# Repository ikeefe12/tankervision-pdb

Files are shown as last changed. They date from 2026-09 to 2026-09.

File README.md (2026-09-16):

# TankerVision Power Distribution Board

A four-layer KiCad power distribution board (PDB) for the TankerVision robot. It
accepts USB-C PD or an 18.5–20 V DC barrel-jack input, maintains a
supercapacitor-backed rail so an onboard NVIDIA Jetson can shut down cleanly after
input loss, and exposes four independently protected, firmware-controlled output
ports.

Designed in KiCad 9.0.7. Revision 1.0 was fabricated and assembled by JLCPCB in
August 2026.

| | |
|---|---|
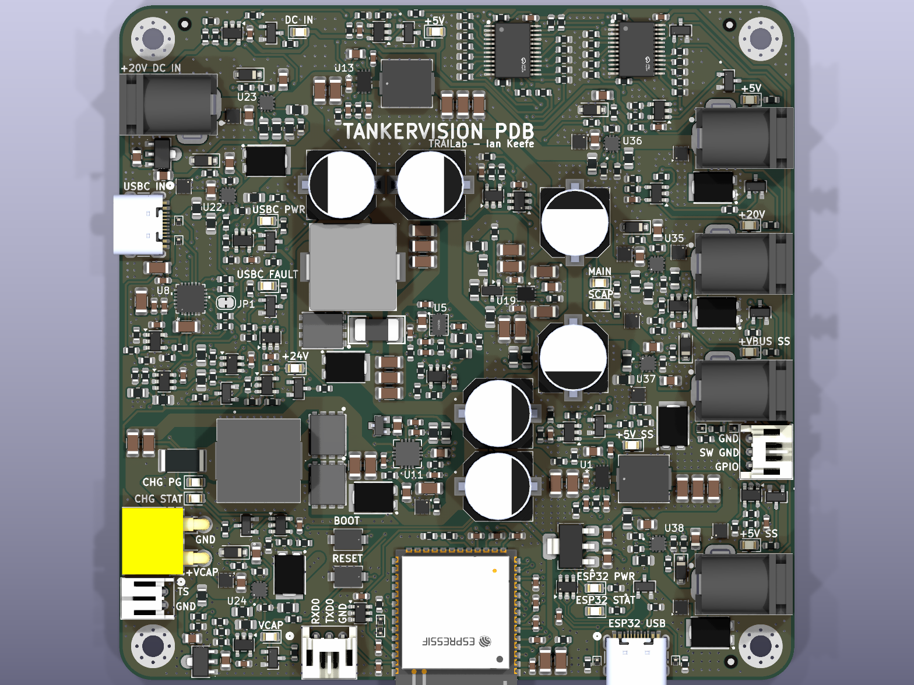
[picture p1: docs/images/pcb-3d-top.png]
PCB top
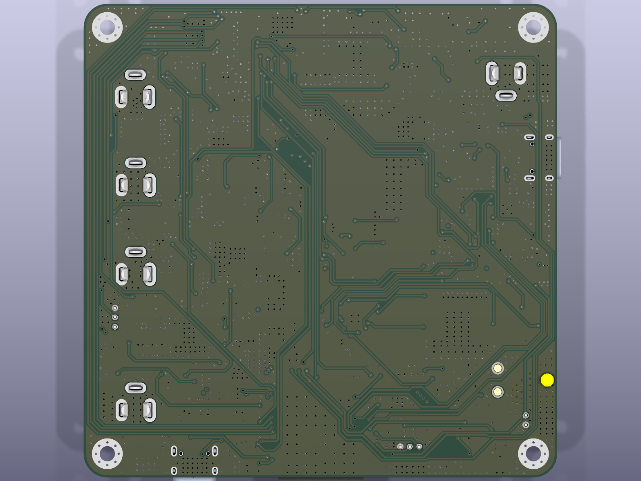
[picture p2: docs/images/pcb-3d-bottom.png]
PCB bottom
|  |  |

## Highlights

- **Dual redundant input** — USB-C PD (CYPD3177 requesting 20 V) and a DC barrel
  jack are ORed through two reverse-blocking LM73100 ideal-diode switches.
- **Supercapacitor backup** — a BQ24640 charges an external bank through a 24.5 V
  LM5155 boost; a TPS2121 priority mux transfers the backed `+VBUS_SS` domain to the
  bank in roughly 5 µs when the input rail collapses.
- **Orderly shutdown** — the backed rails feed the ESP32-S3, which sheds loads,
  pulses the Jetson power button, and watches stored energy on the supercap ADC
  divider to decide when to commit to shutdown.
- **Firmware-independent boot** — input switch → mux IN1 → `+VBUS_SS` → 5 V buck →
  3.3 V LDO brings up the ESP32-S3 with no firmware involvement; every other load
  rail is deliberately under software control.
- **Protected outputs** — four LM73100 output switches provide inrush control,
  reverse blocking, power-good, and current monitoring per port.
- **Full supervision** — fourteen TLV7031 comparators condition status signals and
  two TCA9535 I²C expanders carry enables and status back to the ESP32-S3.

## Board summary

| Item | Value |
|---|---|
| Outline | 100 mm × 100 mm |
| Stackup | 4-layer, 1.6 mm FR-4, 35 µm (1 oz) copper on all layers |
| Planes | In1.Cu solid GND; In2.Cu predominantly GND with selected routing |
| References | 452 in schematic and PCB, matched one-to-one |
| Production BOM | 444 fitted references in 84 orderable groups |
| Input | USB-C PD, or 18.5–20 V DC barrel jack |
| Outputs | 4 protected ports (`+VBUS`, `+5V_VBUS`, `+VBUS_SS`, `+5V_SS`) |
| Controller | ESP32-S3-WROOM-1-N8R8 |

## Documentation

The design is documented per functional block, with schematic labels rather than
drawing coordinates used as the stable way to locate each circuit.

- **[docs/README.md](docs/README.md)** — start here: block index and power-rail table
- **[docs/system-architecture.md](docs/system-architecture.md)** — power flow, control
  and status map, ESP32 pin map, sequencing
- **[docs/pcb-layout.md](docs/pcb-layout.md)** — layout review, stackup, routing,
  fabrication decisions, revision-1.0 order record
- **[docs/issues.md](docs/issues.md)** — open design concerns and pre-deployment
  bench checks
- **[docs/blocks/](docs/blocks/)** — sixteen per-block documents covering USB-PD,
  inrush control, the power mux, the supercap charger and switch, the boost and
  bucks, LDOs, output switches, the ESP32, I/O expanders, comparators, analog
  switches, the Jetson power button, and ADC monitoring

Firmware and board verification:

- **[firmware/deployment/README.md](firmware/deployment/README.md)** — automatic
  startup, supercap maintenance charging, 1 Hz USB telemetry and fixed 60-second
  Jetson shutdown/reboot sequence
- **[firmware/deployment/API.md](firmware/deployment/API.md)** — Jetson USB API,
  with a [Python reference client](firmware/deployment/jetson/README.md)
- **[firmware/deployment/results/upload-2026-09-16/README.md](firmware/deployment/results/upload-2026-09-16/README.md)**
  — verified deployment upload, charging/PG observations and serial reopen results
- **[firmware/board_control_test/README.md](firmware/board_control_test/README.md)**
  — reusable board drivers, bench procedures and historical test results

Generated exports for quick reading without KiCad:

- [docs/exports/tankervision-pdb-schematic.pdf](docs/exports/tankervision-pdb-schematic.pdf)
- [docs/exports/tankervision-pdb-bom.csv](docs/exports/tankervision-pdb-bom.csv)

## Repository layout

```text
hardware/tankervision-pdb/   KiCad project (schematic, PCB, project library tables)
libraries/symbols/           custom symbol libraries (.kicad_sym)
libraries/footprints/        custom footprint libraries (.pretty)
libraries/3dmodels/          custom 3D models referenced by those footprints
docs/                        design documentation, generated exports and renders
firmware/deployment/         ESP32 deployment firmware, Jetson API/client and tests
firmware/board_control_test/  hardware bench firmware, procedures and captured results
manufacturing/rev-1_0/       as-ordered JLCPCB fabrication and assembly package
```

## Opening the project

Requires **KiCad 9.0** or newer.

```sh
git clone https://github.com/ikeefe12/tankervision-pdb.git
cd tankervision-pdb
kicad hardware/tankervision-pdb/tankervision-pdb.kicad_pro
```

The project's `sym-lib-table` and `fp-lib-table` resolve every custom library
through `${KIPRJMOD}/../../libraries/...`, so the libraries load from this
repository with no global KiCad configuration. Standard symbols, footprints, and 3D
models come from the stock KiCad libraries installed with KiCad.

## Design state

Revision 1.0 was ordered from JLCPCB on 2026-08-24. The CAD review finds no
remaining electrical schematic blocker. The firmware records now include successful
converter/port control checks, real-bank charging and backup intervals, and the
first deployment upload with 1 Hz telemetry and same-boot serial reopen on the Mac.
The remaining integration checks in [docs/issues.md](docs/issues.md) include loaded
Jetson shutdown and backup endurance, source hot-plug, thermal validation of the
3.3 V LDO, and output-switch overload cases. The recorded unloaded and MCU-only
checks do not establish those loaded behaviors.

Verification on the current sources with KiCad 9.0.7:

- PCB DRC with schematic parity: 0 violations, 0 unconnected pads, 0 footprint
  errors, 0 parity issues.
- ERC is clean in the KiCad GUI with the project's review exclusions applied.
  Command-line ERC does not apply those exclusions and reports six
  `power_pin_not_driven` items, all of which are the reviewed and accepted cases
  described in the block documentation.

## Credit

Designed by Ian Keefe at TRAILab, University of Toronto Institute for Aerospace
Studies.

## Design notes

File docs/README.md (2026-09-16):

# TankerVision Power Distribution Board (PDB) — Design Documentation

Verified 2026-08-24 against `tankervision-pdb.kicad_sch` and the completed
`tankervision-pdb.kicad_pcb` using KiCad 9.0.7 and fresh ERC and parity-aware PCB
DRC. Calculations also use the active devices' manufacturers' datasheets.

> The 452-reference schematic and 452-footprint PCB match one-to-one, including
> UUIDs, values, footprint assignments, manufacturing fields, and pad nets. ERC
> and PCB DRC are clean with zero unconnected items; the enabled solder-mask bridge
> rule also passes. The revision-1.0 JLCPCB order uses epoxy-filled-and-capped vias,
> and its BOM, placement file, and rendered component orientations pass the final
> manufacturing-package audit. The exact order parameters and the two accepted
> graphics-only connector-footprint exclusions are documented in
> [pcb-layout.md](pcb-layout.md). Complete the bench checks in
> [issues.md](issues.md) before deployment.

## What this board does

The PDB accepts power from USB-C PD or an **18.5–20 V** DC barrel-jack supply.
Two reverse-blocking input switches feed `+VBUS`. A TPS2121
then selects `+VBUS` or an armed supercapacitor bank to supply the backed `+VBUS_SS`
domain. An always-on 5 V buck and 3.3 V LDO boot the ESP32-S3, which controls the
charger, backup switch, auxiliary buck, and four protected output ports through two
TCA9535 expanders.

The intended loss-of-input behavior is a short TPS2121 switchover to the supercap,
followed by firmware-controlled load shedding and an orderly Jetson shutdown.

## Firmware

The [deployment firmware](../firmware/deployment/README.md) implements automatic
charging and maintenance, complete 1 Hz USB telemetry, and Jetson startup and
shutdown coordination. See the [USB API](../firmware/deployment/API.md),
[Jetson reference client](../firmware/deployment/jetson/README.md), and
[deployment upload results](../firmware/deployment/results/upload-2026-09-16/README.md).
The separate [board-control bench firmware](../firmware/board_control_test/README.md)
contains the earlier hardware test procedures and evidence. KiCad sources are in
`hardware/tankervision-pdb/` in this standalone repository.

## Block index

Schematic labels, rather than drawing coordinates, are the stable way to find each
circuit.

| Document | Schematic label(s) | Key parts |
|---|---|---|
| [blocks/usbc-pd.md](blocks/usbc-pd.md) | `USBC PD` | J1, U8 CYPD3177, U2, U3/U4 |
| [blocks/input-inrush.md](blocks/input-inrush.md) | `USBC INRUSH CTRL`, `DC INRUSH CTRL` | U22/U23 LM73100 |
| [blocks/common-lm73100-power-switch.md](blocks/common-lm73100-power-switch.md) | repeated topology | U22–U24, U35–U38 |
| [blocks/power-mux.md](blocks/power-mux.md) | `POWER MUX`, `2V5 VCAP VREF` | U19 TPS2121, U51 LM4040 |
| [blocks/supercap-switch.md](blocks/supercap-switch.md) | `SUPER CAP SWITCH` | U24 LM73100, CN1 |
| [blocks/supercap-charger.md](blocks/supercap-charger.md) | `SUPERCAP CHARGER` | U11 BQ24640, U12/U14 TS5A3159 |
| [blocks/boost-24v.md](blocks/boost-24v.md) | `24.5V BOOST` | U5 LM5155 |
| [blocks/buck-5v.md](blocks/buck-5v.md) | `20V->5V SS BUCK`, `20V->5V BUCK` | U1/U13 TPS51385 |
| [blocks/ldos.md](blocks/ldos.md) | `3V3 VBUS LDO`, `3V3 VCAP LDO`, `3V3 SS LDO` | U48–U50 |
| [blocks/output-switches.md](blocks/output-switches.md) | four output-switch labels | U35–U38 LM73100 |
| [blocks/esp32.md](blocks/esp32.md) | ESP32/support labels | IC1, U17 |
| [blocks/io-expanders.md](blocks/io-expanders.md) | internal/external I²C GPIO | U26/U43 TCA9535 |
| [blocks/comparators.md](blocks/comparators.md) | distributed status conditioning | U4/U6/U7/U15/U16/U18/U27–U30/U44–U47 |
| [blocks/analog-switches.md](blocks/analog-switches.md) | PD-bus gating, ADC isolation, charger selection, mux indication | U3/U9/U12/U14/U25 TS5A3159 |
| [blocks/jetson-power-btn.md](blocks/jetson-power-btn.md) | `JETSON POWER BTN` | J5, Q11 |
| [blocks/adc-monitoring.md](blocks/adc-monitoring.md) | `VCAP ADC DIV` plus IMON networks | R195/R196/R198, U9, D26–D28/D38–D41 |
| [system-architecture.md](system-architecture.md) | — | power flow, control map, pin map, sequencing |
| [pcb-layout.md](pcb-layout.md) | — | final PCB parity, stackup, routing, fabrication decisions |
| [issues.md](issues.md) | — | open design concerns and release checks |

## Power rails

| Net | Source | Nominal | Supercap-backed? | Purpose |
|---|---|---:|:---:|---|
| `+VBUS_USB` | J1 / USB-PD VBUS | 5 V before contract; 20 V requested | — | raw USB input |
| `+VBUS_DC` | J6 | 18.5–20 V required | — | raw DC input |
| `+VBUS` | U22/U23 ideal-diode OR | 18.5–20 V during valid operation | no | main input rail |
| `+24V` | U5 boost | 24.5 V | no | charger input |
| `+VCAP` | U11 / external bank at CN1 | 0–20.63 V target | is backup | raw supercap rail |
| `+VCAP_VALID` | U24 | equals VCAP | — | armed mux IN2 |
| `+VBUS_SS` | U19 mux | VBUS or VCAP | yes | backed root rail |
| `+5V_VBUS` | U13 buck | 5.1 V | no | unbacked 5 V |
| `+5V_SS` | U1 buck | 5.1 V | yes | backed 5 V |
| `+3V3_VBUS` | U49 LDO | 3.3 V | no | VBUS-domain supervision/switch supply |
| `+3V3_VCAP` | U50 LDO | 3.3 V | self | VCAP-domain supervision |
| `+3V3_SS` | U48 LDO | 3.3 V | yes | ESP32, expanders, backed logic |
| `+3V3_PDC` | U8 internal regulator | 3.3 V | no | USB-PD controller domain |
| `+3V3_SCC` | U11 VREF | 3.3 V reference | no | charger ISET/TS networks only |
| `+2V5_VCAP_VREF` | U51 shunt reference | 2.5 V | from VCAP_VALID | mux crossover reference |

`_SS` means downstream of the power mux and therefore available during the intended
safe-shutdown interval. The 3.3 V rails are deliberately separate domains and must
not be treated as interchangeable.

## Repeated circuit patterns

- Seven LM73100 protected switches provide inrush control, reverse blocking, power
  good, and current monitoring. See
  [common-lm73100-power-switch.md](blocks/common-lm73100-power-switch.md).
- Fourteen TLV7031 comparators condition open-drain status signals; U4 converts the
  CYPD3177 active-low PFET gate signal into `VBUS_USB_EN`. See
  [comparators.md](blocks/comparators.md).
- Five TS5A3159 SPDT switches gate the PD-bus pull-ups, isolate `VCAP_ADC`, select
  charger current, select the real/fixed TS network, and steer mux-source LEDs. The
  charge-voltage divider is fixed and has no analog switch. See
  [analog-switches.md](blocks/analog-switches.md).
- Each expander-driven enable has a 49.9 kΩ pulldown. `VCAP_EN` is driven directly
  by ESP32 IO42 and has its own 49.9 kΩ default-low resistor.

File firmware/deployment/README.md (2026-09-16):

# TankerVision PDB deployment firmware

Standalone Arduino ESP32-S3 firmware for `ESP32-S3-WROOM-1-N8R8`, with a USB
protocol for the Jetson. This folder is independent of the historical
`board_control_test` sketch. See [API.md](API.md) for the complete wire protocol,
[jetson/README.md](jetson/README.md) for the reference client and shutdown hook,
and [USB-TRANSPORT.md](jetson/USB-TRANSPORT.md) for USB configuration and upload recovery.

## Operating sequence

1. **Settle for 10 seconds from application uptime zero.** D7 is solid green.
   Initialize the ESP32's monitoring interfaces and USB, hold direct backup GPIO42
   at its default low level, and read the board. Send telemetry every second.
   Leave both expanders' registers untouched until settling finishes. Reads send
   I2C register pointers but do not program their configuration or output data.
2. **Prepare charging.** Read and reconcile retained expander outputs, lowering
   CE before boost and other enables. Select real temperature sensing and the low
   nominal **1.03 A** charge profile. Validate a **20 V / 3 A** USB-PD request,
   then enable boost, wait for PG and qualify the real sensor before enabling CE.
   This preparation also runs with an already charged bank.
3. **Qualify the bank.** Proceed when VCAP is strictly **greater than 20 V**, or
   report a charge issue and proceed after **10 seconds without a meaningful
   rise**. A meaningful rise is at least **0.10 V above the last progress mark**;
   small ADC noise cannot continually restart the timer. A healthy >20 V result
   leaves boost and charger enabled to maintain the bank while the Jetson runs.
   A no-rise result, invalid sensing, temperature/PG/control fault, 21 V ADC trip,
   or two-hour initial-charge limit requests charging shutdown and continues
   startup with the issue retained in telemetry. There is no automatic retry of
   a failed charger in that boot. Maintenance has no charge-progress/time limit;
   temperature, supply, control readback and voltage protection remain active.
4. **Arm backup and start the Jetson.** When valid VCAP is at least 10 V, enable
   GPIO42 and require backup PG. A charging or backup-arm failure does not skip
   the Jetson startup attempt. Enable **J9 / V_BUS_SS / `vbus_ss`**, then ping
   the Jetson every two seconds. A matching reply confirms communication;
   `JET_ON_FB` is recorded independently. Power monitoring does not wait for the
   operating system or USB service to finish booting.
5. **Run.** D7 is a 1 Hz heartbeat (500 ms on/off) after settling. Continue 1 Hz
   telemetry, charger maintenance/health monitoring, pings, and API service.
   Charger faults in this state disable charging and retain Jetson/backup power.
6. **Latch shutdown on main loss or an API reboot request.** Immediately notify
   the Jetson, disable charger CE, then boost after its decay interval. Keep
   backed ports and GPIO42 available during the shutdown allowance. Record the
   Jetson's acknowledgment and final ready message. Neither message changes the
   deadline: it is **60 seconds from the ESP32's original shutdown request**.
   Actual main loss also latches the unbacked J7/J8 outputs off after charger
   cleanup, including J8's converter, so they stay off if main returns. An API
   reboot with uninterrupted main leaves those outputs on until final cutoff.
   Main-power return is reported but ignored for this policy. No API command can
   cancel shutdown or extend the timer, and port changes are rejected during it.
7. **Cut power and restart if still powered.** At the deadline, begin restoring
   both expanders to their power-on defaults, then deassert GPIO42. This final
   cleanup has a 750 ms allowance; an I2C fault cannot hold backup indefinitely.
   If main remains absent, the board loses its supply. If it remains alive for
   250 ms after GPIO42 release, call `esp_restart()` and repeat the 10-second
   startup sequence. This also implements a requested full-system reboot.

The main-loss detector also operates after settling during charger/Jetson startup.
A low `PMUX_ST` directly identifies backup selection; high requires input PG to
establish main power because the mux can also report high with its output Hi-Z.
Invalid expander data is reported instead of being silently treated as fresh.

The heartbeat follows application-loop execution; it is not autonomous PWM that
could keep blinking while the power manager is stuck. USB availability is never
required for startup or timeout processing. USB messages are generated every
second throughout settling, charging, operation and the shutdown allowance;
physical delivery requires a connected host that reads them. No firmware can
deliver USB telemetry while its host is unpowered or its port is closed.

## Board and power assumptions

The schematic/PCB hashes still match the earlier audited version. A fresh KiCad
netlist on **2026-09-16** rechecked all 23 expander connections, all nine ADC
signals, the 82 kΩ/10 kΩ VCAP divider, and seven 820 Ω IMON resistors. J9 is the
backed VBUS Jetson port. J8 is the unbacked 5 V port and its API operation enables
the upstream converter before the port, then disables the port before that buck.

Use the intended **21.6 V rated bank** and real temperature resistor. The charger
hardware target remains approximately **20.629 V**. The requested >20 V / progress
rule is startup qualification; it does not establish full stored capacity. VCAP
is the ADC millivolts scaled by **9.2**, without applying a single-point meter
correction. All seven current channels are now sampled for the requested complete
telemetry; their nominal estimates use **148.42 mV/A**, and remain uncalibrated.

USB input J1 requires a source advertising at least **20 V / 3 A**. Preparation
requests and verifies that allowance; the source advertisement alone is not
accepted. The previous bench procedure used 2 A with unloaded outputs; this build
requests 3 A because maintenance charging and the Jetson can operate together.
The charger can consume roughly 23 W including losses at its low profile. Size
the Jetson power mode and all external loads within the remaining source and
board limits. Firmware does not claim calibrated current-based load protection.

For DC-only input, JP1 must be open and USB-PD power absent, as required by the
board design. The configured DC budget is **3 A** at the permitted 18.5–20 V input;
this is an installation assumption because a DC adapter cannot negotiate or
report its rating. Change that constant to match the actual supply.

Charger failures continue to the J9 startup attempt, but a failed input-budget
verification or failed hardware reconciliation cannot authorize an unchecked
large load: J9 remains off and reports `JETSON_INPUT_BUDGET_UNVERIFIED` or the
hardware error. A degraded bank can also leave insufficient energy for the full
60 seconds under real Jetson load. The deadline is fixed; this version reports
low bank voltage but does not replace the user's deadline with an earlier 7 V
cutoff. Loaded endurance and rail droop require bench measurements.

TCA9535 power-on defaults are input directions `FFFF`, output latches `FFFF`, and
polarity `0000`. The external pulldowns keep controlled enables low when their
pins become inputs. `startRestorePor()` first lowers and verifies driven enables,
then verifies input directions before writing the high output-latch defaults.
GPIO42 is released last. There are no further GPIO/ADC/I2C/PD operations after
release; only bounded USB draining and the possible software restart remain.

An unexpected ESP32-only reset releases GPIO42 but does not reset the expanders.
The requested 10-second settling period leaves any retained expander outputs
untouched until reconciliation. Intended full-system reboot explicitly defaults
the expanders before restarting the ESP32; it is the supported controlled path.

## Build and upload

Validated toolchain: Arduino CLI 0.35.3 with Arduino ESP32 core **3.3.3**. No
third-party Arduino libraries are required.

```sh
sh firmware/deployment/build.sh
```

The build selects USB-OTG/TinyUSB and disables CDC-on-boot. The application creates
its own CDC instance and calls `enableReboot(false)` **before USB starts**. This
disables the Arduino DTR/RTS and 1200-baud reboot hooks that are inappropriate for
the power manager. It avoids the hardware Serial/JTAG mode used by the bench
firmware, where a host reopen was observed to reset the MCU. It does not modify
eFuses. Ordinary CDC open/close and reset behavior must still be confirmed on the
actual Jetson during integration.

Upload with main power present. To enter the ROM downloader from deployment
firmware, hold SW1/BOOT, press and release SW2/RESET, then release BOOT. Find the
ROM serial port and write the generated images, for example:

```sh
python /path/to/esptool.py --chip esp32s3 --port /dev/cu.usbmodem2101 \
  --before no_reset --baud 460800 write_flash --flash_size 8MB \
  0x0000 firmware/deployment/build/deployment.ino.bootloader.bin \
  0x8000 firmware/deployment/build/deployment.ino.partitions.bin \
  0xe000 /path/to/esp32/core/tools/partitions/boot_app0.bin \
  0x10000 firmware/deployment/build/deployment.ino.bin
```

When replacing the older hardware-CDC bench firmware, its existing `--before
usb_reset` upload path is also available. After deployment starts, use the manual
ROM sequence above for subsequent flashing. The USB port identity/path can change
between ROM and application modes. Never initiate flashing/reset while the board
is relying on backup power.

This firmware **starts charging and enables J9 automatically after settling**.
It does not wait for a USB command. The reference Jetson client expects one owner
of J2; its cleanup and OS power-off commands are explicit opt-ins.

## Code organization

| File | Responsibility |
|---|---|
| `PowerManager.h/.cpp` | Pure, allocation-free policy and hardcoded timing/voltage constants; no hardware waits. |
| `BoardHardware.h/.cpp` | Reusable asynchronous converter, charger, backup, port and expander-default operations; ADC/GPIO/register snapshots. |
| `PowerDelivery.h/.cpp` | Read-only CYPD3177 monitoring and staged, verified volatile 20 V/3 A sink request. |
| `Application.cpp` | Integrates policy, hardware operations, LED, complete telemetry, Jetson handshake and final reset. |
| `Protocol.h/.cpp` | Bounded request framing, strict JSON request schema and recent mutation replay cache. |
| `JsonOutput.h` | Bounded JSON construction and USB queue with partial-write continuation and reply capacity. |
| `jetson/pdb_client.py` | Reusable host API, monitor/control CLI, ping replies, acknowledgment and optional cleanup/shutdown workflow. |

All I2C and policy operations run from the main loop. GPIO interrupt handlers only
count edges. I2C transactions have 25 ms timeouts; hardware ramp/settling and PD
stability waits are state transitions rather than `delay()` loops. USB writes
use a bounded 2 ms timeout and continue partial frames without interleaving.
There is no indefinite USB wait, blocking command read, or shutdown-ACK wait.
Per-message sequence, boot ID, uptime, sample age, validity and queue/drop metrics
make gaps and restarts visible. Internal hardware operations and polling can add
bounded scheduling jitter; this is not a hard real-time 1000.000 ms wire clock.

## Validation

Run the host suites without accessing the board:

```sh
sh firmware/deployment/tests/run-power-manager.sh
sh firmware/deployment/tests/run-hardware.sh
sh firmware/deployment/tests/run-protocol.sh
sh firmware/deployment/tests/run-pd.sh
sh firmware/deployment/tests/run-application.sh
python3 -m unittest discover -s firmware/deployment/jetson -p 'test_*.py' -v
```

These cover policy timing and rollover, charger maintenance/failure, real hardware
driver sequencing against register models, strict framing/parser behavior,
negotiated-budget checks, application integration, and the Jetson client. Build
logs and the [final test summary](results/README.md) are under `results/`. These are development
verification results; they do not substitute for a loaded Jetson power test.

For hardware acceptance, first verify 1 Hz telemetry and solid-then-blinking D7,
temperature qualification, charger maintenance, all PG/enables and a matching
Jetson pong. Open/close the application serial port and require the **same boot ID
with increasing uptime**. Then exercise the three user-controlled ports, including
J8 converter sequencing. With adequate charged-bank energy, test main loss and
both Jetson acknowledgment messages, including main return during the grace
period: the shutdown must still complete. Finally issue `reboot` with main present
and verify all ports are off, both expanders reach defaults, the ESP32 gets a new
boot ID, and startup repeats after settling. Record any missing ACK, lost data,
unexpected reset, rail droop or inadequate backup duration as a test failure or
limitation rather than inferring success from D7 alone.

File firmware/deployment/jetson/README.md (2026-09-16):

# Jetson integration example

[`pdb_client.py`](pdb_client.py) implements the [deployment USB protocol](../API.md). It can be imported into the Jetson application or run as a single-owner serial client. Its default action is to print telemetry and answer pings. It never executes host poweroff unless all explicit shutdown options are supplied.

The ESP32 keeps a healthy charger enabled after reaching the initial charge target, maintaining the supercap while main power is present. Charger faults and the fixed shutdown sequence stop charging. The default USB input budget is 20 V/3 A; the installed Jetson, charging demand, optional outputs, and losses must fit the combined budget. The client does not override temperature protection or change charger settings.

Use deployment firmware with TinyUSB CDC reboot hooks disabled before USB startup. The client asserts stable DTR and RTS for that transport; read [USB-TRANSPORT.md](USB-TRANSPORT.md) before using it with the board. Older HWCDC board-test firmware has different reset behavior.

## Install and monitor

Install pyserial in the Python environment that will run the Jetson application:

```sh
python3 -m pip install -r firmware/deployment/jetson/requirements.txt
python3 firmware/deployment/jetson/pdb_client.py \
  --device /dev/serial/by-id/REPLACE_WITH_PDB_DEVICE \
  --log pdb-telemetry.jsonl monitor
```

Use the actual persistent device path from the Jetson. Linux opens are exclusive; stop another serial terminal before starting the client. Stdout and `--log` contain received JSON, while client diagnostics and configured child-command output go to stderr. No module import or test opens a serial device.

Read a snapshot or control an optional output with a standalone client:

```sh
python3 firmware/deployment/jetson/pdb_client.py --device /dev/serial/by-id/REPLACE_WITH_PDB_DEVICE status
python3 firmware/deployment/jetson/pdb_client.py --device /dev/serial/by-id/REPLACE_WITH_PDB_DEVICE port 5v_vbus on
python3 firmware/deployment/jetson/pdb_client.py --device /dev/serial/by-id/REPLACE_WITH_PDB_DEVICE port 5v_vbus off
```

The `port` command waits for the response and asynchronous `port_result`. It exits nonzero on rejection, failed hardware action, or a ten-second result timeout. It does not retry a mutation. `vbus_ss` is the reserved Jetson supply and is deliberately absent from the optional-port commands.

The `reboot` command requests the ESP32's complete fixed 60-second shutdown/restart sequence. It exits after acceptance; it does not claim the Jetson has shut down. A persistent application should issue controls through its existing `PdbClient` instance so it can keep receiving shutdown requests instead of opening a second serial owner.

## Enable a real Jetson shutdown handler

Only run the following configuration on the Jetson that should shut down with this PDB. Provide a cleanup program that stops the application's work, flushes its data, and exits zero on success. It must not itself power off the host; that happens after final readiness is sent.

```sh
python3 firmware/deployment/jetson/pdb_client.py \
  --device /dev/serial/by-id/REPLACE_WITH_PDB_DEVICE \
  --cleanup-command '/usr/local/sbin/tankervision-prepare-shutdown' \
  --cleanup-timeout 45 \
  --poweroff-command '/usr/bin/systemctl poweroff' \
  --allow-host-poweroff monitor
```

The commands are parsed into argument lists and executed without a shell, implicit `sudo`, or privilege escalation. Configure their required permissions on the Jetson. The host cleanup budget is at most 45 seconds and is shortened when reconnecting late in the board's fixed 60-second window.

If the application is already managed by systemd, [`prepare_shutdown.py`](prepare_shutdown.py) is an optional reference cleanup hook. Supply every application service explicitly, for example:

```text
--cleanup-command 'python3 /opt/tankervision/pdb/prepare_shutdown.py --service tankervision.service'
```

The reference hook waits for the named service stop to finish, then runs `sync`, within one 40-second default budget. It does not power off. Missing service arguments, command errors, or a timeout fail cleanup. Adapt the hook if the application needs additional coordination, and keep the USB client in a separate service so stopping the application does not stop its shutdown handshake.

The client immediately ACKs a newly observed shutdown, runs cleanup in a worker so USB reception and pongs continue, then sends final-ready on success. It waits at most one second for the ready response before starting the explicitly configured poweroff command. Cleanup failure, timeout, rejection, a changed boot ID, or a missing ready response prevents this example from starting its poweroff action. The board's cutoff still occurs on schedule.

For protocol testing without shutting down the host, use `--ack-shutdown monitor`. That mode sends ACK once per shutdown but never final-ready or an operating-system poweroff command. Do not treat this mode as a working production shutdown handler.

The example ends on a transport error or device disappearance and does not automatically reopen or reset the ESP32. A service may restart it against the same persistent device identity. Each new client obtains the current boot ID and checks telemetry for a shutdown that began before connection. A retained shutdown is deduplicated within one client process; make the cleanup program idempotent across process restarts.

## Import into an application

The reusable pieces have no implicit serial or operating-system actions:

- `JsonLines.feed(bytes)` provides bounded parsing and recovery after oversized or malformed input.
- `PdbClient(send_bytes, ...)` handles protocol objects and uses a caller-supplied function that writes all bytes or raises.
- `client.receive(message)` processes a complete JSON object, automatically answers pings, and delivers it to `on_message`.
- `client.poll()` handles asynchronous cleanup results and deadlines; call it regularly from the same thread as `receive()` and `request()`.
- `client.request("port_set", port="5v_vbus", enabled=True)` and `client.request("reboot")` return IDs for observing responses. Read at least one valid device message before a mutation so the current boot ID is known.
- `ShutdownHooks(prepare, poweroff, timeout=45)` supplies explicit application callbacks. `prepare(request, timeout)` runs in a daemon worker and returns exactly `True` on success; it must honor its timeout and arrange cancellation of its own subordinate work. `poweroff()` runs only after the matching final-ready response.

The bundled CLI uses `subprocess.run(..., timeout=...)` for cleanup. A timed-out process is killed and waited for by Python; a cleanup script is responsible for any separately detached subprocesses it starts. No client can turn a failed or timed-out cleanup into extra time from the power supervisor.

## Host tests

```sh
python3 -m unittest discover -s firmware/deployment/jetson -p 'test_*.py' -v
```

Tests use in-memory messages, a fake clock, and mocked serial construction. They do not open USB, invoke shutdown commands, or require pyserial. They cover framing recovery, mutation guards, asynchronous port results, continued ping service during cleanup, duplicate shutdown observations, timeout/failure behavior, boot changes, and poweroff opt-in. Hardware transport and loaded Jetson shutdown still require the acceptance checks in [USB-TRANSPORT.md](USB-TRANSPORT.md).

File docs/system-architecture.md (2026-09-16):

# System Architecture

## Power flow

```mermaid
flowchart LR
    USB["J1 USB-C PD"] --> VUSB["+VBUS_USB"] --> U22["U22 USB LM73100"]
    DC["J6 DC input"] --> VDC["+VBUS_DC"] --> U23["U23 DC LM73100"]
    U22 --> VBUS["+VBUS"]
    U23 --> VBUS

    VBUS --> U19["U19 TPS2121 IN1"]
    VBUS --> U13["U13 5 V buck"] --> V5V["+5V_VBUS"] --> U36["U36 output switch"] --> J8
    VBUS --> U35["U35 output switch"] --> J7
    VBUS --> U49["U49 LDO"] --> V3VB["+3V3_VBUS"]
    VBUS --> U5["U5 24.5 V boost"] --> U11["U11 supercap charger"] --> VCAP["+VCAP / CN1"]

    VCAP --> U24["U24 backup arm switch"] --> VVALID["+VCAP_VALID"] -->|IN2| U19
    VCAP --> U50["U50 LDO"] --> V3VC["+3V3_VCAP"]

    U19 --> VSS["+VBUS_SS"]
    VSS --> U37["U37 output switch"] --> J9
    VSS --> U1["U1 5 V buck"] --> V5SS["+5V_SS"]
    V5SS --> U38["U38 output switch"] --> J10
    V5SS --> U48["U48 LDO"] --> V3SS["+3V3_SS / ESP32 / U26 / U43"]
```

The firmware-independent boot path is input switch → U19 IN1 → `+VBUS_SS` → U1 →
`+5V_SS` → U48 → `+3V3_SS`. U1 self-enables when its input is high enough. All
other load rails are intentionally under firmware control.

The completed four-layer implementation, routing/plane review, manufacturing
exports, and accepted fabrication decisions are documented in
[pcb-layout.md](pcb-layout.md).

## Input ORing and USB-PD handoff

U22 and U23 are reverse-blocking LM73100 switches whose outputs share `+VBUS`, so
USB and DC form an ideal-diode OR. The permitted DC adapter range is **18.5–20 V**;
the DC path has nominal 17.50 V rising / 15.90 V falling UVLO guard thresholds.
The USB path is enabled by `VBUS_USB_EN`,
which U4 derives from the U8 CYPD3177 `VBUS_FET_EN` gate signal.

JP1 is a default-closed configuration jumper between U8 `VDC_OUT` and shared
`+VBUS`. Leave it closed for USB-C operation and open it before using the DC input.
USB-C and DC are specified as mutually exclusive sources; JP1 is the required
configuration control that prevents DC from driving an unpowered U8.

## Backup and failover

1. Firmware selects the 1.03 A or 1.94 A charge-current network through U12, leaves
   the real thermistor selected through U14 unless a deliberate service/test override
   is needed, enables U5, and then asserts `SCC_EN` through U26.P11. The U11 VFB divider is fixed at 300 kΩ
   over 34 kΩ for a nominal 20.63 V target.
2. Once `VCAP_ADC` shows adequate stored energy, ESP32 IO42 asserts `VCAP_EN`; U24
   connects the bank to `+VCAP_VALID`, U19 IN2.
3. U19 operates in XREF mode. PR1 is VBUS × 5.62/(34+5.62), compared with the
   2.5 V U51 reference. IN1 is preferred above **17.625 V nominal**; below it the
   mux selects IN2. The source-selection interval is about 5 µs typical, while a
   lower-to-higher-voltage transfer can remain in active current limiting for longer.
4. U30 conditions U19 ST into `PMUX_ST`: high means IN1 or output Hi-Z; low means
   IN2. It reaches ESP32 IO11 through R44 and selects source LEDs through U25.
5. The [deployment firmware](../firmware/deployment/README.md) requests graceful
   Jetson shutdown over USB and grants a fixed 60 seconds before defaulting the
   expanders and releasing backup. Main return cannot cancel this sequence.
   Unbacked outputs are latched off on main loss; backed outputs stay available
   through the allowance. `JET_ON_FB` and `VCAP_ADC` remain telemetry inputs.
   U43.P14 provides a hardware button actuator, but this firmware uses the
   [USB API](../firmware/deployment/API.md) for shutdown coordination.

Only `_SS` rails survive input loss. The charger, boost, `+5V_VBUS`, and
`+3V3_VBUS` correctly disappear with `+VBUS`.

## Control and status map

| Signal | Connection | Function |
|---|---|---|
| `24V_VBUS_EN` | U26.P10 → U5 UVLO/SYNC | boost enable |
| `SCC_EN` | U26.P11 → U11 CE | charger enable |
| `SCC_ISET_SW` | U26.P12 → U12 IN | low = 1.03 A; high = 1.94 A |
| `SCC_TS_SW` | U26.P13 → U14 IN | low = real thermistor; high = fixed override |
| `5V_VBUS_EN` | U26.P14 → U13 EN | unbacked 5 V enable |
| `VCAP_EN` | ESP32 IO42 → U24 EN | direct backup-path arm; R38 default-low |
| internal status ×8 | comparators → U26.P00–P07 | USB/DC/VCAP/charger/boost/buck status |
| external enables ×4 | U43.P10/P11/P12/P13 → U36/U35/U37/U38 | output-port enables |
| external status ×4 | U45/U44/U46/U47 → U43.P03/P04/P02/P01 | output-port power good |
| `JET_PWR_BTN_CTRL` | U43.P14 → Q11 | Jetson button actuator |
| `JET_ON_FB` | J5 → U43.P00 | Jetson state input |
| `PMUX_ST` | U30 → R44 → IO11 | mux source status |
| `PD_INT` | U8 → IO39 | PD-controller interrupt |
| `CTRL_IN_INT_N`, `CTRL_EXT_INT_N` | U26/U43 → IO15/IO16 | expander interrupts |

TCA9535 ports power up as inputs, and the external pulldowns make enables low after
a full board power cycle. Neither expander has a reset pin, so an ESP32-only reset
does not necessarily return existing outputs to safe defaults.

The schematic-verified U26 Port 0 order, P00 through P07, is `PG_DC`,
`5V_VBUS_PG`, `PG_USB`, `SCC_PG`, `SCC_STAT`, `VCAP_PG`, `24V_VBUS_PG`,
`5V_SS_PG`. U43 P00 through P04 are `JET_ON_FB`, `EXT_5V_SS_PG`, `EXT_SS_PG`,
`EXT_VBUS_PG`, `EXT_5V_VBUS_PG`. These correct the earlier documentation; see
[io-expanders.md](blocks/io-expanders.md) for the complete pin tables.

## I²C buses

| Bus | ESP32 | Pull-ups | Devices |
|---|---|---|---|
| `PD_SDA`/`PD_SCL` | IO40/IO41 | R27/R28 2.2 kΩ to U3-gated `+3V3_SS` | U8 CYPD3177 HPI at 0x08 |
| `CTRL_SDA`/`CTRL_SCL` | IO17/IO18 | R35/R36 2.2 kΩ to `+3V3_SS` | U26 internal TCA9535 at 0x20; U43 external TCA9535 at 0x21 |

GPIO35–GPIO37 are no-connect, as required for the fitted N8R8 module's octal PSRAM.
GPIO39–GPIO42 are optional pad-JTAG pins, but the board assigns them to PD HPI and
backup-control functions and retains the default USB Serial/JTAG interface.

## ESP32-S3 pin map

| GPIO | Net / role |
|---|---|
| IO0 | boot strap / SW1 |
| IO1 | `SCC_TS_ADC` |
| IO2 | `VCAP_ADC` through U9 isolation switch |
| IO3 | `VIMON_DC` |
| IO4 | `STAT_LED` |
| IO5 | `VIMON_EXT_5V_VBUS` |
| IO6 | `VIMON_EXT_VBUS` |
| IO7 | `VIMON_EXT_SS` |
| IO8 | `VIMON_5V_SS` |
| IO9 | `VIMON_USB` |
| IO10 | `VIMON_SC` |
| IO11 | `PMUX_ST` through R44 |
| IO12 | unused |
| IO15 | `CTRL_IN_INT_N` |
| IO16 | `CTRL_EXT_INT_N` |
| IO17/IO18 | control I²C SDA/SCL |
| IO19/IO20 | native USB D−/D+ through U17 |
| IO21 | unused / no-connect |
| IO35–IO37 | reserved by octal PSRAM; no-connect |
| IO38 | unused / no-connect |
| IO39 | `PD_INT` |
| IO40/IO41 | PD I²C SDA/SCL |
| IO42 | `VCAP_EN` |
| IO47/IO48 | unused / no-connect |
| RXD0/TXD0 | J3 UART |
| EN | R48 pull-up, C60/SW2 to GND |

IO13, IO14, IO21, IO38, IO45–IO48 are unused. The final pinout avoids all
octal-PSRAM pins. IO3 `VIMON_DC` is also the JTAG-source strap, but the default
eFuse configuration ignores it; firmware must not enable strap-selected pad JTAG.

## Monitoring constants

| Measurement | Nominal transfer |
|---|---|
| `VCAP_ADC` | input × 10/(82+10) = input ÷ 9.2 |
| all `VIMON_*` | current × 181 µA/A × 820 Ω = 0.148 V/A typical |
| `SCC_TS_ADC` | 3.3 V × (NTC ∥ 47 kΩ)/(6.2 kΩ + NTC ∥ 47 kΩ) |

## Intended firmware sequence

1. On boot, read both expanders before writing them; immediately force charger,
   boost, backup, and output enables low unless continuity across reset is intentional.
2. Validate the USB-PD contract and available current before enabling large loads.
3. With `SCC_EN` low, select current and thermistor state. Use the real thermistor
   by default. Enable U5, wait for `24V_VBUS_PG`, then enable U11.
4. Monitor `SCC_PG`, `SCC_STAT`, `VCAP_ADC`, and `SCC_TS_ADC`. Arm U24 only after the
   bank has enough energy by asserting direct `VCAP_EN`; then verify `VCAP_PG` and
   mux behavior.
5. Enable required output rails and monitor their PG and IMON signals.
6. On `PMUX_ST` low, shed loads and begin safe shutdown. Keep `VCAP_EN` asserted
   until the deliberate final power-down point; clearing it while IN2 is active
   immediately removes the board's source.

The lack of an expander-reset connection means U26/U43 outputs can persist across an
ESP32-only reset while `+3V3_SS` remains valid. This retained-state behavior is an
accepted architecture choice; firmware must read and reconcile it. If the ESP32
browns out during backup, direct IO42 `VCAP_EN` releases U24 and returns the board to
its default-off state.

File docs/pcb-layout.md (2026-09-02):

# PCB layout and fabrication review

Verified 2026-08-24 against `tankervision-pdb.kicad_pcb`, the matching schematic,
fresh ERC and parity-aware DRC reports, the revision-1.0 manufacturing archive, the
JLCPCB parts-placement rendering, and a targeted audit of the normally ignored
silkscreen checks using KiCad 9.0.7.

## Final CAD status

- Schematic and PCB each contain 452 unique references. Values, footprints,
  manufacturing fields, primary UUIDs, and normalized pad nets match exactly.
- The production BOM contains 444 fitted references in 84 orderable groups. FID1–
  FID3, JP1, and MH1–MH4 are intentionally excluded from the BOM.
- DRC reports 0 violations, 0 unconnected items, 0 footprint errors, and 0
  schematic-parity issues. ERC reports 0 errors and 0 warnings. In particular,
  `solder_mask_bridge` is enabled at warning severity and reports no violations.
- Gerbers, plated/non-plated drill files, drill maps, the top-side position file,
  and a STEP model export all generate without missing-model or plot errors.
- The ordered revision-1.0 BOM contains the same 444 fitted references and the
  ordered position file contains those references plus FID1–FID3. Every position,
  rotation, and side agrees with the saved PCB after applying the export origin;
  no JLCPCB rotation correction is required.
- The board outline is 100 mm × 100 mm. All fitted parts are on the front side;
  the position export contains the 444 fitted BOM references plus three fiducials.

“Clean DRC” above means the rules currently enabled by the project. The two
intentional footprint-library exclusions, ordered filled-and-capped-via process, and
optional ignored silkscreen checks are documented below.

## Stackup and routing

The saved board is four-layer, 1.6 mm FR-4 with 35 µm (1 oz) copper on all four
layers:

```text
F.Cu / 0.10 mm prepreg / In1.Cu / 1.24 mm core / In2.Cu / 0.10 mm prepreg / B.Cu
```

In1.Cu is an uninterrupted GND plane. In2.Cu is predominantly GND with selected
power/signal routing. The board uses extensive ground stitching and filled ground
zones on both outer layers. Main power paths use 2–3 mm traces and copper zones;
narrow 0.2–0.5 mm branches on those nets are sense or local component connections,
not the intended full-current trunks.

The project minimums are 0.152 mm copper clearance and track width, 0.5 mm
copper-to-edge clearance, 0.6/0.3 mm minimum via diameter/drill, and 0.15 mm minimum
via annular width. The placed routing normally uses 0.3 mm signal traces and
0.7/0.3 mm through vias. The resulting 0.20 mm via annular ring meets the selected
fabricator's published recommended value for a 1 oz multilayer board.

## Critical placement review

- U19 and its input/output capacitors are compact, and the `+VBUS`,
  `+VCAP_VALID`, and `+VBUS_SS` paths use wide copper. The final nominal output
  capacitance remains approximately 241.1 µF.
- U1 and U13 have their high-frequency input capacitors, inductors, output
  capacitors, bootstrap parts, and feedback components grouped tightly around the
  converters. Feedback routing is kept away from the principal switch copper.
- U11, Q4/Q6, L3, R40, and their ceramics form a coherent top-layer power stage.
  SRP and SRN leave the shunt as a paired Kelvin route on B.Cu rather than sharing
  the high-current path. Switching-node copper is localized. Final switching,
  thermal, and EMI validation is still a bench requirement.
- U5, Q1, D1, R9, and L1 have dedicated power copper and nearby ceramics. The
  gate/current-sense and boost switching loop is longer than the smallest possible
  evaluation-module-style placement, so ringing, loss, and EMI must be checked at
  maximum charger power.
- IC1 is at the board edge with its PCB antenna extending beyond the board. The
  short native-USB pair is routed over the In1 ground reference; its approximately
  1 mm length skew is immaterial at ESP32-S3 full-speed USB rates.
- The four grounded M3 mounting holes deliberately connect the mechanical hardware
  to board GND. Integration must treat that as an intentional chassis/enclosure
  bonding choice.

These checks agree with the manufacturers' layout priorities for
[LM5155](https://www.ti.com/lit/ds/symlink/lm5155.pdf),
[BQ24640](https://www.ti.com/lit/ds/symlink/bq24640.pdf), and
[TPS51385](https://www.ti.com/lit/ds/symlink/tps51385.pdf). The antenna placement
also follows Espressif's
[ESP32-S3 PCB-layout guidance](https://docs.espressif.com/projects/esp-hardware-design-guidelines/en/latest/esp32s3/pcb-layout-design.html).

## Fabrication decisions

### 1. Solder-mask bridging is resolved

The board now uses 0.05 mm global solder-mask expansion and a 0.10 mm minimum mask
bridge. Opening merges are explicitly allowed between pads within the same
footprint, which accommodates fine-pitch and custom footprints without globally
suppressing the bridge check. `solder_mask_bridge` is enabled at warning severity;
the current board reports zero bridge violations.

For a 1 oz multilayer board, JLCPCB currently publishes 1:1 pad/opening capability,
a 0.10 mm minimum mask bridge, and at least 0.09 mm between an opening and a
neighboring trace. The final Gerber should still be inspected through the
fabricator's production-file confirmation, as for any dense mask design.

Reference: [JLCPCB PCB capabilities](https://jlcpcb.com/capabilities/Capabilities).

### 2. Epoxy-filled and capped vias were ordered

Via-in-pad use has been reduced. A geometric audit of the current PCB finds 23
0.7/0.3 mm via centers within solderable pad outlines: three in U5's exposed pad,
five in U8's exposed pad, four in U11's exposed pad, and eleven distributed among
smaller pads. The revision-1.0 production order specifies **Epoxy Filled & Capped**
via covering for the board's 1,859 through vias.

JLCPCB describes this process as non-conductive epoxy fill followed by copper
capping. It is the appropriate ordered treatment for the remaining via-in-pad
locations and removes the earlier reliance on ordinary via plugging. Production-
file confirmation remains enabled so any process reinterpretation can be caught
before fabrication.

Reference: [JLCPCB via-covering guidance](https://jlcpcb.com/help/article/pcb-via-covering).

### 3. Two graphical library mismatches are intentionally excluded

DRC contains explicit `lib_footprint_mismatch` exclusions for J1
`CONN12_C-31-M-12_HRO` and J4 `CONN_S2B-PH-K-S_JST`. Their local footprint copies
deliberately adjust the pin-1 indicator. Pad numbers, copper geometry, drills, and
connectivity are unaffected. The two exclusions are intentional for this release
and are not schematic-to-PCB parity errors.

### 4. Silkscreen and test access

The board's functional labels have been updated. J6 is now marked `+20V DC IN`;
the accepted electrical range remains **18.5–20 V**. Enabled `silk_overlap` DRC is
clean.

There are no dedicated `TP*` footprints. The prototype can be probed at connector,
component, or via copper, but the extensive transient-validation plan is easier and
safer with accessible GND plus `+VBUS`, `+VCAP_VALID`, `+VBUS_SS`, `+5V_SS`,
`+3V3_SS`, `PMUX_ST`, and key enable test points. Treat their omission as an
accepted prototype/testability decision if no space remains.

`silk_over_copper` and `silk_edge_clearance` remain ignored. A temporary audit finds
20 mask-clipping and three edge-clipping warnings, mainly footprint outlines and
pin-1 circles. They may be trimmed in the fabricated legend but do not alter copper,
mask openings, assembly placement, or connectivity.

## Revision 1.0 JLCPCB order record

Order placed 2026-08-24 using
`manufacturing/rev-1_0/tankervision-pdb-mfr-rev-1_0.zip`. This records the
order-screen values so the
manufactured configuration can be reproduced. The JLCPCB product-detail screen
reports 110 mm × 100 mm, while the KiCad source outline remains 100 mm × 100 mm;
the order also specifies that JLCPCB adds assembly rails/fiducials, which accounts
for the production-format dimension without changing the source-board outline.

### PCB fabrication

| Parameter | Ordered value |
|---|---|
| Gerber file | `tankervision-pdb-rev-1_0_Y16` |
| Base material / material type | FR-4 / FR4 TG135 |
| Layers / thickness | 4 / 1.6 mm |
| Product-screen dimension | 110 mm × 100 mm |
| PCB quantity / different designs | 5 / 1 |
| Product type | Industrial/Consumer electronics |
| Delivery format | Single PCB |
| Stackup | No requirement; no layer sequence specified |
| Solder mask / silkscreen | Green / white |
| Silkscreen technology | Ink-jet printing |
| Via covering | **Epoxy Filled & Capped** |
| Minimum via hole / diameter | `0.3 mm / (0.4/0.45 mm)` as reported by JLCPCB |
| Via plating method | Horizontal Electroless Copper Plating |
| Surface finish | Lead-free HASL |
| Outer / inner copper | 1 oz / 1 oz |
| Electrical test | Flying Probe Fully Test |
| Appearance quality | IPC Class 2 Standard |
| Production-file confirmation | Yes |
| Mark on PCB | Remove Mark |
| Board-outline tolerance | ±0.2 mm (Regular) |
| Gold fingers / castellations / edge plating | No / No / No |
| Press-fit / blind slot / countersink / backdrill | No / No / No / No |
| Deburring or edge rounding | No |
| 4-wire Kelvin / impedance report / inspection report | No / No / No |
| UL marking | No |
| Paper between PCBs | No |
| Package box | With JLCPCB logo |
| Shortage preference | Require Full Quantity |
| PCB-screen build time / weight | 3 days (PCBA Only) / 0.59 kg |

### PCBA

| Parameter | Ordered value |
|---|---|
| PCBA type / assembly side | Standard / top side |
| PCBA quantity | 5 |
| Panel format | 1 × 1 |
| Edge rails / fiducials | Added by JLCPCB |
| Confirm parts placement | Yes |
| File handling | Complete file; proceed with supplied files |
| Solder paste | High temperature |
| Packaging | Antistatic bubble film |
| Depanel boards and edge rail before delivery | No |
| Bake components / photo confirmation | No / No |
| Board cleaning / conformal coating | No / No |
| Special stencil / stencil storage / fixture storage | No / No / No |
| PCBA flying-probe / function test | No / No |
| Nitrogen reflow | No |
| Assembly remark | No |
| Product description | Research/Education/DIY/Entertainment/DIY; HS code 902300 |
| PCBA-screen build time / weight | 5–6 days / 1.46 kg |

The bare PCB order includes JLCPCB's full flying-probe electrical test. The PCBA
screen separately records no assembly-level flying-probe or functional test; the
assembled boards therefore still require the bring-up procedure in
[issues.md](issues.md).

### JLCPCB placement-rendering audit

The uploaded position file has 447 unique top-side rows: all 444 fitted BOM
references plus FID1–FID3. Its coordinates and rotations match the PCB exactly.
The JLCPCB rendering was then checked against PCB pad numbers, polarity marks, and
connector keying for all 130 orientation-sensitive fitted references:

- IC1 and U1–U51 have their pin-1 marks on the intended PCB pad-1 corners. This
  includes U8 CYPD3177, U11 BQ24640, U19 TPS2121, U22–U24/U35–U38 LM73100, and
  U26/U43 TCA9535.
- Q1–Q18 and D1–D41 agree with their pad-1, cathode, or package-dot markers. The
  green indicators D7 and D25 (`C965815`, XL-2012UGC) have JLCPCB's `+` marker on
  pin 2/anode; the PESD3V3S1UL parts D11 and D17–D19 retain pin 1/cathode on the
  protected signal and pin 2/anode on GND.
- Polarized capacitors C8–C11 and C78/C79 have the rendered `+` on PCB pad 1.
- CN1 has `+VCAP` on pin 1 and GND on pin 2. J1/J6 open toward the left board edge,
  J2 opens toward the bottom edge, J7–J10 open toward the right edge, and the J3–J5
  keying agrees with the footprints and accessible board edges.
- SW1/SW2 and all remaining package dots, cathode bars, LED polarity marks, and
  connector outlines agree with the PCB. Rotated red reference text in JLCPCB's
  viewer is only an overlay and is not a component-orientation indicator.

No reversed, mirrored, or incorrectly rotated fitted component was found in the
provided JLCPCB rendering. The submitted placement may proceed without an
orientation correction.

## Release interpretation

Static connectivity, placement, routing, plane continuity, copper-rule, and
model/export checks pass. The previous solder-mask and functional-silkscreen items
are resolved. The two graphical library exclusions are explicitly accepted, and
the order records epoxy-filled-and-capped vias plus production-file and placement
confirmation. Converter stability, ringing, EMI, thermal rise, hot plug, power-mux
transfer, overload behavior, and firmware sequencing still require the bench tests
listed in [issues.md](issues.md).

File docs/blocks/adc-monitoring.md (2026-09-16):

# VCAP divider and current monitoring

**Schematic label:** `VCAP ADC DIV`; IMON networks are distributed through the
seven LM73100 blocks.

## Supercap-voltage ADC

The former `VBUS_ADC` channel has been removed and ESP32 IO4 is now `STAT_LED`.
`VCAP_ADC` uses:

```text
+VCAP ─ R195 82 kΩ ─┬─ R196 2.2 kΩ ─ U9 NO
                    └─ R198 10 kΩ ─ GND
U9 COM ─┬─ ESP32 IO2
        └─ C50 100 nF ─ GND
U9 IN and V+ ─ +3V3_SS; U9 NC ─ GND
```

The divider scale is `10/(82+10)`, or input ÷9.2. It gives approximately 2.24 V
at the 20.63 V nominal charge target and 3.01 V at the TVS2200 27.7 V maximum
clamp. With 1% divider corners the latter is approximately 3.07 V, below the
ESP32's 3.6 V absolute maximum.

U9 TS5A3159 is powered by `+3V3_SS` and its IN pin is tied high. While powered it
connects the divider to IO2; while unpowered its powered-off protection makes the
signal path high impedance, preventing a charged bank from back-powering the
ESP32. R196 limits residual transient/clamp current.

During the 2026-09-14 unloaded charger hold, the user measured **20.67 V** with a
multimeter while the nominally scaled ESP32 estimate was approximately **20.23 V**.
The measurement path reads about **0.44 V / 2.1% low** at this operating point.
ADC/divider calibration remains outstanding; no correction was applied from this
single comparison. See the [meter hold report](../../firmware/board_control_test/results/hold-2026-09-14/README.md).

## LM73100 IMON channels

All seven channels use an 820 Ω IMON load, a DDZ9678 1.8 V clamp, 2.2 kΩ series
resistor, and 100 nF at the ESP32. Nominal transfer is:

`V_IMON = I × 181 µA/A × 820 Ω = 0.148 V/A`.

| Signal | Source | Load / clamp / series / filter | ESP32 |
|---|---|---|---|
| `VIMON_USB` | U22 | R122 / D26 / R106 / C58 | IO9 |
| `VIMON_DC` | U23 | R124 / D27 / R108 / C53 | IO3 |
| `VIMON_SC` | U24 | R127 / D28 / R110 / C61 | IO10 |
| `VIMON_EXT_VBUS` | U35/J7 | R180 / D39 / R160 / C44 | IO6 |
| `VIMON_EXT_5V_VBUS` | U36/J8 | R177 / D38 / R161 / C39 | IO5 |
| `VIMON_EXT_SS` | U37/J9 | R187 / D41 / R166 / C46 | IO7 |
| `VIMON_5V_SS` | U38/J10 | R181 / D40 / R168 / C49 | IO8 |

LM73100 IMON accuracy is ±15% at or above 1 A, ±20% from 0.5–1 A, and
unspecified below 0.5 A. Calibrate voltage measurements against a DMM, treat small
IMON readings as qualitative, and use filtered/averaged thresholds in firmware.

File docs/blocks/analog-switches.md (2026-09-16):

# TS5A3159 analog switches — final schematic audit

**Key parts:** U3, U9, U12, U14, U25 — TS5A3159ADBVR

All five symbols use the TI DBV pinout and KiCad SOT-23-6 footprint: pin 1 NO,
pin 2 GND, pin 3 NC, pin 4 COM, pin 5 V+, and pin 6 IN. `IN = 0` connects COM to
NC; `IN = 1` connects COM to NO.

Each switch has a local 100 nF V+-to-GND bypass capacitor: U3/C4, U9/C54,
U12/C70, U14/C71, and U25/C89.

The TS5A3159A's powered-off protection keeps its signal-path pins high impedance
with V+ = 0 V. Its control input is also allowed up to 5.5 V independently of V+.
Those properties are required where backed control/analog nodes can outlive the
switch supply.

| Ref | V+ / IN | COM function | IN low → NC | IN high → NO |
|---|---|---|---|---|
| U3 | `+3V3_SS` / divided `+3V3_PDC` | HPI pull-up supply | GND | `+3V3_SS` |
| U9 | `+3V3_SS` / `+3V3_SS` | ESP32 IO2 | GND | `VCAP_ADC` |
| U12 | `+3V3_VBUS` / `SCC_ISET_SW` | U11 ISET | 1.03 A network | 1.94 A network |
| U14 | `+3V3_VBUS` / `SCC_TS_SW` | U11 TS | real J4 thermistor | fixed TS override |
| U25 | `+3V3_SS` / `PMUX_ST` | source-LED supply | D29 red: supercap/IN2 | D25 green: VBUS/IN1 or Hi-Z |

The part's −40 to +85 °C operating range must cover the product ambient range.
If operation above +85 °C is required, choose a wider-temperature part with the
same pinout, powered-off behavior, and analog/control limits.

Primary reference: [TS5A3159A datasheet](https://www.ti.com/lit/ds/symlink/ts5a3159a.pdf).

## U3 — CYPD3177 HPI pull-up gating

R11 10 kΩ from `+3V3_PDC` and R16 100 kΩ to GND drive U3 IN. COM supplies the
top of R26 10 kΩ (`PD_INT`) and R27/R28 2.2 kΩ (`PD_SDA`/`PD_SCL`).

- With `+3V3_PDC` and `+3V3_SS` present, U3 selects NO and the HPI signals pull up
  to `+3V3_SS`.
- With only `+3V3_SS` present, U3 selects grounded NC, holding the unpowered-device
  bus inactive through the pull-up resistors.
- With `+3V3_SS` absent, U3 is unpowered and isolates COM from both throws, so
  `+3V3_PDC` cannot back-power the ESP32 domain through the HPI signals.

This removes the need for firmware to sequence a separate PD-bus enable.

## U9 — `VCAP_ADC` isolation

U9 IN is tied to its `+3V3_SS` supply. When that rail is valid, COM connects ESP32
IO2 to NO and the R195/R198 divider. When the rail is absent, powered-off protection
isolates the charged-bank divider. NC is grounded but is not selected during normal
powered operation.

## U12 — charge-current selection

U12 COM drives `/SS_ISET`. Both selectable dividers use U11's `+3V3_SCC` reference.
With R40 = 10 mΩ and `I_CHG = V_ISET/(20 × R40)`:

| `SCC_ISET_SW` | Divider | ISET | Nominal charge current |
|---:|---|---:|---:|
| 0 | R41 150 kΩ / R45 10 kΩ | 0.206 V | 1.03 A |
| 1 | R42 150 kΩ / R46 20 kΩ | 0.388 V | 1.94 A |

R116 holds IN low while U26.P12 is high impedance, so the hardware default is the
lower current. Switch resistance is negligible relative to the divider resistors;
include leakage and resistor/reference tolerance in final current limits.

## U14 — thermistor/override selection

U14 COM reaches U11 TS through R47 100 Ω; C56 100 nF filters the charger pin.

- IN low/NC selects `SCC_TS_ADC`, the actual J4 sensor network: R62 6.2 kΩ to
  `+3V3_SCC`, R69 47 kΩ to GND, and the external NTC to GND.
- IN high/NO selects R56/R59 = 100 kΩ/100 kΩ, approximately half of
  `+3V3_SCC`, deliberately overriding U11 temperature faults.

R117 holds IN low while U26.P13 is high impedance. The real sensor is therefore the
safe startup/default path. Treat the high state as a controlled diagnostic mode;
the ESP32 ADC is not an independent hardware temperature cutoff.

## U25 — mux-source LEDs

U25 is entirely within the backed `+3V3_SS` domain. U30 drives `PMUX_ST`:

- low selects NC and D29 red, indicating U19 IN2/supercap;
- high selects NO and D25 green, indicating U19 IN1/VBUS or output Hi-Z.

U19 ST does not distinguish IN1 from output Hi-Z, so firmware must combine
`PMUX_ST` with input/status measurements before concluding that VBUS exists.

## Fixed VFB path

U11 VFB is a direct trace to fixed R43/R50 = 300 kΩ/34 kΩ. No analog switch is
present in the feedback loop. This preserves the charger's validated topology and
removes switch leakage, capacitance, resistance variation, and power sequencing
from the regulation node. Both resistors use hand-solderable 0805 footprints so a
future build can fit another fixed target.

## Acceptance checks

- Keep both charger profile selects low before asserting `SCC_EN`.
- Change ISET or TS only with U11 disabled unless the transient is characterized.
- Bench-test loss of `+3V3_VBUS` while the bank remains charged and confirm no
  back-power through U12/U14.
- Verify U3 bus recovery across USB attach/detach and U9 isolation across backed
  rail power-up/down.
- Verify the required ambient range against the +85 °C limit.

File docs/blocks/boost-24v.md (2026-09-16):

# 24.5V BOOST — LM5155 charger supply

**Schematic label:** `24.5V BOOST`

**Key parts:** U5 LM5155, Q1 IPC50N04, L1 6.8 µH, D1 PMEG060V100,
R9 12 mΩ, U6 TLV7031

U5 boosts `+VBUS` to 24.5 V for the supercap charger. The circuit follows TI's
24 V/2 A-class application values but uses a 12 mΩ current-sense resistor; validate
the limit, ripple, magnetics, and thermals over the specified 18.5–20 V source range
and deliberate brownout/invalid-source tests.

| Item | Schematic value / result |
|---|---|
| output | R10/R20 = 47 kΩ/2 kΩ; 1.00 V × (1 + 47/2) = 24.5 V |
| switching frequency | approximately 434 kHz from R17 = 49.9 kΩ |
| nominal peak-current threshold | 100 mV / 12 mΩ = 8.3 A |
| soft start | C30 = 220 nF; 220 nF × 1 V / 10 µA = approximately 22 ms |

Q1 is the low-side switch; R9 is its source shunt; R4/C27 filter CS. D1 rectifies
into the 24 V output. R15/C31/C32 form compensation. The completed PCB gives
Q1/D1/R9/L1 dedicated wide copper, ground stitching, and nearby ceramics. The
gate/current-sense and boost switching loop is still longer than the smallest
possible evaluation-module-style placement, so scope SW/GATE/CS and verify loss,
ringing, EMI, and temperature at maximum charger power.

`24V_VBUS_EN` comes from U26.P10 with R114 49.9 kΩ default-low. U5 PGOOD is pulled
up and conditioned by U6, then drives `24V_VBUS_PG` to U26.P06 and Q2/D2.

Disabling U5 stops switching but does not isolate its output: `+VBUS` still has a
forward path through L1 and D1 to `+24V`, then through D8 to the charger input.
Consequently, charger `SCC_PG` can remain asserted while boost enable and boost PG
are low. Use `24V_VBUS_PG` to check boost regulation, and keep `SCC_EN` low before
disabling the boost.

The charger is the only intended load. At 1.94 A into a nearly full 20.63 V bank,
the stage must supply roughly 40 W plus loss. At the minimum valid 18.5 V input,
that is at least 2.2 A before loss and about 2.4 A at 90% efficiency. Coordinate
this with the negotiated USB contract or DC-source rating.

Primary reference: [LM5155 datasheet](https://www.ti.com/lit/ds/symlink/lm5155.pdf).

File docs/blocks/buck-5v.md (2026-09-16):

# 20V→5V BUCKS — TPS51385 ×2

**Schematic labels:** `20V->5V SS BUCK`, `20V->5V BUCK`

**Key parts:** U1/U13 TPS51385; U7/U18 TLV7031

Both converters produce 5.1 V with a 150 kΩ/20 kΩ feedback divider. The power
stages use 1.5 µH inductors, 3×22 µF output capacitance, 2×10 µF input capacitance,
100 nF soft start, and out-of-audio mode.

| | Backed SS buck | Unbacked VBUS buck |
|---|---|---|
| converter | U1 | U13 |
| input/output | `+VBUS_SS` → `+5V_SS` | `+VBUS` → `+5V_VBUS` |
| enable | R1/R6 30 kΩ/10 kΩ self-enable; approximately 5.2 V on | U26.P14 `5V_VBUS_EN`, R79 default-low |
| PG | U7 → `5V_SS_PG` → U26.P07, Q3/D3 | U18 → `5V_VBUS_PG` → U26.P01, Q10/D16 |

Validated nominal values:

- VOUT = 0.6 V × (1 + 150/20) = 5.1 V.
- Soft start = 100 nF × 0.6 × 1.4 / 5 µA = approximately 16.8 ms
  (C25 for U1, C74 for U13).
- Charging a 2000 µF load to 5.1 V in 16.8 ms is approximately 0.61 A.
- 5 A is the design budget; it is not implied merely by the device's 7 A headline rating.

U1 is on the critical boot path and continues from the supercap after failover until
its input is too low to regulate. `VCAP_PG` remains high below that point, so it is
not a valid low-energy cutoff.

Primary reference: [TPS51385 datasheet](https://www.ti.com/lit/ds/symlink/tps51385.pdf).

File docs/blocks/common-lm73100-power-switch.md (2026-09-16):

# Common circuit: LM73100 protected power switch (7 instances)

The LM73100 is a 2.7–23 V, 5.5 A protected ideal-diode switch with 28 mΩ typical
back-to-back FETs, reverse-current/reverse-polarity protection, adjustable
OVLO/UVLO/PGTH, controlled dV/dt, IMON, and a fixed fast trip.

```mermaid
flowchart LR
    IN["input"] --> TVS["input TVS"] --> SW["LM73100"] --> OUT["output"]
    EN["enable / UVLO"] --> SW
    OUT --> PGTH["PGTH divider"] --> SW
    SW -->|PG| CMP["TLV7031"] --> STATUS["LED + TCA9535"]
    SW -->|IMON| R["820 Ω"] --> ADC["2.2 kΩ + 100 nF · ESP32"]
    R --> Z["1.8 V DDZ9678 clamp"]
```

Reference constants used here are 1.20 V rising and 1.09 V falling for adjustable
thresholds, 2.34 µA typical dV/dt current, and 181 µA/A typical IMON gain.

## Variants

| Variant | OVLO rising/falling | PG rising/falling | dV/dt | Approximate ramp |
|---|---:|---:|---:|---:|
| USB input | 22.84/20.75 V | 17.07/15.51 V | 4.7 nF | controlled slew |
| DC input | 22.14/20.11 V | 17.07/15.51 V | 4.7 nF | controlled slew |
| supercap | 22.84/20.75 V | 4.48/4.07 V | 4.7 nF | ≈47 ms at 20 V |
| VBUS output | 22.84/20.75 V | 17.07/15.51 V | 4.7 nF | ≈47 ms at 20 V |
| backed VBUS output | 22.84/20.75 V | 9.91/9.00 V | 4.7 nF | ≈47 ms at 20 V |
| 5 V output | 7.04/6.40 V | 4.48/4.07 V | 33 nF + 100 Ω | ≈84 ms at 5.1 V |

U23's 464 kΩ/7.15 kΩ/27 kΩ input ladder additionally gives 17.50 V rising /
15.90 V falling UVLO. This provides startup margin for the specified 18.5–20 V DC
adapter range rather than attempting an exact 18.5 V cutoff.

Every instance uses an 820 Ω IMON load:
`V_IMON = I × 181 µA/A × 820 Ω = 0.148 V/A` typical. Accuracy is ±15% at or above
1 A, ±20% from 0.5–1 A, and unspecified below 0.5 A. The 1.8 V clamp protects the
IMON/ADC node; do not infer precise low-current measurements.

## Instance map

| Ref | Label | Input → output | Enable | IMON / ESP32 | PG destination |
|---|---|---|---|---|---|
| U22 | `USBC INRUSH CTRL` | `+VBUS_USB` → `+VBUS` | U4 `VBUS_USB_EN` | R122 / IO9 | U27 → U26.P02 |
| U23 | `DC INRUSH CTRL` | `+VBUS_DC` → `+VBUS` | resistor UVLO | R124 / IO3 | U28 → U26.P00 |
| U24 | `SUPER CAP SWITCH` | `+VCAP` → `+VCAP_VALID` | ESP32 IO42 | R127 / IO10 | U29 → U26.P05 |
| U35 | `VBUS POWER SWITCH` | `+VBUS` → J7 | U43.P11 | R180 / IO6 | U45 → U43.P03 |
| U36 | `5V VBUS POWER SWITCH` | `+5V_VBUS` → J8 | U43.P10 | R177 / IO5 | U44 → U43.P04 |
| U37 | `SS POWER SWITCH` | `+VBUS_SS` → J9 | U43.P12 | R187 / IO7 | U46 → U43.P02 |
| U38 | `5V SS POWER SWITCH` | `+5V_SS` → J10 | U43.P13 | R181 / IO8 | U47 → U43.P01 |

Input/output TVS parts protect all four external ports. Reverse blocking is what
makes U22/U23 ORing and output-port backfeed protection work. The 100 kΩ PG
pull-ups and 1.5 V U27/U28 thresholds also produce a valid low indication when an
individual input-side switch is unpowered; see
[comparators.md](comparators.md#input-pg-unpowered-state).

The 5.5 A continuous rating is not a programmable 5.5 A current limiter. The fixed
fast trip is approximately 21.9 A and latches the channel off. This behavior is an
accepted design constraint: size/fuse connectors and harnesses for their real load,
and bound any firmware retry of a latched output.

Primary reference: [LM7310/LM73100 datasheet](https://www.ti.com/lit/ds/symlink/lm7310.pdf).

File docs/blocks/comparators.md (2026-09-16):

# TLV7031 comparators — logic and reliability audit

**Key parts:** U4/U6/U7/U15/U16/U18/U27–U30/U44–U47 — TLV7031DBVR

## Result

All fourteen instances use the correct DBV pinout: pin 1 OUT, 2 GND, 3 IN+,
4 IN−, and 5 V+. Their normal-state logic is valid. TLV7031 is a good fit for
slow status conditioning: 1.6–6.5 V supply, rail-to-rail/fault-tolerant inputs,
push-pull output, internal hysteresis, and power-on reset that holds OUT low until
the supply is valid.

Every instance has a dedicated 100 nF V+-to-GND bypass capacitor using the common
0603 BOM part (LCSC `C14663`): U4/C19, U6/C28, U7/C29, U15/C72, U16/C73,
U18/C76, U27/C94, U28/C96, U29/C97, U30/C100, U44/C117, U45/C116, U46/C118,
and U47/C119.

U4's `VBUS_USB_EN` polarity and static margins are valid, and R8 gives the signal a
board-level 49.9 kΩ default-low state. The design accepts that this single enable
path is not single-fault tolerant.

Primary references: [TLV7031 datasheet](https://www.ti.com/lit/ds/symlink/tlv7031.pdf)
and [TLV7031-Q1 product](https://www.ti.com/product/TLV7031-Q1).

## Part suitability

| Characteristic | Limit | Board use | Result |
|---|---:|---:|---|
| Supply | 1.6–6.5 V | 3.3 V domains | pass |
| Recommended common mode | GND to V+ + 0.1 V | rail-like status; U4 below 2.3 V | pass |
| Inputs with V+ = 0 | fault tolerant to 7 V | divider/status nodes can outlive supply | pass |
| Offset | ±8 mV max, −40 to 125 °C | U4 static margin ≥ about 188 mV | pass |
| Hysteresis | 2/7/17 mV min/typ/max at 25 °C | ample for status levels | pass |
| Delay | 3 µs typical at 100 mV overdrive; no max | status/control indication | characterize transients |
| Power-up | OUT held low until supply valid; about 200 µs startup | default-low control/status | favorable |
| Temperature | −40 to 125 °C | system ambient TBD | pass if within range |

The catalog DBVR part is not redundant or functionally safe merely because it is
electrically suitable. TLV7031-Q1 improves qualification, not architecture-level
fault tolerance.

## Shared status topology

```mermaid
flowchart LR
    RAW["open-drain PG / STAT / ST"] --> CMP["TLV7031"]
    V33["local 3.3 V"] -->|"100 kΩ pull-up"| RAW
    V33 -->|"120 kΩ / 100 kΩ"| REF["about 1.50 V"] --> CMP
    CMP --> LED["2N7002 + LED"]
    CMP -->|"5.1 kΩ"| GPIO["TCA9535 input"]
    GPIO -->|"49.9 kΩ"| GND
```

The 120 kΩ/100 kΩ reference is 1.50 V nominal. A high comparator output reaches
the expander through 5.1 kΩ against 49.9 kΩ, about 0.907 × VOH, with comfortable
logic margin.

## Instance map and polarity

| Ref | Raw input | Output / destination | Meaning when high |
|---|---|---|---|
| U4 | `+VBUS_USB/21` on +; `VBUS_FET_EN/11` on − | `VBUS_USB_EN` → U22 EN | U8 gate signal active/low |
| U6 | U5 PGOOD on + | `24V_VBUS_PG` → U26.P06 | boost good |
| U7 | U1 PG on + | `5V_SS_PG` → U26.P07 | backed buck good |
| U15 | 1.5 V on +; U11 active-low PG on − | `SCC_PG` → U26.P03 | charger input good |
| U16 | 1.5 V on +; U11 active-low STAT on − | `SCC_STAT` → U26.P04 | STAT sinking; blink polarity inverted |
| U18 | U13 PG on + | `5V_VBUS_PG` → U26.P01 | unbacked buck good |
| U27 | U22 PG on + | `PG_USB` → U26.P02 | USB switch good while powered |
| U28 | U23 PG on + | `PG_DC` → U26.P00 | DC switch good while powered |
| U29 | U24 PG on + | `VCAP_PG` → U26.P05 | backup switch output above PGTH |
| U30 | U19 ST on + | `PMUX_ST` → IO11/U25 | IN1 selected or mux output Hi-Z |
| U44 | U36 PG on + | `EXT_5V_VBUS_PG` → U43.P04 | 5 V VBUS port good |
| U45 | U35 PG on + | `EXT_VBUS_PG` → U43.P03 | VBUS port good |
| U46 | U37 PG on + | `EXT_SS_PG` → U43.P02 | SS port good |
| U47 | U38 PG on + | `EXT_5V_SS_PG` → U43.P01 | 5 V SS port good |

`PMUX_ST` high is not uniquely "VBUS present": U19 also reports high when its
output is Hi-Z. Firmware must combine it with input and PG information.

## U4 and `VBUS_USB_EN`

```mermaid
flowchart LR
    VBUS["+VBUS_USB"] --> R2["R2 200 kΩ"] --> VP["U4 IN+ · VBUS/21"]
    VP --> R7["R7 10 kΩ"] --> GND
    GATE["U8 VBUS_FET_EN"] --> R21["R21 100 kΩ"] --> VM["U4 IN− · gate/11"]
    VM --> R14["R14 10 kΩ"] --> GND
    VP --> U4["U4"]
    VM --> U4
    U4 --> EN["VBUS_USB_EN"] --> U22["U22 EN"]
    EN --> R8["R8 49.9 kΩ"] --> GND
```

| State | IN+ | IN− | U4 OUT / U22 |
|---|---:|---:|---|
| no valid contract, gate near VBUS | VBUS/21 | VBUS/11 | low / off |
| valid contract, gate near 0 V | VBUS/21 | approximately 0 V | high / enabled |
| U4 supply below POR threshold | — | — | low / off |

At 5 V the nominal no-contract margin is about 216 mV and valid-contract margin is
about 238 mV. Including 1% divider extremes and gate-driver resistance, the smaller
margin remains about 188 mV, well above offset and hysteresis. The highest expected
comparator input remains within its 3.3 V common-mode range.

### Accepted failure behavior

| Fault | Likely outcome |
|---|---|
| U4 unpowered/missing or output open | R8 holds U22 off |
| U4 stuck low; R2 open; R7 short | USB unavailable, fail-off |
| U4 stuck high; R21 open; R14 short | U22 can enable before a valid contract |
| divider short exposing raw VBUS | U4 input overstress risk |

This low-probability single-fault limit is accepted. The board does not claim a
second independent contract/minimum-voltage interlock.

## Input-PG unpowered state

U27/U28 and the R112/R118 PG pull-ups are powered by shared `+3V3_VBUS`, while
U22/U23 operate from the individual USB/DC input domains. The LM73100 specifies a
maximum 0.9 V deasserted PG voltage at 26 µA when its input is below UVP and EN is
in shutdown. At 0.9 V, each 100 kΩ pull-up supplies only
`(3.3 V - 0.9 V) / 100 kΩ = 24 µA`. This is within the specified condition and
remains comfortably below the approximately 1.5 V U27/U28 reference.

An absent input therefore produces low `PG_USB` or `PG_DC` even while the other
source keeps `+3V3_VBUS` alive. A high signal means the corresponding LM73100 has
released PG after its power path is fully on and its PGTH condition is satisfied.
U8 contract state is still the authority for negotiated USB-PD details, but no
additional detector is required to prevent an unpowered-PG false high.

## Bench acceptance tests

- Exercise valid 20 V contracts, incompatible sources, hard/soft reset, detach,
  cable reversal, and brownout. Confirm `VBUS_USB_EN` never glitches high early.
- Verify USB-only with JP1 closed and DC-only with JP1 open; the inputs are not
  intended to be powered simultaneously.
- Verify every conditioned status at the raw pin, comparator output, LED, and
  expander, including U11 STAT blinking and U19 IN1/IN2/Hi-Z states.

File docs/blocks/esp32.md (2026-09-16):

# ESP32-S3 and support circuits

**Schematic labels:** `ESP32-S3`, `ESP32 LEDs`, `BOOT + RESET`,
`USB-C->ESP32 (NO PWR)`, `ESP32 UART0`

**Key parts:** IC1 ESP32-S3-WROOM-1-N8R8, U17 USBLC6-2SC6, J2/J3, SW1/SW2

IC1 runs from backed `+3V3_SS`. Local 100 nF/10 µF decoupling is present. EN uses
R48 5.1 kΩ to `+3V3_SS`; C60 10 µF and SW2 pull it low. SW1 pulls IO0 low for boot
mode. The N8R8 module reserves IO35–IO37 for octal PSRAM; all three are no-connect
in the final schematic.

## Interfaces

- J2 is USB data only. R57/R58 provide 5.1 kΩ Rd on CC; D14/D15 protect CC; U17
  protects D+/D− before IO19/IO20. J2 VBUS biases the ESD device but does not power
  the board.
- J3 exposes RXD0, TXD0, and GND. D17/D18 are PESD3V3 clamps.
- D9 is the red `+3V3_SS` power LED. IO4 `STAT_LED` drives Q5/D7 green with R37
  holding the gate low by default.

Nine analog signals use ADC1-capable IO1–IO3 and IO5–IO10; IO2 receives isolated
`VCAP_ADC`, while IO4 is the digital `STAT_LED`. IO11 is `PMUX_ST` through R44/R49,
IO42 directly drives `VCAP_EN`, and IO12 is unused. Control I²C is on IO17/18, PD
HPI I²C is on IO40/41, expander interrupts are on IO15/16, and `PD_INT` is on IO39.
See [system-architecture.md](../system-architecture.md) for the complete pin map.

**Pinout result:** GPIO35–GPIO37 remain no-connect, `CTRL_SDA`/`CTRL_SCL` are on
GPIO17/GPIO18, the control-bus interrupts are on GPIO15/GPIO16, and the PD HPI bus
and interrupt are on GPIO40/GPIO41 and GPIO39. All assignments are valid for N8R8,
and all nine analog inputs remain on ADC1 GPIO1–GPIO10.

GPIO39–GPIO42 double as optional pad-JTAG signals. They are committed here to
`PD_INT`, PD I²C, and `VCAP_EN`, so do not select pad JTAG in firmware/eFuses. IO3
`VIMON_DC` is also the JTAG-source strapping input, but the
default eFuse configuration ignores that strap. Do not program the JTAG-selection
eFuses in a way that makes its analog level control the debug path. The default USB
Serial/JTAG path remains available through J2.

On the completed PCB the module antenna extends beyond the board edge, with no board
copper beneath the radiating end. The short IO19/IO20 native-USB route is referenced
to the solid In1 GND plane. Preserve antenna clearance in the enclosure and verify
RF performance in the assembled product.

The fitted N8R8 module is specified for −40 to +65 °C ambient by default. Espressif
permits operation to +85 °C when PSRAM ECC is enabled, at the cost of 1/16 of usable
PSRAM. Treat +65 °C as the board limit unless that firmware/configuration choice is
made and validated.

Because U26/U43 remain powered from the same backed rail, resetting IC1 does not
reset their outputs. Charger and port enables therefore need deliberate retained-
state handling; see [issues.md](../issues.md).

Primary reference: [ESP32-S3-WROOM-1/1U datasheet](https://documentation.espressif.com/esp32-s3-wroom-1_wroom-1u_datasheet_en.pdf).

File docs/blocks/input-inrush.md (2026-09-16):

# USBC INRUSH CTRL and DC INRUSH CTRL

**Key parts:** U22/U23 LM73100, U2/U20 TVS2200, J1/J6

The two [LM73100 switches](common-lm73100-power-switch.md) join at `+VBUS`. Their
back-to-back FETs block reverse current, forming an ideal-diode OR without feeding
one connector from the other.

## USB path — U22

- `+VBUS_USB` → U22 → `+VBUS`.
- `VBUS_USB_EN` from U4 controls EN; R8 holds it low if U4 is open/unpowered.
- R86/R102 set 22.84/20.75 V OVLO; R82/R91 set 17.07/15.51 V PGTH.
- C95 4.7 nF controls output slew.
- IMON uses R122 and reaches IO9 as `VIMON_USB`; U27 produces `PG_USB` for U26.P02
  and Q12/D22.

The separate USB-PD document covers the CYPD3177 gate logic and JP1 configuration.

## DC path — U23

- The permitted J6 adapter range is **18.5–20 V**. `+VBUS_DC` has C83 1 µF and
  U20 TVS2200.
- R83/R92/R103 form the shared UVLO/OVLO ladder: 17.50/15.90 V UVLO and
  22.14/20.11 V OVLO. These thresholds provide guard bands around the adapter
  requirement; they are not exact 18.5 V and 20 V cutoffs.
- R84/R93 set 17.07/15.51 V PGTH; C98 4.7 nF controls output slew.
- IMON uses R124 and reaches IO3 as `VIMON_DC`; U28 produces `PG_DC` for U26.P00
  and Q13/D23.

The LM73100 handles reverse-polarity input without a series diode. Hot-plug overshoot
still depends on the supply/cable inductance and capacitor ESR and must be tested at
J6/U20/U23.

The conditioned PG inputs indicate that the corresponding input switch is on and
its PG threshold is met. The 100 kΩ pull-ups and comparator thresholds are sized
to read low for an absent input; see
[comparators.md](comparators.md#input-pg-unpowered-state).

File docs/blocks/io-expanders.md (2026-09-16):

# I²C → GPIO EXPANDERS — internal and external control

**Schematic labels:** `I2C -> GPIO INTERNAL CONTROL`, `I2C -> GPIO EXTERNAL CONTROL`

**Key parts:** U26/U43 TCA9535, powered by `+3V3_SS`

The pin tables below were corrected on 2026-09-14 using a fresh KiCad schematic
netlist and the saved PCB pad nets. Earlier documentation had several Port 0
inputs in the wrong order. The input signals pass through 5.1 kΩ series resistors;
trace across those resistors when checking their unnamed expander-side nets.

Both devices share `CTRL_SDA`/`CTRL_SCL` with R35/R36 2.2 kΩ pull-ups. The final
schematic connects them to ESP32 IO17/IO18. GPIO35–GPIO37 remain no-connect for the
N8R8 module's octal PSRAM.

U26 has A0–A2 low and uses address 0x20. U43 has A0 high and A1/A2 low and uses
0x21. TCA9535 has no internal pull-ups and no reset input. External 49.9 kΩ
pulldowns define safe enable states after a full expander power cycle.

## U26 — internal, 0x20

INT is `CTRL_IN_INT_N` → IO15, pulled up by R77 10 kΩ.

| Pin | Signal | Direction / meaning |
|---|---|---|
| P00 | `PG_DC` | input, DC switch PG |
| P01 | `5V_VBUS_PG` | input, unbacked buck PG |
| P02 | `PG_USB` | input, USB switch PG |
| P03 | `SCC_PG` | input, charger PG |
| P04 | `SCC_STAT` | input, charger status |
| P05 | `VCAP_PG` | input, backup switch PG |
| P06 | `24V_VBUS_PG` | input, boost PG |
| P07 | `5V_SS_PG` | input, backed buck PG |
| P10 | `24V_VBUS_EN` | output, U5 enable |
| P11 | `SCC_EN` | output, U11 CE |
| P12 | `SCC_ISET_SW` | output; low 1.03 A, high 1.94 A |
| P13 | `SCC_TS_SW` | output; low real NTC, high fixed override |
| P14 | `5V_VBUS_EN` | output, U13 enable |
| P15–P17 | unused | — |

`VCAP_EN` is no longer an expander output; ESP32 IO42 drives U24 directly.

## U43 — external, 0x21

INT is `CTRL_EXT_INT_N` → IO16, pulled up by R137 10 kΩ.

| Pin | Signal | Direction / meaning |
|---|---|---|
| P00 | `JET_ON_FB` | Jetson-state input |
| P01 | `EXT_5V_SS_PG` | U38 backed 5 V output status input |
| P02 | `EXT_SS_PG` | U37 backed VBUS output status input |
| P03 | `EXT_VBUS_PG` | U35 VBUS output status input |
| P04 | `EXT_5V_VBUS_PG` | U36 5 V VBUS output status input |
| P10 | `EXT_5V_VBUS_EN` | U36 5 V VBUS output enable |
| P11 | `EXT_VBUS_EN` | U35 VBUS output enable |
| P12 | `EXT_SS_EN` | U37 backed VBUS output enable |
| P13 | `EXT_5V_SS_EN` | U38 backed 5 V output enable |
| P14 | `JET_PWR_BTN_CTRL` | Jetson-button output |
| P05–P07/P15–P17 | unused | — |

## Reset behavior

Ports power up as inputs. An ESP32-only reset does not reset either expander because
`+3V3_SS` remains powered and there is no reset pin. Existing outputs—including
`SCC_EN`, the TS override, and external-port enables—can persist. This behavior is
accepted; firmware must read and deliberately reconcile both devices after reset.
A full rail power cycle returns ports to inputs, where the external pulldowns
establish default-low enables. See [issues.md](../issues.md).

Primary reference: [TCA9535 datasheet](https://www.ti.com/lit/ds/symlink/tca9535.pdf).

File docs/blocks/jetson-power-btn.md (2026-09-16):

# JETSON POWER BTN — remote button and state sense

**Schematic label:** `JETSON POWER BTN`

**Key parts:** J5, Q11, D11/D19, R153/R146/R173

J5 lets firmware request an orderly Jetson shutdown and observe a 3.3 V-compatible
power-state signal.

```text
J5.1 JET_ON_FB ── D11 ESD ── GND
                 └ R146 5.1 kΩ ─┬─ U43.P00
                                  └─ R173 49.9 kΩ ── GND

J5.2 PWR_BTN* ─── Q11 drain; Q11 source ── GND
                 └ D19 ESD ── GND
Q11 gate ── JET_PWR_BTN_CTRL from U43.P14; R153 49.9 kΩ to GND
J5.3 GND
```

R146/R173 scale `JET_ON_FB` by 49.9/(5.1+49.9), approximately 0.907, and R173
defines the expander input low when the external signal is absent.

Q11 is an open-drain button press, so the PDB does not drive a voltage into an
unpowered Jetson. A high U43.P14 state presses the active-low button. Firmware should
use a characterized momentary pulse for shutdown, reserve a long press for fault
recovery, and verify state using `JET_ON_FB`.

Verify J5 pinout and acceptable sense voltage against the exact Jetson carrier and
harness. This block is control only; Jetson power comes through one of the protected
output ports.

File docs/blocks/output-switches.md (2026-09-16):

# OUTPUT POWER SWITCHES — four switched jacks

**Schematic labels:** `VBUS POWER SWITCH`, `5V VBUS POWER SWITCH`, `SS POWER SWITCH`,
`5V SS POWER SWITCH`

**Key parts:** U35–U38 LM73100; J7–J10; U31–U34 input TVS; U39–U42 output TVS

All four are instances of the
[common LM73100 circuit](common-lm73100-power-switch.md). U43 controls them and
49.9 kΩ pulldowns hold every enable low while its expander pin is high impedance.

| Port | Switch | Rail → connector | Backed? | EN / PG / IMON |
|---|---|---|:---:|---|
| VBUS | U35 | `+VBUS` → J7 `VBUS_OUT` | no | U43.P11 / U43.P03 via U45 / IO6 |
| 5 V VBUS | U36 | `+5V_VBUS` → J8 `+5V_VBUS_OUT` | no | U43.P10 / U43.P04 via U44 / IO5 |
| SS | U37 | `+VBUS_SS` → J9 `+VBUS_SS_OUT` | yes | U43.P12 / U43.P02 via U46 / IO7 |
| 5 V SS | U38 | `+5V_SS` → J10 `+5V_SS_OUT` | yes | U43.P13 / U43.P01 via U47 / IO8 |

The 20 V ports use TVS2200; the 5 V ports use TVS0500. D30–D33 clamp negative
output excursions. LEDs D35/D34/D36/D37 show VBUS/5 V VBUS/SS/5 V SS power-good.

J8 requires U13 to be enabled first through U26.P14 `5V_VBUS_EN`. Wait for
U26.P01 `5V_VBUS_PG` before enabling U36, then verify U43.P04
`EXT_5V_VBUS_PG`. Disable U36 before stopping its upstream buck.

Both 20 V ports use 22.84/20.75 V OVLO and an approximately 47 ms ramp. U35 uses
17.07/15.51 V PGTH on the unbacked VBUS port; U37 uses 9.91/9.00 V PGTH so the
backed VBUS port remains indicated across more of the supercap discharge range.
U36 and U38 both use 7.04/6.40 V OVLO, 4.48/4.07 V PGTH, and an approximately
84 ms ramp.

Design notes:

- 5.5 A is a device ceiling, not a guaranteed connector/system rating. Include
  switch dissipation, copper, connector, source, and mux/buck limits.
- `VBUS_OUT` can be anywhere in the accepted input range; its load must tolerate it.
- J6 and J7–J10 use the same PJ-202AH connector. A supply inserted into a 5 V output
  can overstress the TVS0500 even though U36/U38 block reverse current into the board.
- LM73100's 5.5 A continuous rating is not a precise output current limit. Its
  approximately 21.9 A fixed fast trip/latch-off behavior is accepted; rate/fuse
  external loads and bound firmware retries accordingly.

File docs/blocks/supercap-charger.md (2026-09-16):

# SUPERCAP CHARGER — BQ24640 fixed-voltage charger

**Schematic label:** `SUPERCAP CHARGER`

**Key parts:** U11 BQ24640, Q4/Q6, L3, R40, U12/U14 TS5A3159,
U10 TVS2700, J4 thermistor connector

## Function

U11 converts boosted `+24V` into a synchronous CC/CV charge for the external bank
at CN1. The fixed target is 20.63 V. Firmware selects 1.03 A or 1.94 A charge
current and normally uses the real thermistor; a fixed TS override is retained for
controlled diagnostics.

The previous programmable VFB switch/digipot is absent. VFB is a direct trace to the
fixed divider, matching the charger configuration validated by the designer.

## Power stage

- `+24V` passes through D8 to `/VBUS_SCC`; Q4/Q6 and L3 10 µH form the synchronous
  buck stage. R40 = 10 mΩ is the SRP/SRN current shunt.
- D8 prevents the charged bank from feeding the boost output when U5 is off.
- U10 TVS2700 protects `+24V`. R33 10 Ω/C42 1 µF filter U11 VCC; REGN and
  bootstrap components follow the BQ24640 application topology.
- The completed PCB keeps Q4, Q6, C48, L3, R40, and the input/output ceramics in a
  coherent top-layer power stage with localized switch-node copper. SRP/SRN leave
  R40 as a paired Kelvin route on B.Cu rather than sharing the high-current path.
  Scope PH, gate drive, charge current, and VFB and validate EMI/temperature under
  maximum-power charging.

## Fixed charge voltage

R43 = 300 kΩ from `+VCAP` to `/SCC_VFB`; R50 = 34 kΩ from `/SCC_VFB` to GND.
Both are ±0.1%, ±25 ppm/°C precision 0805 parts:

`V_TARGET = 2.1 V × (1 + 300/34) = 20.629 V`.

There is no feed-forward capacitor across R43. The final route keeps VFB away from
the principal switch-node copper; validate loop stability and transient response
with the real bank cable and bank ESR.

Including the BQ24640 ±0.7% full-temperature feedback specification, initial
resistor tolerance, VFB leakage, and conservative independent temperature drift
gives an estimated **20.36–20.94 V** charge range.

The charger OVP decision shares VFB. The accepted system architecture adds
independent ESP32 monitoring through the isolated `VCAP_ADC` path; the external bank
provides cell balancing and temperature protection, and its wiring includes a fuse
close to the stored-energy source.

## Charge-current selection

U12 defaults low through R116:

| `SCC_ISET_SW` | Divider from `+3V3_SCC` | Nominal current |
|---:|---|---:|
| 0 | R41 150 kΩ / R45 10 kΩ | 1.03 A |
| 1 | R42 150 kΩ / R46 20 kΩ | 1.94 A |

These use `I_CHG = V_ISET/(20 × R40)`. The higher setting is approximately 40 W
into a full bank before losses and must remain within the boost, switch, source,
thermal, inductor, connector, and negotiated USB-contract budgets.

The two settings create about 10.3 mV and 19.4 mV across R40. TI specifies current
accuracy at discrete 5/20/40 mV conditions, so characterize actual low-range current
rather than assigning both settings the headline 40 mV accuracy.

## Temperature selection

U14 defaults to the real thermistor path through R117:

- low: J4 NTC network (`SCC_TS_ADC`) through R47/C56 to U11 TS;
- high: fixed R56/R59 = 100 kΩ/100 kΩ midpoint, overriding charger TS faults.

R62 6.2 kΩ pulls the sensor node to `+3V3_SCC`; R69 47 kΩ provides open-sensor
bias and ESP32 IO1 reads the node. An open sensor rises to approximately 2.91 V and
a short falls near 0 V, so both wiring failures suspend charging while the real path
is selected. The fixed midpoint is a service mode, not an unattended default.

The BQ24640 temperature-out-of-range qualification delay is 400 ms typical;
temperature returning to the valid range has a 20 ms typical delay. Keep CE low
while changing U14, and allow the selected network and fault detector to settle
before re-enabling it. The tested `setThermistorOverride()` API waits 100 ms after
selecting the fixed divider and 500 ms after restoring the real sensor, in
addition to the CE-low decay interval before switching. A 100 ms real-sensor wait
allowed an approximately 300 ms charging pulse during the no-bank bench test;
the 500 ms wait removed that pulse on the tested board.

ESP32 IO1 remains connected to the real sensor branch when the override is active.
It does not measure the selected voltage at U11 TS. See the
[charger characterization](../../firmware/board_control_test/results/charger-2026-09-14/README.md)
for unloaded voltage, status, timing, and measurement limits.

## Enable and status

- `SCC_EN`: U26.P11 → U11 CE, with R115 49.9 kΩ default-low.
- `SCC_PG_N`: U11 PG → U15 → `SCC_PG`, Q8/D12, U26.P03.
- `SCC_STAT_N`: U11 STAT → U16 → `SCC_STAT`, Q9/D13, U26.P04.

Both conditioned signals are active high. `SCC_PG` indicates a valid charger
input, not that CE is asserted or charging is occurring. It can remain high with
the boost disabled because L1/D1/D8 pass the input supply through to U11. Evaluate
`SCC_STAT` over time and alongside CE, thermistor voltage, and bank voltage; a
blinking D13 is status activity, not proof of successful charging.

With a charged bank and boost off, the passive charger-input voltage can be lower
than the bank. BQ24640 then sleeps and deasserts PG even when main power has
returned. The real-bank transfer test observed charger PG low and TS ADC near
zero during this condition, followed by recovery as bank voltage fell. Use the
input-switch PG and mux status to assess main return; qualify the thermistor
after enabling boost and allowing the charger reference to recover.

U26 has no reset pin. An ESP32-only reset can leave CE and profile selection in
their previous states while `+3V3_SS` remains powered. This retained behavior is an
accepted architecture choice; firmware must read and reconcile U26 before writing.

## Release checks

- Confirm external bank series count, voltage rating, balancing, temperature
  protection, and external fuse.
- Validate both charge currents across source voltage, USB contract, boost ripple,
  supercap ESR, and thermal limits.
- Keep `SCC_EN` low while changing U12/U14 and while starting or stopping U5.
- Scope VFB, PH, charge current, and bank voltage during startup, current selection,
  TS faults, input loss, and input return.

Primary reference: [BQ24640 datasheet](https://www.ti.com/lit/ds/symlink/bq24640.pdf).

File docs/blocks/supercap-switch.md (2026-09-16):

# SUPER CAP SWITCH — backup-path arming

**Schematic label:** `SUPER CAP SWITCH`

**Key parts:** U24 LM73100, CN1 XT30, U21 TVS2200, U29 TLV7031

U24 connects raw bank rail `+VCAP` to U19 IN2, `+VCAP_VALID`, only while ESP32 IO42
asserts `VCAP_EN`. R38 49.9 kΩ holds the path off during reset or brownout.

- Raw `+VCAP` has U21 TVS2200 and approximately 16.8 µF of local ceramic
  capacitance rather than the former 100 µF bulk. CN1 connects the external bank.
- R85/R96 = 487 kΩ/27 kΩ set 22.84/20.75 V OVLO.
- R87/R94 = 82 kΩ/30 kΩ set 4.48/4.07 V PGTH. U29, powered by
  `+3V3_VCAP`, produces `VCAP_PG` for U26.P05 and Q14/D24.
- C99 4.7 nF provides the controlled output ramp, annotated at approximately 47 ms
  for the stated load-capacitance condition.
- R127 is the IMON load; D28/R110/C61 feed `VIMON_SC` to ESP32 IO10.
- U24 reverse blocking prevents charging through the mux path. U11 is the intended
  charger.

`VCAP_PG` only means the U24 output exceeded its low PG threshold; it does not prove
that enough energy remains to regulate `+5V_SS`. Firmware must use `VCAP_ADC` and a
load-aware shutdown threshold.

Once armed, U19 performs source selection without firmware intervention. Direct
IO42 control intentionally releases U24 if the ESP32 browns out during backup,
returning the board to its default-off state. Validate failover at maximum load
before the backed logic rail can reach its brownout threshold.

U24 OVLO protects the mux path, not the direct U11-to-bank charging connection. The
accepted protection allocation uses precise VFB regulation, isolated ESP32 bank
monitoring, external cell balancing/temperature protection, and an external fuse
near the bank.

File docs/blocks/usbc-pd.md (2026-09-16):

# USBC PD — USB-C Power Delivery sink front end

**Schematic label:** `USBC PD`

**Key parts:** J1, U8 CYPD3177-24LQXQT, U2 TVS2200, U3 TS5A3159,
U4 TLV7031, JP1

## Function and configuration

U8 is Infineon's CYPD3177 BCR sink controller. `VBUS_MIN` and `VBUS_MAX` are tied
to `+3V3_PDC`, so the autonomous configuration requests a specific 20 V PDO rather
than the former 12–20 V window. Before negotiation, raw `+VBUS_USB` can be the USB
default 5 V; U22 remains off until U4 validates U8's gate state.

- J1 VBUS is `+VBUS_USB`, protected by U2 TVS2200 and local C2/C3/C82.
- D4/D5 protect CC1/CC2; U8 supplies the sink terminations.
- U8's internal 3.3 V output is `+3V3_PDC`, present only with USB VBUS.
- `ISNK_COARSE` and `ISNK_FINE` are grounded. U8 accepts any advertised source
  current as meeting its zero-current selection threshold, and requests **0 A
  operating current**. This does not automatically request the source PDO's full
  current. Firmware must read the PDO/RDO, establish the intended current request,
  and enforce the board power budget.
- HPI address is 0x08 on `PD_SDA`/`PD_SCL`; `PD_INT` reaches ESP32 IO39.
- FAULT drives Q7/D6. D+/D−, GPIO1, and SAFE_PWR_EN are unused.

The controller negotiates voltage autonomously but does not limit total downstream
load current. A 20 V contract can still provide less power than the high-current
charger plus enabled outputs require; 5 A operation also requires the appropriate
e-marked cable.

The 2026-09-14 HPI bench read found source PDO `0x000641D6` (**20 V / 4.7 A**)
and RDO `0x4080000A` (**0 A operating, 0.1 A maximum**, object 4). Communication
and repeated data were stable. The zero operating field agrees with the grounded
pins; the origin of the 0.1 A maximum field remains unverified. Do not treat the
source's advertised 94 W ceiling as a validated board power budget. The unloaded
control test made no PD configuration changes. Infineon's
[CY4533 guide, section 2.4](https://www.infineon.com/assets/row/public/documents/24/44/infineon-cy4533-ez-pd-barrel-connector-replacement-evk-guide-usermanual-en.pdf)
specifies that the RDO operating current follows ISNK_COARSE + ISNK_FINE.

The later real-bank charging test successfully programmed a volatile sink profile
through HPI and verified **20 V / 2 A operating and maximum current**, RDO
`0x408320C8`, stable for 503 ms before enabling the charger. The source PDO stayed
`0x000641D6`; HPI response was `0x02` (success). This establishes a 40 W requested
allowance for the low-current charger and unloaded board, not a measured current
or blanket approval for external loads. The profile must be revalidated after
PD-controller power loss. See the
[transfer procedure](../../firmware/board_control_test/TRANSFER-TEST.md) and
[command references](../../firmware/board_control_test/PD-REFERENCES.md).

## Contract-gate conversion

U8 `VBUS_FET_EN` is a PFET gate driver: near VBUS while off and near GND after an
acceptable contract. U4 converts that polarity:

- IN+ = `+VBUS_USB` × 10/(200+10) via R2/R7 = VBUS/21;
- IN− = `VBUS_FET_EN` × 10/(100+10) via R21/R14 = gate/11;
- no contract: IN− > IN+, U4/R8 hold U22 off;
- valid contract: IN− ≈ 0, U4 asserts `VBUS_USB_EN` and U22 ramps `+VBUS`.

R8 49.9 kΩ is the independent output pulldown. Divider logic, common-mode range,
and failure behavior are detailed in [comparators.md](comparators.md).

The architecture accepts that this path is not single-fault tolerant: a stuck-high
U4, open R21, or shorted R14 could enable U22 early. Bench-test attach, detach,
reset, cable reversal, and incompatible sources.

## HPI power-domain isolation

U3 gates the top of R26 10 kΩ (`PD_INT`) and R27/R28 2.2 kΩ
(`PD_SDA`/`PD_SCL`). R11 10 kΩ from `+3V3_PDC` and R16 100 kΩ to GND select:

- `+3V3_SS` pull-ups while both domains are powered;
- grounded pulls while only the backed rail is present;
- powered-off high impedance while `+3V3_SS` is absent.

This prevents either power domain from back-powering the other through the HPI
signals and requires no firmware-controlled bus enable.

## `VDC_OUT` configuration jumper

JP1 is a default-closed solder jumper between U8 `VDC_OUT` and shared `+VBUS`.

- **USB-C operation:** leave JP1 closed so `VDC_OUT` monitors the system side of
  U22 as intended.
- **DC operation:** open JP1 before applying J6 power so DC cannot energize
  `VDC_OUT` while U8 is unpowered.

USB-C and DC power must not be connected simultaneously. JP1 is a deliberate user
configuration control, not automatic source protection.

Primary reference: [CYPD3177 datasheet](https://www.infineon.com/assets/row/public/documents/24/49/infineon-cypd3177-24lqxq-datasheet-en.pdf).

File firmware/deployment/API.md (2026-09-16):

# Tankervision deployment USB API v1

The ESP32 owns charging, backup power, the Jetson supply, and the shutdown deadline. The Jetson reads board telemetry, acknowledges pings and shutdown requests, and controls the three optional external outputs. USB disconnects do not suspend the ESP32 power supervisor.

After the initial ten-second settling interval, firmware verifies its input budget and prepares charging through the real temperature-sense path. A healthy charger remains enabled after VCAP passes 20 V so it can maintain the bank while the Jetson runs. A charger fault or shutdown stops charging; fault reporting remains visible in telemetry. Maintenance charging does not change the fixed shutdown deadline.

The USB-PD request is fixed 20 V at **3 A** (60 W at the input), with a 5 V/900 mA fallback PDO. Firmware requires the verified 20 V contract before authorizing its loads. Budget the Jetson, approximately 23 W during supercap replenishment, optional external outputs, and conversion losses together within the input allowance. This setting is not a claim that every Jetson model or operating mode fits that budget. DC input uses a configured installation allowance rather than negotiation.

## Transport and framing

Use J2's deployment TinyUSB CDC endpoint at 115200 baud. Assert DTR and RTS and leave them stable. Deployment firmware disables CDC reboot hooks **before** starting USB; see [the exact Arduino 3.3.3 transport configuration](jetson/USB-TRANSPORT.md). This API is not supported by the earlier board-control test sketch.

Each message is one UTF-8 JSON object followed by LF. Host requests are limited to 512 bytes excluding LF. Device messages are limited to 8192 bytes. An oversized or invalid line is discarded through LF; a subsequent valid line starts a new frame. Do not send shell commands, human-readable serial commands, or binary framing.

Requests use a strict flat schema: unescaped ASCII field names and string values, unsigned decimal integer IDs, and JSON booleans. Duplicate or unknown fields, nested values, floating-point IDs, negative IDs, leading-zero numbers, and trailing data are rejected. Field order and ordinary JSON whitespace are insignificant. The supplied client emits the accepted subset directly.

Every device message has these fields:

| Field | Type | Meaning |
| --- | --- | --- |
| `v` | integer | Protocol version, `1`. |
| `type` | string | `telemetry`, `event`, or `response`. |
| `boot_id` | string | Eight uppercase hexadecimal digits identifying this firmware boot. |
| `seq` | uint32 | Message sequence within this boot; may wrap. Dropped telemetry can create gaps. |
| `uptime_ms` | uint32 | ESP32 milliseconds since boot; wraps after about 49.7 days. |

Treat a changed `boot_id` as a new board session. Discard pending operations and shutdown work tied to the previous boot. Use `remaining_ms` to schedule host work; `deadline_ms` is in the ESP32 uptime domain and is not a host wall-clock timestamp.

## Telemetry and status

The ESP32 emits telemetry approximately once per second when USB can accept it. A `status` request also requests an immediate snapshot. Telemetry includes `state`, `readings`, `ports`, and `shutdown`, together with the common envelope.

`state` is one of `SETTLING`, `CHARGE_PREPARE`, `CHARGING`, `JETSON_STARTING`, `RUNNING`, `SHUTDOWN_WAIT`, or `POWER_OFF`. These report the power-management phase, not a guarantee that every requested hardware operation succeeded. Inspect telemetry validity, issues, controls, and power-good readings as well.

`readings` contains board measurements and digital status. Raw ADC counts and millivolts are observations; nominal current conversions are uncalibrated. Voltage and PG checks govern this firmware's power policy. Current estimates do not establish load-test validation.

| Telemetry field | Meaning |
| --- | --- |
| `reset_reason` | Numeric ESP-IDF reset reason for this boot. |
| `settling_remaining_ms` | Remaining initial 10-second settling interval. |
| `action` | Pending power-policy action name, or `NONE`. |
| `hardware_operation` | Board adapter operation enum: 0 none, 1 reconcile, 2 prepare charge, 3 enable charge, 4 disable charging, 5 port change, 6 restore POR. |
| `issue_bits`, `issues` | Latched policy issue bitmask and corresponding string names. |
| `last_error` | Most recently recorded adapter error, or an empty string. |
| `backup_armed` | Policy's successful backup-arm result; inspect `signals.VCAP_EN` and `signals.VCAP_PG` for physical evidence. |
| `backup_low_voltage` | VCAP is below the 10 V arming threshold. |
| `source_budget_valid`, `source_budget_ma` | Accepted input budget and its current allowance. A DC budget is an installation configuration, not a negotiated or measured current. |
| `charger.enabled_expected`, `charger.maintenance` | Policy expects charging to remain enabled; maintenance becomes true after successful initial qualification and ends on a charger fault or shutdown. |
| `jetson.port_enabled` | Sensed J9 enable-pin level; inspect J9 power-good separately. |
| `jetson.responsive`, `jetson.pong_seen`, `jetson.last_pong_age_ms` | Current pong freshness, whether any pong has been seen, and age or `null`. |
| `jetson.ping_id`, `jetson.on_feedback` | Current ping identifier and physical Jetson-on feedback. |
| `telemetry.generated`, `telemetry.late_periods` | Generated snapshots and missed nominal one-second periods. |
| `telemetry.usb_connected`, `telemetry.queued` | CDC connection state and queued frames. |
| `telemetry.dropped_messages`, `telemetry.dropped_telemetry`, `telemetry.max_loop_gap_ms` | Transmission/backpressure counters and largest observed main-loop gap. |

The `readings` object has these children:

| Field | Meaning |
| --- | --- |
| `valid`, `age_ms` | Both expander reads succeeded, and snapshot age. Check individual expander validity too; analog/GPIO samples are still collected on an I2C failure. |
| `vcap_v`, `ts_mv` | Divider-derived raw VCAP rail voltage and charger-temperature ADC voltage. VCAP currently uses `analog.VCAP.mv * 0.0092`; no meter correction is applied. |
| `analog` | `TS`, `VCAP`, `IMON_DC`, `IMON_J8`, `IMON_J7`, `IMON_J9`, `IMON_J10`, `IMON_USB`, and `IMON_BACKUP`. Each has `gpio`, averaged 12-bit `raw`, averaged `mv`, and nominal `estimated_a`; current is `null` for TS and VCAP. |
| `signals` | Named physical digital levels listed below. `true` means electrically high; active-low interrupt names must be interpreted accordingly. |
| `expanders.internal`, `expanders.external` | `valid`, `age_ms`, two-byte arrays `input`, `output`, `polarity`, `config`, and the uint16 `physical_inputs` value. Physical inputs undo the polarity register inversion. |
| `edges` | Counts `internal_fall`, `internal_rise`, `external_fall`, `external_rise`, `mux_fall`, `mux_rise`, `pd_fall`, and `pd_rise`. These count interrupt/GPIO transitions, not individual expander pin events. |
| `pd` | CYPD3177 status with `valid`, `age_ms`, `device_mode`, `silicon_id`, `status`, `type_c_status`, `pdo`, `rdo`, `response`, `interrupt_status`, `attached`, `millivolts`, `source_ma`, `operating_ma`, `maximum_ma`, and raw 16-byte `versions`. A stale or invalid PD snapshot must not be treated as a new active contract. |

`signals` keys are:

```text
PG_USB PG_DC VCAP_PG SCC_PG SCC_STAT 24V_VBUS_PG 5V_VBUS_PG 5V_SS_PG
EXT_VBUS_PG EXT_5V_VBUS_PG EXT_SS_PG EXT_5V_SS_PG JET_ON_FB PMUX_ST
VCAP_EN STAT_LED CTRL_IN_INT_N CTRL_EXT_INT_N PD_INT
24V_VBUS_EN SCC_EN SCC_ISET_SW SCC_TS_SW 5V_VBUS_EN
EXT_VBUS_EN EXT_5V_VBUS_EN EXT_SS_EN EXT_5V_SS_EN JET_PWR_BTN_CTRL
BOOT_N
```
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

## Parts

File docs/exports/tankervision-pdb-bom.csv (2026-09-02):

Refs | Value | Footprint | Qty | DNP
C1 | 100n | Capacitor_SMD:C_0603_1608Metric | 1
C2 | 4u7 | Capacitor_SMD:C_1206_3216Metric | 1
C3 | 100n | Capacitor_SMD:C_0603_1608Metric | 1
C4 | 100n | Capacitor_SMD:C_0603_1608Metric | 1
C5 | 10u | Capacitor_SMD:C_1206_3216Metric | 1
C6 | 10u | Capacitor_SMD:C_1206_3216Metric | 1
C7 | 100n | Capacitor_SMD:C_0603_1608Metric | 1
C8 | 100u | 100u_elec_cap:CAP_EEHZA1H101V | 1
C9 | 100u | 100u_elec_cap:CAP_EEHZA1H101V | 1
C10 | 100u | 100u_elec_cap:CAP_EEHZA1H101V | 1
C11 | 100u | 100u_elec_cap:CAP_EEHZA1H101V | 1
C12 | 10u | Capacitor_SMD:C_1206_3216Metric | 1
C13 | 10u | Capacitor_SMD:C_1206_3216Metric | 1
C14 | 10u | Capacitor_SMD:C_1206_3216Metric | 1
C15 | 1u | Capacitor_SMD:C_0805_2012Metric | 1
C16 | 4u7 | Capacitor_SMD:C_1206_3216Metric | 1
C17 | 4u7 | Capacitor_SMD:C_1206_3216Metric | 1
C18 | 4u7 | Capacitor_SMD:C_1206_3216Metric | 1
C19 | 100n | Capacitor_SMD:C_0603_1608Metric | 1
C20 | 22u | Capacitor_SMD:C_1206_3216Metric | 1
C21 | 22u | Capacitor_SMD:C_1206_3216Metric | 1
C22 | 22u | Capacitor_SMD:C_1206_3216Metric | 1
C23 | 10n | Capacitor_SMD:C_0603_1608Metric | 1
C24 | 22p | Capacitor_SMD:C_0603_1608Metric | 1
C25 | 100n | Capacitor_SMD:C_0603_1608Metric | 1
C26 | 1u | Capacitor_SMD:C_0805_2012Metric | 1
C27 | 100p | Capacitor_SMD:C_0603_1608Metric | 1
C28 | 100n | Capacitor_SMD:C_0603_1608Metric | 1
C29 | 100n | Capacitor_SMD:C_0603_1608Metric | 1
C30 | 220n | Capacitor_SMD:C_0603_1608Metric | 1
C31 | 220p | Capacitor_SMD:C_0603_1608Metric | 1
C32 | 22n | Capacitor_SMD:C_0603_1608Metric | 1
C33 | 4u7 | Capacitor_SMD:C_1206_3216Metric | 1
C34 | 4u7 | Capacitor_SMD:C_1206_3216Metric | 1
C35 | 100n | Capacitor_SMD:C_0603_1608Metric | 1
C36 | 100n | Capacitor_SMD:C_0603_1608Metric | 1
C37 | 22u | Capacitor_SMD:C_1206_3216Metric | 1
C38 | 100n | Capacitor_SMD:C_0603_1608Metric | 1
C39 | 100n | Capacitor_SMD:C_0603_1608Metric | 1
C40 | 10u | Capacitor_SMD:C_1206_3216Metric | 1
C41 | 10u | Capacitor_SMD:C_1206_3216Metric | 1
C42 | 1u | Capacitor_SMD:C_0805_2012Metric | 1
C43 | 2.2u | Capacitor_SMD:C_1206_3216Metric | 1
C44 | 100n | Capacitor_SMD:C_0603_1608Metric | 1
C45 | 1u | Capacitor_SMD:C_0805_2012Metric | 1
C46 | 100n | Capacitor_SMD:C_0603_1608Metric | 1
C47 | 1u | Capacitor_SMD:C_0805_2012Metric | 1
C48 | 100n | Capacitor_SMD:C_0603_1608Metric | 1
C49 | 100n | Capacitor_SMD:C_0603_1608Metric | 1
C50 | 100n | Capacitor_SMD:C_0603_1608Metric | 1
C51 | 10u | Capacitor_SMD:C_1206_3216Metric | 1
C52 | 4u7 | Capacitor_SMD:C_1206_3216Metric | 1
C53 | 100n | Capacitor_SMD:C_0603_1608Metric | 1
C54 | 100n | Capacitor_SMD:C_0603_1608Metric | 1
C55 | 100n | Capacitor_SMD:C_0603_1608Metric | 1
C56 | 100n | Capacitor_SMD:C_0603_1608Metric | 1
C57 | 100n | Capacitor_SMD:C_0603_1608Metric | 1
C58 | 100n | Capacitor_SMD:C_0603_1608Metric | 1
C59 | 100n | Capacitor_SMD:C_0603_1608Metric | 1
C60 | 10u | Capacitor_SMD:C_1206_3216Metric | 1
C61 | 100n | Capacitor_SMD:C_0603_1608Metric | 1
C62 | 100n | Capacitor_SMD:C_0603_1608Metric | 1
C63 | 10u | Capacitor_SMD:C_1206_3216Metric | 1
C64 | 10u | Capacitor_SMD:C_1206_3216Metric | 1
C65 | 100n | Capacitor_SMD:C_0603_1608Metric | 1
C66 | 22u | Capacitor_SMD:C_1206_3216Metric | 1
C67 | 22u | Capacitor_SMD:C_1206_3216Metric | 1
C68 | 22u | Capacitor_SMD:C_1206_3216Metric | 1
C69 | 22p | Capacitor_SMD:C_0603_1608Metric | 1
C70 | 100n | Capacitor_SMD:C_0603_1608Metric | 1
C71 | 100n | Capacitor_SMD:C_0603_1608Metric | 1
C72 | 100n | Capacitor_SMD:C_0603_1608Metric | 1
C73 | 100n | Capacitor_SMD:C_0603_1608Metric | 1
C74 | 100n | Capacitor_SMD:C_0603_1608Metric | 1
C75 | 1u | Capacitor_SMD:C_0805_2012Metric | 1
C76 | 100n | Capacitor_SMD:C_0603_1608Metric | 1
C77 | 100n | Capacitor_SMD:C_0603_1608Metric | 1
C78 | 100u | 100u_elec_cap:CAP_EEHZA1H101V | 1
C79 | 100u | 100u_elec_cap:CAP_EEHZA1H101V | 1
C80 | 10u | Capacitor_SMD:C_1206_3216Metric | 1
C81 | 10u | Capacitor_SMD:C_1206_3216Metric | 1
C82 | 1u | Capacitor_SMD:C_0805_2012Metric | 1
C83 | 1u | Capacitor_SMD:C_0805_2012Metric | 1
C84 | 10u | Capacitor_SMD:C_1206_3216Metric | 1
C85 | 10u | Capacitor_SMD:C_1206_3216Metric | 1
C86 | 100n | Capacitor_SMD:C_0603_1608Metric | 1
C87 | 1u | Capacitor_SMD:C_0805_2012Metric | 1
C88 | 100n | Capacitor_SMD:C_0603_1608Metric | 1
C89 | 100n | Capacitor_SMD:C_0603_1608Metric | 1
C90 | 10u | Capacitor_SMD:C_1206_3216Metric | 1
C91 | 10u | Capacitor_SMD:C_1206_3216Metric | 1
C92 | 100n | Capacitor_SMD:C_0603_1608Metric | 1
C93 | 1u | Capacitor_SMD:C_0805_2012Metric | 1
C94 | 100n | Capacitor_SMD:C_0603_1608Metric | 1
C95 | 4.7n | Capacitor_SMD:C_0805_2012Metric_Pad1.18x1.45mm_HandSolder | 1
C96 | 100n | Capacitor_SMD:C_0603_1608Metric | 1
C97 | 100n | Capacitor_SMD:C_0603_1608Metric | 1
C98 | 4.7n | Capacitor_SMD:C_0805_2012Metric_Pad1.18x1.45mm_HandSolder | 1
C99 | 4.7n | Capacitor_SMD:C_0805_2012Metric_Pad1.18x1.45mm_HandSolder | 1
C100 | 100n | Capacitor_SMD:C_0603_1608Metric | 1
C101 | 1u | Capacitor_SMD:C_0805_2012Metric | 1
C102 | 1u | Capacitor_SMD:C_0805_2012Metric | 1
C103 | 1u | Capacitor_SMD:C_0805_2012Metric | 1
C104 | 1u | Capacitor_SMD:C_0805_2012Metric | 1
C105 | 100n | Capacitor_SMD:C_0603_1608Metric | 1
C106 | 4.7n | Capacitor_SMD:C_0805_2012Metric_Pad1.18x1.45mm_HandSolder | 1
C107 | 4.7n | Capacitor_SMD:C_0805_2012Metric_Pad1.18x1.45mm_HandSolder | 1
C108 | 33n | Capacitor_SMD:C_0805_2012Metric_Pad1.18x1.45mm_HandSolder | 1
C109 | 33n | Capacitor_SMD:C_0805_2012Metric_Pad1.18x1.45mm_HandSolder | 1
C110 | 1u | Capacitor_SMD:C_0805_2012Metric | 1
C111 | 1u | Capacitor_SMD:C_0805_2012Metric | 1
C112 | 1u | Capacitor_SMD:C_0805_2012Metric | 1
C113 | 1u | Capacitor_SMD:C_0805_2012Metric | 1
C114 | 1u | Capacitor_SMD:C_0805_2012Metric | 1
C115 | 1u | Capacitor_SMD:C_0805_2012Metric | 1
C116 | 100n | Capacitor_SMD:C_0603_1608Metric | 1
C117 | 100n | Capacitor_SMD:C_0603_1608Metric | 1
C118 | 100n | Capacitor_SMD:C_0603_1608Metric | 1
C119 | 100n | Capacitor_SMD:C_0603_1608Metric | 1
CN1 | XT30APW-M | xt30:CONN-TH_XT30APW-M | 1
D1 | PMEG060V100EPDZ | 24V_boost_diode:SOT1289_L5.8-W4.4-LS6.5-RD | 1
D2 | LED Red | LED_SMD:LED_0805_2012Metric | 1
D3 | LED Red | LED_SMD:LED_0805_2012Metric | 1
D4 | PESD5V0L1UL | Diode_SMD:D_SOD-882 | 1
D5 | PESD5V0L1UL | Diode_SMD:D_SOD-882 | 1
D6 | LED Red | LED_SMD:LED_0805_2012Metric | 1
D7 | LED Green | LED_SMD:LED_0805_2012Metric | 1
D8 | PMEG060V100EPDZ | 24V_boost_diode:SOT1289_L5.8-W4.4-LS6.5-RD | 1
D9 | LED Red | LED_SMD:LED_0805_2012Metric | 1
D10 | BAT54C,215 | supercap_charger_btst_diode:SOT-23 | 1
D11 | PESD3V3S1UL,315 | Diode_SMD:D_SOD-882 | 1
D12 | LED Red | LED_SMD:LED_0805_2012Metric | 1
D13 | LED Red | LED_SMD:LED_0805_2012Metric | 1
D14 | PESD5V0L1UL | Diode_SMD:D_SOD-882 | 1
D15 | PESD5V0L1UL | Diode_SMD:D_SOD-882 | 1
D16 | LED Red | LED_SMD:LED_0805_2012Metric | 1
D17 | PESD3V3S1UL,315 | Diode_SMD:D_SOD-882 | 1
D18 | PESD3V3S1UL,315 | Diode_SMD:D_SOD-882 | 1
D19 | PESD3V3S1UL,315 | Diode_SMD:D_SOD-882 | 1
D20 | PMEG060V100EPDZ | 24V_boost_diode:SOT1289_L5.8-W4.4-LS6.5-RD | 1
D21 | PMEG060V100EPDZ | 24V_boost_diode:SOT1289_L5.8-W4.4-LS6.5-RD | 1
D22 | LED Red | LED_SMD:LED_0805_2012Metric | 1
D23 | LED Red | LED_SMD:LED_0805_2012Metric | 1
D24 | LED Red | LED_SMD:LED_0805_2012Metric | 1
D25 | LED Green | LED_SMD:LED_0805_2012Metric | 1
D26 | DDZ9678-7 | Diode_SMD:D_SOD-123 | 1
D27 | DDZ9678-7 | Diode_SMD:D_SOD-123 | 1
D28 | DDZ9678-7 | Diode_SMD:D_SOD-123 | 1
D29 | LED Red | LED_SMD:LED_0805_2012Metric | 1
D30 | PMEG060V100EPDZ | 24V_boost_diode:SOT1289_L5.8-W4.4-LS6.5-RD | 1
D31 | PMEG060V100EPDZ | 24V_boost_diode:SOT1289_L5.8-W4.4-LS6.5-RD | 1
D32 | PMEG060V100EPDZ | 24V_boost_diode:SOT1289_L5.8-W4.4-LS6.5-RD | 1
D33 | PMEG060V100EPDZ | 24V_boost_diode:SOT1289_L5.8-W4.4-LS6.5-RD | 1
D34 | LED Red | LED_SMD:LED_0805_2012Metric | 1
D35 | LED Red | LED_SMD:LED_0805_2012Metric | 1
D36 | LED Red | LED_SMD:LED_0805_2012Metric | 1
D37 | LED Red | LED_SMD:LED_0805_2012Metric | 1
D38 | DDZ9678-7 | Diode_SMD:D_SOD-123 | 1
D39 | DDZ9678-7 | Diode_SMD:D_SOD-123 | 1
D40 | DDZ9678-7 | Diode_SMD:D_SOD-123 | 1
D41 | DDZ9678-7 | Diode_SMD:D_SOD-123 | 1
IC1 | ESP32-S3-WROOM-1-N8R8 | esp32:ESP32S3WROOM1N8R8 | 1
J1 | TYPE-C-31-M-12 | usbc_female:CONN12_C-31-M-12_HRO | 1
J2 | TYPE-C-31-M-12 | usbc_female:CONN12_C-31-M-12_HRO | 1
J3 | S3B-PH-K-S LFSN | jst_3_pin:CONN_S3B-PH-K-S_JST | 1
J4 | S2B-PH-K-SLFSN | jst_2_pin:CONN_S2B-PH-K-S_JST | 1
J5 | S3B-PH-K-S LFSN | jst_3_pin:CONN_S3B-PH-K-S_JST | 1
J6 | PJ-202AH | barrel-jack:CUI_PJ-202AH | 1
J7 | PJ-202AH | barrel-jack:CUI_PJ-202AH | 1
J8 | PJ-202AH | barrel-jack:CUI_PJ-202AH | 1
J9 | PJ-202AH | barrel-jack:CUI_PJ-202AH | 1
J10 | PJ-202AH | barrel-jack:CUI_PJ-202AH | 1
L1 | CYA1265-6.8UH | 24V_inductor:IND-SMD_L12.8-W12.8-LS13.8_CYA1265 | 1
L2 | 1.5uH | 20v-5v-buck:IND_MWSA0603S_SNL-M | 1
L3 | 10uH | supercap_charger_inductor:SMDRI127100MT | 1
L4 | 1.5uH | 20v-5v-buck:IND_MWSA0603S_SNL-M | 1
Q1 | IPC50N04S5L5R5ATMA1 | 24V_boost_nfet:PG-TDSON-8-FL_L5.0-W6.0-P1.27-LS6.2-BL | 1
Q2 | 2N7002NXAKR | usbc-pd-fault-nmos:TO-236AB_SOT23_NEX-M | 1
Q3 | 2N7002NXAKR | usbc-pd-fault-nmos:TO-236AB_SOT23_NEX-M | 1
Q4 | IPC50N04S5L5R5ATMA1 | 24V_boost_nfet:PG-TDSON-8-FL_L5.0-W6.0-P1.27-LS6.2-BL | 1
Q5 | 2N7002NXAKR | usbc-pd-fault-nmos:TO-236AB_SOT23_NEX-M | 1
Q6 | IPC50N04S5L5R5ATMA1 | 24V_boost_nfet:PG-TDSON-8-FL_L5.0-W6.0-P1.27-LS6.2-BL | 1
Q7 | 2N7002NXAKR | usbc-pd-fault-nmos:TO-236AB_SOT23_NEX-M | 1
Q8 | 2N7002NXAKR | usbc-pd-fault-nmos:TO-236AB_SOT23_NEX-M | 1
Q9 | 2N7002NXAKR | usbc-pd-fault-nmos:TO-236AB_SOT23_NEX-M | 1
Q10 | 2N7002NXAKR | usbc-pd-fault-nmos:TO-236AB_SOT23_NEX-M | 1
Q11 | 2N7002NXAKR | usbc-pd-fault-nmos:TO-236AB_SOT23_NEX-M | 1
Q12 | 2N7002NXAKR | usbc-pd-fault-nmos:TO-236AB_SOT23_NEX-M | 1
Q13 | 2N7002NXAKR | usbc-pd-fault-nmos:TO-236AB_SOT23_NEX-M | 1
Q14 | 2N7002NXAKR | usbc-pd-fault-nmos:TO-236AB_SOT23_NEX-M | 1
Q15 | 2N7002NXAKR | usbc-pd-fault-nmos:TO-236AB_SOT23_NEX-M | 1
Q16 | 2N7002NXAKR | usbc-pd-fault-nmos:TO-236AB_SOT23_NEX-M | 1
Q17 | 2N7002NXAKR | usbc-pd-fault-nmos:TO-236AB_SOT23_NEX-M | 1
Q18 | 2N7002NXAKR | usbc-pd-fault-nmos:TO-236AB_SOT23_NEX-M | 1
R1 | 30k | Resistor_SMD:R_0603_1608Metric | 1
R2 | 200k | Resistor_SMD:R_0603_1608Metric | 1
R3 | 150k | Resistor_SMD:R_0603_1608Metric | 1
R4 | 100 | Resistor_SMD:R_0603_1608Metric | 1
R5 | 20k | Resistor_SMD:R_0603_1608Metric | 1
R6 | 10k | Resistor_SMD:R_0603_1608Metric | 1
R7 | 10k | Resistor_SMD:R_0603_1608Metric | 1
R8 | 49.9k | Resistor_SMD:R_0603_1608Metric | 1
R9 | 12MR-1% | 24V_sense_r:RES-SMD_L6.4-W3.2_LR2512D-3W-1MR | 1
R10 | 47k | Resistor_SMD:R_0805_2012Metric_Pad1.20x1.40mm_HandSolder | 1
R11 | 10k | Resistor_SMD:R_0603_1608Metric | 1
R12 | 2k2 | Resistor_SMD:R_0603_1608Metric | 1
R13 | 2k2 | Resistor_SMD:R_0603_1608Metric | 1
R14 | 10k | Resistor_SMD:R_0603_1608Metric | 1
R15 | 11.3k | Resistor_SMD:R_0603_1608Metric | 1
R16 | 100k | Resistor_SMD:R_0603_1608Metric | 1
R17 | 49.9k | Resistor_SMD:R_0603_1608Metric | 1
R18 | 100k | Resistor_SMD:R_0603_1608Metric | 1
R19 | 100k | Resistor_SMD:R_0603_1608Metric | 1
R20 | 2k | Resistor_SMD:R_0805_2012Metric_Pad1.20x1.40mm_HandSolder | 1
R21 | 100k | Resistor_SMD:R_0603_1608Metric | 1
R22 | 120k | Resistor_SMD:R_0603_1608Metric | 1
R23 | 120k | Resistor_SMD:R_0603_1608Metric | 1
R24 | 100k | Resistor_SMD:R_0603_1608Metric | 1
R25 | 100k | Resistor_SMD:R_0603_1608Metric | 1
R26 | 10k | Resistor_SMD:R_0603_1608Metric | 1
R27 | 2k2 | Resistor_SMD:R_0603_1608Metric | 1
R28 | 2k2 | Resistor_SMD:R_0603_1608Metric | 1
R29 | 49.9k | Resistor_SMD:R_0603_1608Metric | 1
R30 | 2k2 | Resistor_SMD:R_0603_1608Metric | 1
R31 | 2k2 | Resistor_SMD:R_0603_1608Metric | 1
R32 | 2 | Resistor_SMD:R_0603_1608Metric | 1
R33 | 10 | Resistor_SMD:R_0603_1608Metric | 1
R34 | 2k2 | Resistor_SMD:R_0603_1608Metric | 1
R35 | 2k2 | Resistor_SMD:R_0603_1608Metric | 1
R36 | 2k2 | Resistor_SMD:R_0603_1608Metric | 1
R37 | 49.9k | Resistor_SMD:R_0603_1608Metric | 1
R38 | 49.9k | Resistor_SMD:R_0603_1608Metric | 1
R39 | 20k | Resistor_SMD:R_0603_1608Metric | 1
R40 | 10m | Resistor_SMD:R_2512_6332Metric | 1
R41 | 150k | Resistor_SMD:R_0603_1608Metric | 1
R42 | 150k | Resistor_SMD:R_0603_1608Metric | 1
R43 | 300k | Resistor_SMD:R_0805_2012Metric_Pad1.20x1.40mm_HandSolder | 1
R44 | 5.1k | Resistor_SMD:R_0603_1608Metric | 1
R45 | 10k | Resistor_SMD:R_0805_2012Metric_Pad1.20x1.40mm_HandSolder | 1
R46 | 20k | Resistor_SMD:R_0805_2012Metric_Pad1.20x1.40mm_HandSolder | 1
R47 | 100 | Resistor_SMD:R_0603_1608Metric | 1
R48 | 5.1k | Resistor_SMD:R_0603_1608Metric | 1
R49 | 49.9k | Resistor_SMD:R_0603_1608Metric | 1
R50 | 34k | Resistor_SMD:R_0805_2012Metric_Pad1.20x1.40mm_HandSolder | 1
R51 | 150k | Resistor_SMD:R_0603_1608Metric | 1
R53 | 2k2 | Resistor_SMD:R_0603_1608Metric | 1
R54 | 2k2 | Resistor_SMD:R_0603_1608Metric | 1
R55 | 20k | Resistor_SMD:R_0603_1608Metric | 1
R56 | 100k | Resistor_SMD:R_0603_1608Metric | 1
R57 | 5.1k | Resistor_SMD:R_0603_1608Metric | 1
R58 | 5.1k | Resistor_SMD:R_0603_1608Metric | 1
R59 | 100k | Resistor_SMD:R_0603_1608Metric | 1
R60 | 100k | Resistor_SMD:R_0603_1608Metric | 1
R61 | 100k | Resistor_SMD:R_0603_1608Metric | 1
R62 | 6.2k | Resistor_SMD:R_0805_2012Metric_Pad1.20x1.40mm_HandSolder | 1
R63 | 2k2 | Resistor_SMD:R_0603_1608Metric | 1
R64 | 120k | Resistor_SMD:R_0603_1608Metric | 1
R65 | 120k | Resistor_SMD:R_0603_1608Metric | 1
R66 | 100k | Resistor_SMD:R_0603_1608Metric | 1
R67 | 100k | Resistor_SMD:R_0603_1608Metric | 1
R68 | 100k | Resistor_SMD:R_0603_1608Metric | 1
R69 | 47k | Resistor_SMD:R_0805_2012Metric_Pad1.20x1.40mm_HandSolder | 1
R70 | 120k | Resistor_SMD:R_0603_1608Metric | 1
R71 | 100k | Resistor_SMD:R_0603_1608Metric | 1
R72 | 34k | Resistor_SMD:R_0805_2012Metric_Pad1.20x1.40mm_HandSolder | 1
R73 | 49.9k | Resistor_SMD:R_0603_1608Metric | 1
R74 | 102k | Resistor_SMD:R_0805_2012Metric_Pad1.20x1.40mm_HandSolder | 1
R75 | 49.9k | Resistor_SMD:R_0603_1608Metric | 1
R76 | 5.62k | Resistor_SMD:R_0805_2012Metric_Pad1.20x1.40mm_HandSolder | 1
R77 | 10k | Resistor_SMD:R_0603_1608Metric | 1
R78 | 49.9k | Resistor_SMD:R_0603_1608Metric | 1
R79 | 49.9k | Resistor_SMD:R_0603_1608Metric | 1
R80 | 4.99k | Resistor_SMD:R_0805_2012Metric_Pad1.20x1.40mm_HandSolder | 1
R81 | 49.9k | Resistor_SMD:R_0603_1608Metric | 1
R82 | 82kΩ | Resistor_SMD:R_0805_2012Metric_Pad1.20x1.40mm_HandSolder | 1
R83 | 464k | Resistor_SMD:R_0805_2012Metric_Pad1.20x1.40mm_HandSolder | 1
R84 | 82kΩ | Resistor_SMD:R_0805_2012Metric_Pad1.20x1.40mm_HandSolder | 1
R85 | 487k | Resistor_SMD:R_0805_2012Metric_Pad1.20x1.40mm_HandSolder | 1
R86 | 487k | Resistor_SMD:R_0805_2012Metric_Pad1.20x1.40mm_HandSolder | 1
R87 | 82kΩ | Resistor_SMD:R_0805_2012Metric_Pad1.20x1.40mm_HandSolder | 1
R88 | 5.1k | Resistor_SMD:R_0603_1608Metric | 1
R89 | 102k | Resistor_SMD:R_0805_2012Metric_Pad1.20x1.40mm_HandSolder | 1
R90 | 5.1k | Resistor_SMD:R_0603_1608Metric | 1
R91 | 6.2k | Resistor_SMD:R_0603_1608Metric | 1
R92 | 7.15k | Resistor_SMD:R_0805_2012Metric_Pad1.20x1.40mm_HandSolder | 1
R93 | 6.2k | Resistor_SMD:R_0603_1608Metric | 1
R94 | 30k | Resistor_SMD:R_0603_1608Metric | 1
R95 | 5.1k | Resistor_SMD:R_0603_1608Metric | 1
R96 | 27k | Resistor_SMD:R_0805_2012Metric_Pad1.20x1.40mm_HandSolder | 1
R97 | 22k | Resistor_SMD:R_0603_1608Metric | 1
R98 | 5.1k | Resistor_SMD:R_0603_1608Metric | 1
R99 | 5.1k | Resistor_SMD:R_0603_1608Metric | 1
R100 | 4.99k | Resistor_SMD:R_0805_2012Metric_Pad1.20x1.40mm_HandSolder | 1
R101 | 5.1k | Resistor_SMD:R_0603_1608Metric | 1
R102 | 27k | Resistor_SMD:R_0805_2012Metric_Pad1.20x1.40mm_HandSolder | 1
R103 | 27k | Resistor_SMD:R_0805_2012Metric_Pad1.20x1.40mm_HandSolder | 1
R104 | 5.1k | Resistor_SMD:R_0603_1608Metric | 1
R105 | 5.1k | Resistor_SMD:R_0603_1608Metric | 1
R106 | 2k2 | Resistor_SMD:R_0603_1608Metric | 1
R107 | 2k2 | Resistor_SMD:R_0603_1608Metric | 1
R108 | 2k2 | Resistor_SMD:R_0603_1608Metric | 1
R109 | 2k2 | Resistor_SMD:R_0603_1608Metric | 1
R110 | 2k2 | Resistor_SMD:R_0603_1608Metric | 1
R111 | 2k2 | Resistor_SMD:R_0603_1608Metric | 1
R112 | 100k | Resistor_SMD:R_0603_1608Metric | 1
R113 | 2k2 | Resistor_SMD:R_0603_1608Metric | 1
R114 | 49.9k | Resistor_SMD:R_0603_1608Metric | 1
R115 | 49.9k | Resistor_SMD:R_0603_1608Metric | 1
R116 | 49.9k | Resistor_SMD:R_0603_1608Metric | 1
R117 | 49.9k | Resistor_SMD:R_0603_1608Metric | 1
R118 | 100k | Resistor_SMD:R_0603_1608Metric | 1
R119 | 100k | Resistor_SMD:R_0603_1608Metric | 1
R120 | 100k | Resistor_SMD:R_0603_1608Metric | 1
R121 | 49.9k | Resistor_SMD:R_0603_1608Metric | 1
R122 | 820 | Resistor_SMD:R_0603_1608Metric | 1
R123 | 120k | Resistor_SMD:R_0603_1608Metric | 1
R124 | 820 | Resistor_SMD:R_0603_1608Metric | 1
R125 | 120k | Resistor_SMD:R_0603_1608Metric | 1
R126 | 49.9k | Resistor_SMD:R_0603_1608Metric | 1
R127 | 820 | Resistor_SMD:R_0603_1608Metric | 1
R128 | 120k | Resistor_SMD:R_0603_1608Metric | 1
R129 | 120k | Resistor_SMD:R_0603_1608Metric | 1
R130 | 2k2 | Resistor_SMD:R_0603_1608Metric | 1
R131 | 100k | Resistor_SMD:R_0603_1608Metric | 1
R132 | 49.9k | Resistor_SMD:R_0603_1608Metric | 1
R133 | 100k | Resistor_SMD:R_0603_1608Metric | 1
R134 | 100k | Resistor_SMD:R_0603_1608Metric | 1
R135 | 100k | Resistor_SMD:R_0603_1608Metric | 1
R136 | 49.9k | Resistor_SMD:R_0603_1608Metric | 1
R137 | 10k | Resistor_SMD:R_0603_1608Metric | 1
R138 | 82kΩ | Resistor_SMD:R_0805_2012Metric_Pad1.20x1.40mm_HandSolder | 1
R139 | 82kΩ | Resistor_SMD:R_0805_2012Metric_Pad1.20x1.40mm_HandSolder | 1
R140 | 82kΩ | Resistor_SMD:R_0805_2012Metric_Pad1.20x1.40mm_HandSolder | 1
R141 | 82kΩ | Resistor_SMD:R_0805_2012Metric_Pad1.20x1.40mm_HandSolder | 1
R142 | 487k | Resistor_SMD:R_0805_2012Metric_Pad1.20x1.40mm_HandSolder | 1
R143 | 487k | Resistor_SMD:R_0805_2012Metric_Pad1.20x1.40mm_HandSolder | 1
R144 | 487k | Resistor_SMD:R_0805_2012Metric_Pad1.20x1.40mm_HandSolder | 1
R145 | 487k | Resistor_SMD:R_0805_2012Metric_Pad1.20x1.40mm_HandSolder | 1
R146 | 5.1k | Resistor_SMD:R_0603_1608Metric | 1
R147 | 6.2k | Resistor_SMD:R_0603_1608Metric | 1
R148 | 30k | Resistor_SMD:R_0603_1608Metric | 1
R149 | 11.3k | Resistor_SMD:R_0603_1608Metric | 1
R150 | 30k | Resistor_SMD:R_0603_1608Metric | 1
R151 | 5.1k | Resistor_SMD:R_0603_1608Metric | 1
R152 | 5.1k | Resistor_SMD:R_0603_1608Metric | 1
R153 | 49.9k | Resistor_SMD:R_0603_1608Metric | 1
R154 | 5.1k | Resistor_SMD:R_0603_1608Metric | 1
R155 | 5.1k | Resistor_SMD:R_0603_1608Metric | 1
R156 | 27k | Resistor_SMD:R_0805_2012Metric_Pad1.20x1.40mm_HandSolder | 1
R157 | 100k | Resistor_SMD:R_0603_1608Metric | 1
R158 | 27k | Resistor_SMD:R_0805_2012Metric_Pad1.20x1.40mm_HandSolder | 1
R159 | 100k | Resistor_SMD:R_0603_1608Metric | 1
R160 | 2k2 | Resistor_SMD:R_0603_1608Metric | 1
R161 | 2k2 | Resistor_SMD:R_0603_1608Metric | 1
R162 | 100 | Resistor_SMD:R_0603_1608Metric | 1
R163 | 2k2 | Resistor_SMD:R_0603_1608Metric | 1
R164 | 100 | Resistor_SMD:R_0603_1608Metric | 1
R165 | 2k2 | Resistor_SMD:R_0603_1608Metric | 1
R166 | 2k2 | Resistor_SMD:R_0603_1608Metric | 1
R167 | 2k2 | Resistor_SMD:R_0603_1608Metric | 1
R168 | 2k2 | Resistor_SMD:R_0603_1608Metric | 1
R169 | 2k2 | Resistor_SMD:R_0603_1608Metric | 1
R170 | 49.9k | Resistor_SMD:R_0603_1608Metric | 1
R171 | 49.9k | Resistor_SMD:R_0603_1608Metric | 1
R172 | 49.9k | Resistor_SMD:R_0603_1608Metric | 1
R173 | 49.9k | Resistor_SMD:R_0603_1608Metric | 1
R174 | 49.9k | Resistor_SMD:R_0603_1608Metric | 1
R175 | 100k | Resistor_SMD:R_0603_1608Metric | 1
R176 | 100k | Resistor_SMD:R_0603_1608Metric | 1
R177 | 820 | Resistor_SMD:R_0603_1608Metric | 1
R178 | 100k | Resistor_SMD:R_0603_1608Metric | 1
R179 | 100k | Resistor_SMD:R_0603_1608Metric | 1
R180 | 820 | Resistor_SMD:R_0603_1608Metric | 1
R181 | 820 | Resistor_SMD:R_0603_1608Metric | 1
R182 | 49.9k | Resistor_SMD:R_0603_1608Metric | 1
R183 | 49.9k | Resistor_SMD:R_0603_1608Metric | 1
R184 | 49.9k | Resistor_SMD:R_0603_1608Metric | 1
R185 | 49.9k | Resistor_SMD:R_0603_1608Metric | 1
R186 | 120k | Resistor_SMD:R_0603_1608Metric | 1
R187 | 820 | Resistor_SMD:R_0603_1608Metric | 1
R188 | 120k | Resistor_SMD:R_0603_1608Metric | 1
R189 | 120k | Resistor_SMD:R_0603_1608Metric | 1
R190 | 120k | Resistor_SMD:R_0603_1608Metric | 1
R191 | 100k | Resistor_SMD:R_0603_1608Metric | 1
R192 | 100k | Resistor_SMD:R_0603_1608Metric | 1
R193 | 100k | Resistor_SMD:R_0603_1608Metric | 1
R194 | 100k | Resistor_SMD:R_0603_1608Metric | 1
R195 | 82kΩ | Resistor_SMD:R_0805_2012Metric_Pad1.20x1.40mm_HandSolder | 1
R196 | 2k2 | Resistor_SMD:R_0603_1608Metric | 1
R197 | 10k | Resistor_SMD:R_0603_1608Metric | 1
R198 | 10k | Resistor_SMD:R_0603_1608Metric | 1
SW1 | TS-1088-AR02016 | esp32_button:SW_TS-1088_XNP-M | 1
SW2 | TS-1088-AR02016 | esp32_button:SW_TS-1088_XNP-M | 1
U1 | TPS51385RJNR | 20v-5v-buck:VQFN-HR12_RJN_TEX | 1
U2 | TVS2200DRVR | Package_SON:WSON-6-1EP_2x2mm_P0.65mm_EP1x1.6mm | 1
U3 | TS5A3159ADBVR | Package_TO_SOT_SMD:SOT-23-6 | 1
U4 | TLV7031DBVR | Package_TO_SOT_SMD:SOT-23-5 | 1
U5 | LM5155DSSR | 24V_boost_ic:WSON-12_L3.0-W2.0-P0.50-BL-EP | 1
U6 | TLV7031DBVR | Package_TO_SOT_SMD:SOT-23-5 | 1
U7 | TLV7031DBVR | Package_TO_SOT_SMD:SOT-23-5 | 1
U8 | CYPD3177-24LQXQT | usbc-pd:QFN24_CYPD3177-24LQXQT_INF | 1
U9 | TS5A3159ADBVR | Package_TO_SOT_SMD:SOT-23-6 | 1
U10 | TVS2700DRVR | Package_SON:WSON-6-1EP_2x2mm_P0.65mm_EP1x1.6mm | 1
U11 | BQ24640RVAR | supercap_charger:RVA16_2P14X2P14 | 1
U12 | TS5A3159ADBVR | Package_TO_SOT_SMD:SOT-23-6 | 1
U13 | TPS51385RJNR | 20v-5v-buck:VQFN-HR12_RJN_TEX | 1
U14 | TS5A3159ADBVR | Package_TO_SOT_SMD:SOT-23-6 | 1
U15 | TLV7031DBVR | Package_TO_SOT_SMD:SOT-23-5 | 1
U16 | TLV7031DBVR | Package_TO_SOT_SMD:SOT-23-5 | 1
U17 | USBLC6-2SC6 | Package_TO_SOT_SMD:SOT-23-6 | 1
U18 | TLV7031DBVR | Package_TO_SOT_SMD:SOT-23-5 | 1
U19 | TPS2121RUXR | power-mux:VQFN-HR-12_L2.5-W2.0-P0.50-BL | 1
U20 | TVS2200DRVR | Package_SON:WSON-6-1EP_2x2mm_P0.65mm_EP1x1.6mm | 1
U21 | TVS2200DRVR | Package_SON:WSON-6-1EP_2x2mm_P0.65mm_EP1x1.6mm | 1
U22 | LM73100RPWR | ss_ideal_diode:IC_LM73100RPWR | 1
U23 | LM73100RPWR | ss_ideal_diode:IC_LM73100RPWR | 1
U24 | LM73100RPWR | ss_ideal_diode:IC_LM73100RPWR | 1
U25 | TS5A3159ADBVR | Package_TO_SOT_SMD:SOT-23-6 | 1
U26 | TCA9535DBR | i2c_expander_no_pullup:SSOP-24_L8.1-W5.3-P0.65-LS7.8-BL | 1
U27 | TLV7031DBVR | Package_TO_SOT_SMD:SOT-23-5 | 1
U28 | TLV7031DBVR | Package_TO_SOT_SMD:SOT-23-5 | 1
U29 | TLV7031DBVR | Package_TO_SOT_SMD:SOT-23-5 | 1
U30 | TLV7031DBVR | Package_TO_SOT_SMD:SOT-23-5 | 1
U31 | TVS2200DRVR | Package_SON:WSON-6-1EP_2x2mm_P0.65mm_EP1x1.6mm | 1
U32 | TVS0500DRVR | Package_SON:WSON-6-1EP_2x2mm_P0.65mm_EP1x1.6mm | 1
U33 | TVS2200DRVR | Package_SON:WSON-6-1EP_2x2mm_P0.65mm_EP1x1.6mm | 1
U34 | TVS0500DRVR | Package_SON:WSON-6-1EP_2x2mm_P0.65mm_EP1x1.6mm | 1
U35 | LM73100RPWR | ss_ideal_diode:IC_LM73100RPWR | 1
U36 | LM73100RPWR | ss_ideal_diode:IC_LM73100RPWR | 1
U37 | LM73100RPWR | ss_ideal_diode:IC_LM73100RPWR | 1
U38 | LM73100RPWR | ss_ideal_diode:IC_LM73100RPWR | 1
U39 | TVS2200DRVR | Package_SON:WSON-6-1EP_2x2mm_P0.65mm_EP1x1.6mm | 1
U40 | TVS0500DRVR | Package_SON:WSON-6-1EP_2x2mm_P0.65mm_EP1x1.6mm | 1
U41 | TVS2200DRVR | Package_SON:WSON-6-1EP_2x2mm_P0.65mm_EP1x1.6mm | 1
U42 | TVS0500DRVR | Package_SON:WSON-6-1EP_2x2mm_P0.65mm_EP1x1.6mm | 1
U43 | TCA9535DBR | i2c_expander_no_pullup:SSOP-24_L8.1-W5.3-P0.65-LS7.8-BL | 1
U44 | TLV7031DBVR | Package_TO_SOT_SMD:SOT-23-5 | 1
U45 | TLV7031DBVR | Package_TO_SOT_SMD:SOT-23-5 | 1
U46 | TLV7031DBVR | Package_TO_SOT_SMD:SOT-23-5 | 1
U47 | TLV7031DBVR | Package_TO_SOT_SMD:SOT-23-5 | 1
U48 | TLV1117LV33DCYR | Package_TO_SOT_SMD:SOT-223-3_TabPin2 | 1
U49 | TLV70933PKR | 3v3-ldo:SOT-89-3_L4.3-W2.3-P1.50-LS4.3-BR | 1
U50 | TLV70933PKR | 3v3-ldo:SOT-89-3_L4.3-W2.3-P1.50-LS4.3-BR | 1
U51 | LM4040A25IDBZR | Package_TO_SOT_SMD:SOT-23 | 1

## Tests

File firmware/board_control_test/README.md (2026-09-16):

# TankerVision PDB control and power-good bench firmware

For automatic operation and Jetson integration, see the separate
[deployment firmware](../deployment/README.md) and [USB API](../deployment/API.md).
The procedures and hardware results below describe bench test builds, whose
20-second cancellable timeout differs from deployment's fixed 60-second shutdown.

Standalone Arduino ESP32 sketch for the fitted ESP32-S3-WROOM-1-N8R8. The reusable
`BoardControl.h/.cpp` driver contains hardware operations; `TestRunner.cpp` contains
the serial test application. The normal build starts tests only on a serial
command. The explicit `build-hold.sh` variant automatically enables the unloaded
charger after each reset for the requested meter measurement (see below).

For the connected **21.6 V supercap bank**, use the separate
[real-bank charging and transfer test](TRANSFER-TEST.md), built with
`build-transfer.sh`. It validates a 20 V/2 A PD request, charges with the real
temperature input, blinks D7 as a 1 Hz MCU heartbeat, and monitors backup takeover
with reset and uptime evidence. If main power remains absent for **20 seconds**,
it lowers GPIO42 to shut the board down with charge left in the bank. Main return
within that window cancels shutdown. Charging starts only on `transfer-start`. Keep its
`capture_transfer.py` serial session open throughout backup operation.
The [20-second shutdown results](results/shutdown-20s-2026-09-14/README.md) confirm
return cancellation, intentional timeout/power-off, retained bank charge, and
default output states after restart with the heartbeat running.
The [USB recovery diagnostic](USB-RECOVERY-TEST.md), built with
`build-usb-recovery.sh`, adds retained USB event/state evidence and a host capture
that observes intentional power-off and subsequent serial recovery. It preserves
the same charging, heartbeat and shutdown behavior.
The [USB recovery run](results/usb-recovery-2026-09-14/README.md) recovered serial
with J2 untouched after a delayed host reopen. Retained evidence distinguishes
the natural power-on boot from a second USB-induced reset caused by that reopen;
the earlier persistent silence was not reproduced.
The [real-bank results](results/transfer-2026-09-14/README.md) record a 20.67 V
meter-confirmed endpoint and two backup intervals (20.8 and at least 48 seconds)
without an ESP32 reset, with main-power return detected after each.

The first board passed **53 converter/port checks** plus the charger CE/PG test.
See the [2026-09-14 bench report](results/2026-09-14.md) for raw logs and limits.
The later [charger characterization](results/charger-2026-09-14/README.md) exercises
both temperature selections without the external supercap, including the TS
qualification timing fix. A subsequent [meter hold](results/hold-2026-09-14/README.md)
gave a user-reported **20.67 V** against the **20.629 V** target; the ADC/divider
measurement path still needs calibration.
The latest [tests 1/2/3/6](results/control-next-2026-09-14/README.md) passed backup
switching, both expander interrupt paths, and D7 control with user-confirmed visible
blinking. The PD interface was also exercised.
That upload restored normal off-at-boot behavior. Its PD communications passed,
but its zero operating-current request did not establish a usable charge budget.
The new transfer variant explicitly requests and verifies a sufficient contract
before enabling charging; see the transfer results for hardware validation.

The pin map was checked against a fresh KiCad XML export of
`tankervision-pdb.kicad_sch` and PCB pad nets on 2026-09-14. The earlier documentation
had incorrect input-bit assignments on **both** expanders and swapped CHG LED
references. See `schematic-map.json` and the corrected
[expander documentation](../../docs/blocks/io-expanders.md).

## Build and upload

Validated build toolchain: Arduino CLI 0.35.3, ESP32 Arduino core **3.3.3**. No
third-party Arduino libraries are needed. The build selects 8 MB flash, octal
PSRAM, and native USB Serial/JTAG CDC; it does not change eFuses or use pad JTAG.

```sh
sh firmware/board_control_test/build.sh
```

`build.sh` uses `ARDUINO_CLI`, `arduino-cli` on PATH, or the macOS Arduino IDE's CLI.
On another machine install `esp32:esp32@3.3.3` and use the same board options in
the script. Native USB is the **data-only J2** connector; power the board separately
at J1 (USB-C PD), or J6 with JP1 configured as documented.

Example upload using esptool 4.8.6 (replace the serial device):

```sh
python /path/to/esptool.py --chip esp32s3 --port /dev/cu.usbmodem2101 \
  --before usb_reset --baud 460800 write_flash --flash_size 8MB \
  0x0000 firmware/board_control_test/build/board_control_test.ino.bootloader.bin \
  0x8000 firmware/board_control_test/build/board_control_test.ino.partitions.bin \
  0xe000 /path/to/esp32/core/tools/partitions/boot_app0.bin \
  0x10000 firmware/board_control_test/build/board_control_test.ino.bin
```

The existing flash backup, when captured, is `results/pre-test-flash.bin` (ignored
by Git). `build/` contains the executable artifacts and is also ignored.

## First test

Use a valid 20 V USB-PD source and leave JP1 closed. Alternatively use only an
18.5–20 V DC source with JP1 open. For the first test, leave J7–J10 unloaded, or
connect only loads explicitly suitable for repeated power cycling and the labeled
voltages. This firmware does not read the negotiated PD current budget and is
therefore intended for unloaded control testing first.

Open serial at 115200 and send `status`, then `test`. For a timestamped capture:

```sh
python firmware/board_control_test/capture.py --port /dev/cu.usbmodem2101 \
  --command test --seconds 40 --log firmware/board_control_test/results/basic.log
```

The basic sequence reconciles retained outputs, checks the input and backed buck,
cycles the boost and unbacked buck, and cycles J7/J8/J9/J10 individually. Each
tested PG must be stable for 100 ms within 2 seconds. It checks other port PGs stay
low while one port is enabled. Each enabled stage has a 1.5-second LED dwell.
PG and input validity are polled throughout that dwell. `observation_ms` is the
post-command checking interval, not an oscilloscope measurement of startup time;
enable functions themselves also wait for stable PG before returning.
Errors stop the sequence and trigger cleanup; a failed read never becomes a PG
value. The final state has all controlled converters and output jacks disabled.

**J8 dependency:** `setPort(Port::FiveVoltVbus, true)` enables U13 and waits for
`5V_VBUS_PG` before enabling U36. Disabling J8 leaves the buck available to other
callers; the test explicitly disables it afterward. Disabling a buck under an
enabled J8 or disabling boost under an enabled charger is rejected.

| Stage | Expected electronic observation | LED / connector |
|---|---|---|
| Input baseline | exactly one of USB/DC PG high; backed buck PG high | D22 USB / D23 DC; D25 main selection; D3 backed 5 V |
| Boost U5 off → on → off | `24V_VBUS_PG` 0 → 1 → 0 | D2 |
| Buck U13 off → on → off | `5V_VBUS_PG` 0 → 1 → 0 | D16 |
| J7 U35 off → on → off | `EXT_VBUS_PG` 0 → 1 → 0 | D35; input-domain voltage |
| J8 U36 off → on → off | buck PG first, then `EXT_5V_VBUS_PG` 0 → 1 → 0 | D34; nominal 5.1 V |
| J9 U37 off → on → off | `EXT_SS_PG` 0 → 1 → 0 | D36; backed input-domain voltage |
| J10 U38 off → on → off | `EXT_5V_SS_PG` 0 → 1 → 0 | D37; nominal 5.1 V |
| Charger supply | `SCC_PG` high with valid charger input, including CE low | D12 CHG PG |

U1 backed buck and the three LDOs have no ESP32 enable. Their power presence can
be observed but firmware cannot toggle them individually. U22 USB and U23 DC input
switches are hardware-controlled, also without an ESP32 enable.

The disabled asynchronous boost still passes input power through L1/D1. **Boost
off is not a disconnected charger input.** BQ24640 PG indicates input validity,
not CE state or charging current. Its STAT can blink for CE low or TS faults. Thus
neither `SCC_PG` remaining high nor blinking D13 alone establishes a failure.
See [TI BQ24640 sections 7.3.14–15](https://www.ti.com/lit/ds/symlink/bq24640.pdf)
and [LM5155 PGOOD definition](https://www.ti.com/lit/ds/symlink/lm5155.pdf).

## Additional commands and full-board test set

| Command / bench step | Preconditions and evidence |
|---|---|
| `status`, `watch` | raw expander input/output bytes and decoded PG, mux source, VCAP and thermistor ADC; `watch` toggles periodic output |
| `control-next` | **No loads or supercap.** Tests backup-switch control from regulated VCAP, both expander interrupts, read-only PD HPI, and three visible D7 pulses. Ends with controlled outputs off; see sequence below |
| `pd` | Read-only CYPD3177 identity, raw version bytes, active fixed PDO/RDO and interrupt status on the dedicated bus; reports negotiated power budget, not measured current |
| `led-on`, `led-off` | visually confirm GPIO4 controls D7; D9 is the fixed 3.3 V power LED |
| `adc` | all nine ADC1 channels in averaged calibrated millivolts; compare VCAP ×9.2 to a meter and calibrate IMON against known loads |
| `charger-inhibit` | real NTC path electrically open, confirmed by TS ≥2.7 V; normally run with CN1 and J4 disconnected. Enables/disables CE briefly with open-NTC protection retained and no TS override. Checks input PG and expander pin readback; demonstrates CE control only, not charging |
| `charger` | connect a correctly rated, balanced, fused bank and real NTC; verify source current budget first. Uses low 1.03 A profile for about 2 seconds, checks TS/VCAP and supply PG, then disables CE before boost. Measure actual bank current externally |
| `charger-deep` | **CN1 supercap disconnected**, real sensor branch ≥2.7 V. Compares open-sensor inhibition with fixed-TS bypass, unloaded regulation at both current profiles, restart, and return to the real sensor; buffers voltage traces and shutdown decay locally |
| `charger-hold` | **CN1 supercap disconnected**. Holds VCAP high with fixed TS bypass and low-current selection until `off` or a detected fault. Other power tests require `off` first |
| `backup` | connect a charged bank (driver accepts 6–21 V) and retain valid main input. Cycles GPIO42 and checks VCAP PG on/off. Does not perform source-loss transfer |
| `off` | requests controlled converters and ports off; driver retains an active backup supply when main input is absent |
| Current selection | final firmware calls `setChargeHighCurrent()` only while CE is low. Validate both 1.03 A and 1.94 A against a meter with source budget and bank configured |
| TS selection | `setThermistorOverride(true)` selects the fixed divider; `false` restores the real NTC. Both require CE low and at least 100 ms charge-current decay. After selection, the function waits 100 ms for bypass or 500 ms for the real path to allow TS qualification. The `charger-deep` command exercises both selections; hot/cold calibration still needs a sensor fixture |
| Jetson button/feedback | call `setJetsonButton()` for a bounded pulse with J5 connected; observe J5 contact behavior and `jetsonOn` feedback. No Jetson button pulses are issued by the first test |
| Expander interrupts | probe GPIO15/16 while inducing PG transitions and correlate active-low INT with an input read; basic polling does not prove interrupt delivery |
| PD HPI | read-only identity, negotiated PDO/RDO and available current on GPIO40/41, address 0x08; verify GPIO39 interrupt on attach/contract events before adding source-budget control |
| Backup transfer | with bank and load characterized, scope main/backup rails and PMUX_ST during source removal/return; establish a load-aware energy cutoff. Requires dedicated supervision firmware, not the basic test loop |
| Reset retention | after enabling a known unloaded channel, reset ESP32 and verify logged retained state and off reconciliation; cold power cycle should restore TCA9535 input defaults |
| Load/analog validation | known resistive/capacitive loads, DMM/scope checks at each connector, current calibration and thermal measurements; PG alone does not prove regulation accuracy or load capacity |

## Next control sequence: tests 1, 2, 3 and 6

Build the normal `build.sh` variant, upload, then send `control-next`. The external
ports and CN1 must remain unloaded. This replaces the automatic meter-hold build;
reset and completion return the controlled outputs to off. No current ADC channels
are read by this sequence.

1. With controlled outputs off, `PdDiagnostics` uses the independent I2C controller
   on GPIO40/41 at 100 kHz, address 0x08, with a 25 ms bus timeout. It records three
   snapshots of CYPD3177 identity, raw version bytes, PD status, active PDO/RDO and
   GPIO39/interrupt status. It issues register-pointer reads only. It does not
   renegotiate power, reset the controller, or claim an unobserved PD event test.
2. `ExpanderInterrupts` installs GPIO15/16 edge handlers which only capture counts,
   timestamps and pending flags. I2C reads and acknowledgments stay in the main
   task. This preserves evidence of short interrupt pulses cleared by driver reads.
3. Enable boost and charger with fixed TS and the low-current profile. Qualify
   VCAP in the existing 19.8–21.4 V ADC screening window with steady STAT. Cycle
   GPIO42 three times while checking backup PG, main selection, regulation, and
   the corresponding U26 interrupt. For backup-off, observe INT low before a
   status read and confirm that the changed backup PG is read and INT releases.
4. Cycle the unbacked buck and each exterior port, observing the expected PG bits,
   interrupts on the correct expander, and released IRQ lines after reads. Keep
   the charger regulating for steady STAT. Pre-enable the buck for J8 so its port
   transition can be distinguished from the upstream converter transition.
5. Disable controlled power stages, then pulse GPIO4/D7 on for 1.5 seconds and off
   for 1.5 seconds, three times. Firmware reports pin readback; a person must
   confirm actual visible LED operation. Final GPIO4 and GPIO42 are low.

Backup arming is testable without a supercap because the charger maintains raw
VCAP. The standalone `backup` command does not establish that supply; use this
combined sequence for the no-bank setup. Source-loss transfer is not attempted.
Disconnecting J1 would also remove the ESP32's power in this setup, so live PD
detach/reattach interrupt validation remains a separate fixture test.

```sh
python firmware/board_control_test/capture.py --port /dev/cu.usbmodem2101 \
  --command control-next --seconds 50 --log /tmp/control-next.log
```

## Charger characterization without a supercap

Send `charger-deep` for the complete bounded sequence. The nominal CV target is
20.629 V. TI also tests the BQ24640 EVM with the load off in its
[EVM guide, section 2.4.2](https://www.ti.com/lit/ug/sluu410/sluu410.pdf), so unloaded
operation should reach regulation; no external bank is needed for this check.

Each active phase clears CE before emitting buffered CSV. Voltage is sampled using
the driver's 16-reading ADC average; 10 ms min/max/mean bins are retained, and
status/enable pin readback is checked nominally every 20 ms. The capture reports
the actual longest gap. An additional 1.5 seconds of shutdown readings are buffered
immediately after CE-low readback, before serial output. The CE call latency and
approximately 1.1 ms ADC filtering limit what can be concluded about fast edges.

The software trips above a measured 21.5 V. The final two seconds of a regulation
phase must stay within 19.8–21.4 V, span no more than 0.5 V, and report steady STAT
high. This is a coarse ADC screening window, **not** validation of the charger's
tighter 20.36–20.94 V calculated tolerance or switching ripple. Open-sensor phases
must remain below 2 V throughout the capture and exhibit STAT transitions.

The BQ24640 specifies a typical 400 ms temperature-out-of-range deglitch interval.
The first characterization used only 100 ms between restoring the real path and
asserting CE: VCAP briefly reached the high rail before the TS fault stopped
charging. The reusable selection function now waits 500 ms with CE low when
restoring the real sensor. This timing wait does not measure U11 TS or replace
normal firmware checks of the real sensor voltage.

GPIO1 reads the real sensor branch regardless of the selection. Its approximately
2.91 V reading should remain unchanged while U14 applies the fixed approximately
1.65 V divider to the charger's TS pin. The firmware has no ADC on U11 TS itself.

```sh
python firmware/board_control_test/capture.py --port /dev/cu.usbmodem2101 \
  --command charger-deep --seconds 85 --log /tmp/charger.log
python firmware/board_control_test/analyze_charger.py /tmp/charger.log --plot
```

The analyzer exports normalized CSV, JSON, and optional PNG/SVG plots (`--plot`
requires matplotlib). The bypass API has no autonomous timeout; the characterization
sequence supplies its own bounded interval and restores CE, boost, bypass, current
selection, backup, and exterior enables to off/default. The separately requested
meter hold below instead keeps the unloaded rail on under continuous polling.

## Leave VCAP high for a meter measurement

The [2026-09-14 hold report](results/hold-2026-09-14/README.md) records the uploaded
automatic hold variant and its live/reconnect verification. It was left running
for the requested meter check. The user then measured **20.67 V** with a multimeter.

With the external supercap disconnected, build the explicit automatic hold variant
and upload it using the same esptool command above:

```sh
sh firmware/board_control_test/build-hold.sh
```

This build selects `setThermistorOverride(true)`, the low 1.03 A current limit,
and enables boost followed by charger CE. It leaves the external output switches,
unbacked 5 V converter, and backup switch off. It intentionally starts again after
**every ESP32 reset**, including a reset caused by opening/closing USB serial.
The ordinary `build.sh` build still starts with all controlled outputs off.

Measure **CN1 pin 1 (+) to CN1 pin 2 (−/GND)**. The schematic target is approximately
**20.63 V**. The user measured **20.67 V**, about 0.2% above target. The ADC estimate
of about 20.23 V is approximately 0.44 V / 2.1% low at this operating point;
ADC/divider calibration remains outstanding. `VCAP_PG`/`CAP` remains low because
it senses the disabled backup switch's output, not raw VCAP at CN1.

`ChargerHold::start()`, `service()`, and `stop()` provide reusable mode control.
The application polls every approximately 20 ms without waiting for USB. Startup
must qualify VCAP at 19.8–21.4 V with STAT high for 100 ms within two seconds.
While holding, it checks that voltage window, supply/boost/charger PG, output
configuration/readback, and inactive output PGs. A reading above 21.5 V trips
immediately even during startup. These are software ADC checks, not measurements
of switching ripple or calibrated protection thresholds. Faults latch and request
all outputs off; `status` reports the fault and shutdown result. No automatic retry
occurs within the running session.

There is **no time limit** while holding. Send `status` or `watch` at 115200 baud
for VCAP and hold-state readings. Send `off` to stop; it stays stopped until an
explicit `charger-hold` command or reset. Power removal ends the measurement;
this special build enables charging again when power returns. Stop before
connecting a supercap or load. Rebuild/upload with `build.sh` when the automatic
measurement mode is no longer wanted.

## Reuse in final firmware

Include `BoardControl.h` and instantiate `BoardControl`. `begin(Stream&)` records
retained expander state and reconciles it to off. All setters return success/failure;
read `error()` immediately after a failure. Output register, direction, polarity,
and driven pin levels are checked. P0 remains inputs; unused P1 pins remain inputs.
The TCA9535 output latch is programmed before enabling its output drivers, following
the [TI register definition](https://www.ti.com/lit/ds/symlink/tca9535.pdf).

The driver is synchronous and intended to be called from one task. A final power
manager must supply source budget policy, continuous voltage/temperature guards,
fault handling, watchdog behavior, and backup sequencing. The initial test records
those remaining validations separately from observed control/PG passes.

Opening or closing the native USB serial device can reset the ESP32 on this host.
The startup register dump is buffered for later `status` requests. Use one open
serial session for manual multi-command experiments, and inspect boot messages
before interpreting state retention across a host reconnect.

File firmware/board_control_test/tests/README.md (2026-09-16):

# Host driver checks

Run `sh firmware/board_control_test/tests/run.sh` with a C++17 compiler.
The tests compile the actual `BoardControl.cpp` and `ChargerHold.cpp` against small
Arduino/Wire mocks.
They exercise unavailable expanders during retained-state recovery, a CE pin stuck
high, retained polarity inversion, the corrected schematic input map, J8's buck
dependency and timeout, and CE-before-boost shutdown ordering.
Thermistor checks cover both selections, preserving the other outputs, CE-high
refusal, the 100 ms CE-low delay, the post-switch 100 ms override / 500 ms real-NTC
settling waits before a subsequent CE command, direction/latch/physical-pin faults,
and restoring the real NTC during shutdown or initialization with a retained bypass
state.

Measurement-hold checks cover continuous regulation qualification, twelve minutes
of operation without a duration limit, manual stop, latched overvoltage shutdown,
source/PG/STAT loss, expander read failure with incomplete-cleanup reporting, the
open physical thermistor while fixed TS is selected, and startup undervoltage
timeout. ADC readings are configurable; the idealized fixture asserts charger
STAT when CE and the temperature bypass are both enabled.

The mock models TCA9535 paired registers, output direction, polarity and physical
output readback. Time advances without sleeping. PG behavior is an idealized
fixture response; these tests establish software decisions and sequencing, not
electrical timing, voltage regulation or real fault protection.

Additional diagnostics checks:

- `sh firmware/board_control_test/tests/run-expander.sh`: seven cases for separate
  GPIO interrupt capture, short pulses, read acknowledgment, read failure,
  concurrent events and scoped-handler cleanup.
- `sh firmware/board_control_test/tests/pd_run.sh`: read-only little-endian HPI
  transport, decoding, failed-read isolation, malformed responses, IRQ consistency,
  and the actual zero-current RDO reported separately as an unvalidated power request.

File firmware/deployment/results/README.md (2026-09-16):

# Deployment development verification — 2026-09-16

This records the compiled and host-tested development build. The subsequent
[2026-09-16 upload and telemetry check](upload-2026-09-16/README.md) records its
first physical ESP32 deployment. Loaded Jetson shutdown still requires integration
testing. Historical bench results apply to the separate `board_control_test`
firmware.

## Build

`sh firmware/deployment/build.sh` passed using Arduino CLI 0.35.3 and ESP32 core
3.3.3. See [build.log](build.log). The final incremental build reported no compiler
warnings, 438,531 bytes of flash and 105,624 bytes of global RAM (222,056 bytes
remaining in the reported static allocation budget). These figures are not a
measurement of runtime stack/heap margins.

All production `.cpp` and `.h` files match the compiler's sketch copies. The
SHA-256 manifest records production source, host client/test files and generated
application/bootloader/partition images for this verification snapshot. Generated
images are in the ignored `../build/` directory and can be reproduced with the
documented toolchain.

## Host checks

| Check | Result |
|---|---|
| `tests/run-power-manager.sh` | 28 policy scenarios passed: startup order, charge progress/failure/maintenance, backup arming, main loss, reboot, immutable deadlines, stale completions and timer rollover. |
| `tests/run-hardware.sh` | Passed actual hardware-driver tests against an I2C register model: read-only settling, real-temperature qualification, CE-before-boost shutdown, PG timeouts, preemption, J8 converter sequencing, rollback, expander defaults and complete sampling. |
| `tests/run-protocol.sh` | 12 scenarios passed, including 20,000 randomized input streams under undefined-behavior sanitization. |
| `tests/run-pd.sh` | 35 scenarios passed under undefined-behavior sanitization: request contents, verified contract response, freshness, insufficient budget, I2C failures and timeout/rollover. |
| `tests/run-application.sh` | Three actual application/policy/parser/USB queue integration scenarios passed with simulated board/PD/USB: 356 JSON frames and 172 telemetry snapshots independently validated; see [application-tests.log](application-tests.log). |
| Python `unittest` discovery in `jetson/` | 28 tests passed: 24 client tests and four cleanup-hook tests. No serial device was opened and no host shutdown action was executed. |

Application tests cover continuous settling telemetry, matching pong, asynchronous
port controls, main loss with immediate return, staged unbacked-port shedding,
ACK/ready without deadline changes, full reboot with main present, defaults before
backup release, no hardware work after release, USB reconnect framing and runtime
charger fault handling. JSON output is parsed independently and checked for all
nine ADC channels, 30 named digital signals and expander/PD telemetry.

## Schematic evidence and remaining hardware acceptance

The schematic and PCB SHA-256 values match the prior audited
[`schematic-map.json`](../../board_control_test/schematic-map.json):

```text
schematic fe40a02cf6cebcd3f4909c79bb2411796b1a13390b0c5edc303da37153d90239
pcb       88b42dc8079ee75d50be56a2138377d0cd0d8bb0ad311b51be9ec2db7a48d808
```

A fresh KiCad XML export on 2026-09-16 rechecked the expander signal map, ADC
connections and divider/current-sense resistor values. GPIO0 requires its internal
pull-up during operation because the schematic has no external pull-up. This
review did not rerun ERC or DRC.

The [first upload report](upload-2026-09-16/README.md) now establishes the 3 A
USB-PD request, charger maintenance, automatic J9/backup controls with PG, complete
1 Hz telemetry and same-boot serial reopen on the Mac. Hardware acceptance still
includes the remaining procedure in the [firmware README](../README.md): optional
port commands, USB behavior on the Jetson, actual cleanup and Linux poweroff,
backup endurance under the installed load, and main-return/full-reboot behavior.
ADC current estimates are nominal and require calibration before being used as
quantitative load evidence.

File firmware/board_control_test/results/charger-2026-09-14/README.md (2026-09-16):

# Charger characterization without the external supercapacitor

**The bypass, unloaded regulation, restart, current selection, and restored
temperature inhibition tests passed. A subsequent meter hold measured 20.67 V
against the 20.629 V schematic target.** The user confirmed that CN1 had no
supercapacitor connected.

Final run: **2026-09-14 19:26:37 UTC / 15:26:37 America/Toronto**, ESP32-S3 MAC
`68:ee:8f:58:b0:10`. Firmware uses the schematic-verified U26 P11 CE, P12 ISET,
P13 TS selection, and P10 boost enable. Backup and exterior outputs stayed off.

| Test | Settled VCAP estimate, mean | Final-window range | Charger STAT |
|---|---:|---:|---|
| Real sensor selected, open sensor, CE high | 0.6197 V | 0.6072–0.6256 V | blinking |
| Fixed TS bypass, low 1.03 A selection | 20.2289 V | 20.1756–20.2400 V | steady high |
| Restart with fixed TS bypass | 20.2234 V | 20.1756–20.2400 V | steady high |
| Fixed TS bypass, high 1.94 A selection | 20.2268 V | 20.1756–20.2400 V | steady high |
| Return to real open sensor, CE high | 0.6204 V | 0.6164–0.6256 V | blinking |

The charger input PG and boost PG remained asserted throughout the monitored
boost-on phases. CE, TS select, and ISET register values were checked against
physical expander pin readings. Both current selections produced the same settled
voltage to the resolution of this test. **The stated 1.03/1.94 A values describe
selected profiles; output current was not measured with the bank absent.**

GPIO1 stayed near 2.909 V in both temperature modes. This is expected because it
measures the real sensor branch. U14 selects the fixed nominal 1.65 V divider for
U11 TS during bypass; there is no ESP32 ADC connection to U11 TS itself.

## Voltage accuracy and sampling limits

The schematic target is **20.629 V**. This run's ESP32 estimate was approximately
**20.229 V**, about **0.400 V / 1.94% lower**. In the subsequent
[unloaded meter hold](../hold-2026-09-14/README.md), the user reported **20.67 V**
with a multimeter: about **0.20% above target**, inside the calculated
20.36–20.94 V tolerance at this operating point. This resolves the apparent
low-output concern. The ADC estimate is approximately **0.44 V / 2.1% below**
the meter result; the ADC/divider path still requires calibration. The divider
continues to use nominal ×9.2 scaling. The original ADC logs are unchanged.

The [ESP32-S3 datasheet, ADC characteristics](https://documentation.espressif.com/esp32-s3_datasheet_en.pdf)
lists up to ±50 mV total ADC error at the selected attenuation under its stated
conditions, equivalent to ±0.46 V after ×9.2 scaling before divider/board effects.
That indicates the scale of uncertainty, not a measured error bar for this board.

Each voltage sample averages 16 ADC readings. Data are grouped into 10 ms
min/max/mean bins; digital status is refreshed nominally every 20 ms. The longest
observed ADC gap was approximately **8.0 ms**. CE setters took roughly 9–10 ms;
capture starts after their readback returns. The analog path has approximately
1.1 ms filtering. Consequently, the observed maximum **20.2492 V** is a sampled
estimate, not a measurement of fast overshoot or switching ripple.

Regulation was judged using a deliberately broad 19.8–21.4 V ADC screen, no more
than 0.5 V spread, and steady STAT in the final two seconds. The measured final
spread was approximately **0.0644 V** in the three enabled bypass cases. A sampled
21.5 V guard was never triggered. It is a software bench guard, not a substitute
for the charger's hardware protection.

## Temperature-selection timing finding and correction

The first run used 100 ms settling after restoring the real open sensor. VCAP
reached approximately 20.22 V for about **0.29 seconds after the CE call returned**,
then fell toward the inhibited level. This is consistent with the BQ24640's
**400 ms typical temperature-out-of-range qualification delay**, with about
100 ms already elapsed before CE was re-enabled. The datasheet specifies 20 ms
for qualification back into the valid range.

The reusable `setThermistorOverride()` now keeps CE low and waits **100 ms after
selecting bypass, or 500 ms after selecting the real sensor**, in addition to the
existing 100 ms current-decay interval before switching. The final run's restored
real-sensor phase remained below **0.6532 V for the entire capture**, eliminating
the high-voltage pulse seen with the short delay on this board.

The first log says PASS because its inhibition criterion checked the settled
window only. The final criterion checks the entire open-sensor capture below
2 V, as well as STAT transitions. Both original and final logs are preserved.
This distinction matters when reviewing the first trace.

`begin()` and `allOff()` also restore the real sensor while leaving CE low; they do
not add this post-selection wait themselves. Call the explicit selector before an
immediate restart when the TS qualification wait is required. A final power manager
should independently reject an invalid real-sensor reading before requesting charge.

## Shutdown and artifacts

Shutdown traces were buffered immediately after verified CE-low, before serial
printing. In the low-current bypass case, the first shutdown sample was about
20.019 V and it fell to **1.564 V after 1.5 seconds**. The following disabled phase
continued down below 0.04 V. Other bypass cases showed similar decay. CE-off is
therefore effective; the rail does not discharge instantaneously despite no external
bank because the board still has roughly 16.7 µF of nominal VCAP capacitance.

The final result was `RESULT CHARGER_DEEP PASS cleanup=PASS`, with internal output
latch/pins `00/00`, exterior output latch `00`, low current selected, and the real
sensor restored. No schematic or PCB edits were required.

- [Final voltage plots](hardware-final.png) / [SVG](hardware-final.svg)
- [Final raw serial log](hardware-final.log), [normalized CSV](hardware-final.csv), [JSON summaries](hardware-final.summary.json)
- [First run including the return pulse](hardware.png), [raw log](hardware.log)
- [Final independent status read](final-status.log)
- [Final build](build-final.log), [verified upload](upload-final.log), [source/binary hashes](build-manifest.json)
- [15 passing host tests](host-tests.log), including temperature-selection timing and failure handling

Primary behavior references: [BQ24640 datasheet](https://www.ti.com/lit/ds/symlink/bq24640.pdf),
sections 6.5, 7.3.7, and 7.3.12–15; the
[BQ24640 EVM guide](https://www.ti.com/lit/ug/sluu410/sluu410.pdf), section 2.4.2,
explicitly tests unloaded output regulation with steady PG/STAT.

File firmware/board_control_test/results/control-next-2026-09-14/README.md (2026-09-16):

# Tests 1 / 2 / 3 / 6 — 2026-09-14

Executed on ESP32-S3 `68:ee:8f:58:b0:10`, with USB main power, no external loads
and no supercap. The complete sequence began at **20:06:20 UTC / 16:06:20 Toronto**.

**Backup switching and both expander interrupt paths passed. PD communication
passed, but the requested power budget remains unresolved. D7 GPIO control and
visible LED operation both passed, with the user confirming the repeat run.** No ADC current channels
were read. The automatic VCAP meter hold was replaced by the normal off-at-boot
test build, and controlled outputs were left off.

## Backup switch and expander interrupts

The charger maintained unloaded VCAP with low-current selection and fixed TS
bypass. GPIO42/U24 was enabled and disabled **three times**. Each on command
changed U26 inputs `DC → FC` and each off command restored `FC → DC`, confirming
backup PG assertion/deassertion. Main selection remained high. The VCAP ADC stayed
within its screening window; this did not meter-measure `+VCAP_VALID` or perform
a source-loss transfer.

There were **18 successful PG/interrupt transitions**: six backup transitions,
four buck transitions, and eight transitions across J7–J10. Every transition
produced exactly one captured falling edge and one rising edge on the expected
expander INT pin, and none on the other pin. Both lines were released afterward.
J8's upstream buck was enabled before the port tests to separate its two PG events.

All three backup-off cases observed internal INT held low before an input read,
read the expected changed backup-PG bit, and observed INT high afterward. This
proves input-read acknowledgment as well as GPIO15 routing. The GPIO16 events
were captured even when the existing setters' register reads cleared them before
returning. ISR handlers contain no I2C or serial operations.

## PD result and current-request finding

Three complete, stable HPI snapshots reported:

| Field | Observed value |
|---|---|
| Device mode / silicon ID | `0x95` / `0x2004` |
| PD status / Type-C status | `0x000DA400` / `0x8B` |
| Active source PDO | `0x000641D6`: fixed **20 V, 4.7 A**, advertised maximum **94 W** |
| Active RDO | `0x4080000A`: object 4, **0 mA operating, 100 mA maximum**, mismatch clear |
| GPIO39 / HPI interrupt register | Low / `0x01` pending |
| Naturally observed PD interrupt edges | Zero during the read window |

The initial checker rejected zero operating current and returned an overall
`CONTROL_NEXT FAIL` despite 73 successful control checks. Review of the exact
CYPD3177 behavior established that zero agrees with the board's grounded ISNK
pins: [Infineon's CY4533 guide, section 2.4](https://www.infineon.com/assets/row/public/documents/24/44/infineon-cy4533-ez-pd-barrel-connector-replacement-evk-guide-usermanual-en.pdf)
specifies that their configured sum becomes the RDO operating current.

The final uploaded diagnostic distinguishes **COMMUNICATION PASS** from
**POWER_REQUEST UNVALIDATED**, with an overall **PARTIAL** PD result and a false
return value. The source's 94 W advertisement does not establish that allowance
for the board. The origin of the observed 100 mA maximum field is not explained
by the available documentation. Current-request configuration needs resolution
before loaded operation; no contract/configuration change was made in this test.

No PD event was generated or acknowledged. The low GPIO39 agrees with a pending
register bit, but fresh-event delivery and acknowledgment remain untested. Raw
version bytes are recorded without claiming a silicon firmware revision. See
[PD reference notes](../../PD-REFERENCES.md) for exact scope and documentation.

## LED and completion state

GPIO4 readback passed for three **1.5-second on / 1.5-second off** D7 pulses.
The user subsequently requested another `control-next` run, captured at
**20:16:20 UTC / 16:16:20 Toronto** in [manual-repeat.log](manual-repeat.log), and
confirmed that the status LED blinked as expected. D7 visual operation is now
**PASS**. The raw log's `visual_confirmation=PENDING` text predates the user's
confirmation and is preserved unchanged.

The full sequence ended with `OUT=00`, `EOUT=00`, GPIO42=0, GPIO4=0 and VCAP ADC
0.0000 V, main input selected. There were **73 passing control checks and zero
failed control checks**; the separate PD request check prevented an overall pass.

## Evidence

- [Complete hardware log](hardware.log): backup, both interrupt paths, PD and D7.
- [User-requested repeat](manual-repeat.log): the full sequence on the final
  uploaded firmware; another 73 control checks passed and D7 was visually confirmed.
- [Initial build](build.log), [verified upload](upload.log), [initial source/binary hashes](build-manifest-first.json).
- [Final PD reporting build](build-final.log), [final upload](upload-final.log), [PD retest](pd-final.log), [final status](final-status.log), [final hashes](build-manifest.json).
- [23 existing driver/hold host checks](host-tests.log), [7 interrupt host checks](irq-host-tests.log), [PD transport/decoder host checks](pd-host-tests.log).

The reporting update only changed `PdDiagnostics.h/.cpp`. Backup, IRQ and LED
sequence code is unchanged from the full hardware run. The final upload was
retested with `pd` and `status`, then the full sequence was repeated at the user's
request for the visual LED check.

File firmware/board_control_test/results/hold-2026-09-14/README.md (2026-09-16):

# VCAP meter hold — 2026-09-14

Uploaded the explicit hold-on-boot firmware to ESP32-S3 `68:ee:8f:58:b0:10` at the
user's request, with the external supercap disconnected. **The charger was left
enabled for the meter measurement.** This differs from the earlier bounded tests.

The firmware selects the fixed thermistor bypass, low-current setting, boost and
charger CE. It qualifies regulation and then monitors it without a duration limit.
The reusable implementation is `ChargerHold.h/.cpp`; build using `build-hold.sh`.
The uploaded binary's source hashes and explicit build flag are recorded in
[build-manifest.json](build-manifest.json).

Observed in the [20-second capture](hardware.log) and subsequent
[8-second reconnect capture](reconnect.log):
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

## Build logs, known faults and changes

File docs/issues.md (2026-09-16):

# Issues, Accepted Constraints, and Release Checks

## Deployment firmware development — 2026-09-16

The separate [deployment firmware](../firmware/deployment/README.md) implements
automatic startup, 1 Hz complete USB telemetry, charger maintenance, Jetson port
control, and a fixed 60-second shutdown allowance. Main return cannot cancel this
shutdown. It defaults both expanders before releasing backup and restarts if
power remains. D7 is solid during the initial 10 seconds and a heartbeat afterward.
The [Jetson API](../firmware/deployment/API.md) and reference client document
pings, shutdown acknowledgment/readiness, optional-port commands and full reboot.

The deployment build uses software USB CDC with reboot hooks disabled before
enumeration. The [first deployment upload and telemetry check](../firmware/deployment/results/upload-2026-09-16/README.md)
passed flash verification and received 158 telemetry snapshots: a verified 20 V/3 A
contract, real-temperature charging to 20.47 V ADC, maintenance enabled, backup
armed, J9 enabled with PG, and no reported issues. Closing/reopening serial on the
Mac preserved boot ID and increasing uptime. Loaded Jetson shutdown and USB
behavior on the Jetson still require integration testing. Earlier bench results
below apply to their named test firmware, not this deployment build.

## Historical transfer-test policy — 2026-09-14

The transfer test firmware waits **20 seconds after detected main-power loss**.
Valid main return cancels shutdown; otherwise it records `MAIN_TIMEOUT_20S` and
deasserts GPIO42, disconnecting the board from the still partly charged bank.
The existing 7 V low-energy cutoff can act sooner. D7 is now a 1 Hz loop-driven
MCU heartbeat, independent of capacitor voltage. The 10 V backup-arming threshold
remains. The voltage-indicator and long-backup observations below describe older
test versions. See the
[current procedure](../firmware/board_control_test/TRANSFER-TEST.md).

Bench validation passed: return after 6.700 s cancelled shutdown; the next loss
produced the timeout marker after **20.003 s**, then GPIO42 release and board
power loss. VCAP was 20.3136 V ADC at cutoff and still 19.964 V ADC after main
restoration. The stored `MAIN_TIMEOUT_20S` checkpoint survived; all controlled
outputs were off and D7 resumed its heartbeat. USB telemetry needed a J2 data
reconnection after the deliberate power cycle. See the
[20-second test report](../firmware/board_control_test/results/shutdown-20s-2026-09-14/README.md).

## Firmware pin-map correction — 2026-09-14

A fresh schematic XML netlist and saved-PCB pad-net comparison found that the
documentation accompanying the 2026-08-24 review listed several U26/U43 Port 0
inputs in the wrong order. The corrected tables in
[io-expanders.md](blocks/io-expanders.md) now follow the electrical connections
through their series resistors. The output-enable and ESP32 GPIO assignments were
correct. Related block documentation now also uses the actual charger LED mapping
(`SCC_PG` → Q8/D12; `SCC_STAT` → Q9/D13) and enable-pulldown references. D9 is
the `+3V3_SS` power LED; D7 is the GPIO4-controlled green status LED.

This check compared 1,366 named PCB pads with the exported schematic; net names
agree after normalizing KiCad's slash escaping. It did not rerun ERC or DRC and
does not establish bench functionality. The ERC/DRC results below remain the
historical 2026-08-24 results.

## Initial firmware bench results — 2026-09-14

The connected ESP32 completed 53 converter/output-control checks with no failures:
boost, unbacked 5 V buck, and all four exterior port PGs asserted/deasserted as
expected, including the J8 upstream-buck dependency. Charger CE high/low pin
readback and input PG also passed with the real thermistor path left selected and
TS reading approximately 2.91 V. The latter test does not validate charging current.

During that open-TS test, the VCAP ADC estimate rose from 0 V to about 0.62 V and
fell after CE was cleared. Its cause remains unverified; compare against a DMM or
scope before judging charger leakage or ADC accuracy. Charging under load and
backup transfer remain outstanding. See the
[bench report and raw logs](../firmware/board_control_test/results/2026-09-14.md)
and [full test set](../firmware/board_control_test/README.md).

## Charger bypass and unloaded regulation — 2026-09-14

With the external supercap confirmed disconnected, the fixed-TS bypass allowed
steady unloaded operation: ESP32 VCAP estimates were about 20.229 V at the low
current selection, 20.223 V after restart, and 20.227 V at the high selection.
STAT remained high and charger/boost PG remained asserted. Selecting the real
open-sensor branch gave about 0.62 V and blinking STAT.

A first return-to-real-sensor test re-enabled CE only 100 ms after changing TS and
produced an approximately 300 ms high-voltage pulse before temperature inhibition.
The BQ24640 specifies 400 ms typical temperature-out-of-range qualification.
`setThermistorOverride(false)` now waits 500 ms with CE low; retesting kept the
entire restored-real-sensor capture below 0.654 V. The bypass direction waits
100 ms. All 15 driver host tests pass, including these timing guarantees.

During the subsequent unloaded, low-current hold with fixed-TS bypass, the user
measured **20.67 V with a multimeter**, approximately **0.041 V / 0.20% above the
20.629 V schematic target**. This supports correct regulation at this operating
point and resolves the apparent low-output concern. The approximately 20.23 V
ADC estimate is **0.44 V / 2.1% low relative to the meter**; ADC/divider calibration
and verification remain outstanding. This high-rail measurement does not resolve
the separate 0.62 V inhibited-state observation. Loaded charge current and switching
ripple also remain untested. See the
[meter hold report](../firmware/board_control_test/results/hold-2026-09-14/README.md) and
[charger report, traces, and raw logs](../firmware/board_control_test/results/charger-2026-09-14/README.md).

## Additional ESP32 control tests — 2026-09-14

With no loads or supercap connected, the charger maintained VCAP while GPIO42
cycled the backup switch three times. Backup PG rose/fell on each command and the
mux remained on main power. Both expander interrupt connections passed: 18 PG
transitions produced falling/rising edges on the expected GPIO15/GPIO16 line.
Three backup-off checks observed INT low before reading inputs, the expected
changed PG bit, and INT high after the read. This establishes backup-switch control
and interrupt delivery; source-loss transfer was not attempted.

GPIO4 high/low readback passed for three D7 pulses, and the user confirmed visible
status-LED blinking during the requested repeat run. All controlled outputs finished off. No current ADC
channels were read.

PD HPI communications worked at 0x08 on GPIO40/41. The active source PDO advertised
**20 V / 4.7 A (94 W)**, but RDO `0x4080000A` reported **0 A operating current and
0.1 A maximum**. The grounded ISNK pins explain the zero operating request; the
source PDO ceiling is not a validated requested power budget. A later real-bank
charge test resolved the request for its low-current setup: the verified HPI sink
profile changed the active RDO to `0x408320C8` (**20 V, 2 A operating/maximum**),
stable for 503 ms before CE high. The setting is volatile and needs revalidation
after PD power loss; external-load budgets remain untested. GPIO39 was low with HPI
`INTERRUPT=0x01`; generated-event delivery and acknowledgment remain untested.
See the [test report](../firmware/board_control_test/results/control-next-2026-09-14/README.md)
and [PD configuration notes](blocks/usbc-pd.md).

## Real-bank charging and backup observation — 2026-09-14

With the user's 21.6 V bank and temperature resistor connected, the dedicated
transfer firmware charged with real TS selected and low ISET. It first verified
a 20 V/2 A active PD request. D7 turned on above 10 V ADC and GPIO42 armed the
backup switch with PG confirmation. A stable 20.46 V ADC plateau corresponded to
the user's **20.67 V** meter reading, close to the 20.629 V design target.

Removing main power produced GPIO11 transitions, USB PG low and backup selection.
The ESP32 maintained the same session and continuous uptime through **20.790 s**
of confirmed backup operation; backup PG and backed 5 V PG stayed high in all 21
backup heartbeats. Firmware lowered charger CE, then boost, while retaining
GPIO42. Main/USB indications subsequently returned high and charging stayed off.
A second loss produced **49 consecutive backup heartbeats spanning 48.046 s**,
again without reset, followed by another main-power return. The second interval
exposed a one-shot reporting bug (`RETURNED` label and old duration despite correct
raw PG inputs). Per-episode state/timing/reporting now resets on every loss, with
25 supervisor regression scenarios passing. The second interval's continuity is
verified from raw PG and uptime; the initial firmware did not emit its automatic
30-second marker on that repeated loss.

No current ADC channels were read. This supports observed unloaded backup
continuity with no detected reset/brownout, not measured rail droop or loaded
transfer performance. See the
[capture and report](../firmware/board_control_test/results/transfer-2026-09-14/README.md).

## Previous CAD verification — 2026-08-24

Verified 2026-08-24 against the current schematic and completed PCB with KiCad
9.0.7, fresh ERC, parity-aware PCB DRC, and a targeted audit of the normally ignored
silkscreen checks. ERC reports **0 errors and 0 warnings**. PCB DRC reports **0
violations, 0 unconnected items, 0 footprint errors, and 0 schematic-parity
issues**. The solder-mask changes pass DRC; the ordered via process and the library
choices below are manufacturing decisions rather than unresolved CAD blockers. See
[pcb-layout.md](pcb-layout.md) for the physical-layout evidence.

The production BOM contains 444 fitted references grouped into 84 unique orderable
parts. Every fitted reference has a manufacturer, manufacturer part number, and
JLCPCB/LCSC part number. The eight intentionally excluded footprints are FID1–FID3,
JP1, and MH1–MH4.

Final principal references are U8 CYPD3177, U19 TPS2121, U22/U23/U24 input and
supercap LM73100 switches, U26/U43 TCA9535 expanders, U11 BQ24640, U48
TLV1117LV33, U49/U50 TLV70933, and U51 LM4040A25.

## Schematic design-freeze status

The ESP32 pinout correction is valid and this review finds no remaining electrical
schematic blocker; the free-text cleanup listed below remains before documentation
freeze. On IC1 `ESP32-S3-WROOM-1-N8R8`:

- GPIO35–GPIO37 are no-connect, as required by the module's octal PSRAM;
- `CTRL_SDA`/`CTRL_SCL` use GPIO17/GPIO18 with R35/R36 2.2 kΩ pull-ups;
- `CTRL_IN_INT_N`/`CTRL_EXT_INT_N` use GPIO15/GPIO16;
- `PD_SDA`/`PD_SCL` use GPIO40/GPIO41 and `PD_INT` uses GPIO39;
- `VCAP_EN` uses GPIO42, `STAT_LED` uses GPIO4, and `PMUX_ST` remains on GPIO11;
- all nine analog measurements use ADC1-capable GPIO1–GPIO3 and GPIO5–GPIO10; and
- native USB remains on GPIO19/GPIO20 and UART0 remains on its module pins.

GPIO39–GPIO42 are also the optional pad-JTAG pins. The board uses them for `PD_INT`,
PD I²C, and `VCAP_EN`, so firmware must retain the default USB Serial/JTAG path or
permanently disable pad JTAG. IO3 `VIMON_DC` is the JTAG-source strap, but the
default `EFUSE_STRAP_JTAG_SEL = 0` configuration ignores its level.

Reference: [ESP32-S3-WROOM-1/1U datasheet](https://documentation.espressif.com/esp32-s3-wroom-1_wroom-1u_datasheet_en.pdf).

## PCB and BOM validation status

The current schematic contains 452 unique references and the saved PCB contains the
same 452 references. The mapping is one-to-one: there are no missing, extra, or
duplicate references and no value, footprint, manufacturing-field, primary-UUID,
or pad-net mismatches. C116–C119 are present on the PCB, and the C117/C118 UUID and
rail assignments are correct: C117 bypasses `+3V3_VBUS`; C118 bypasses `+3V3_SS`.
R145 remains synchronized at 487 kΩ; with R159 = 100 kΩ it gives U38 the same
7.04/6.40 V nominal OVLO thresholds as U36.

All 42 assigned footprint names resolve to installed project or KiCad libraries.
The 84 unique fitted parts pass the package-family, package-designator, body/pitch,
pin-count, and pad-number audit. No LCSC code or manufacturer part number maps to
conflicting values or footprints.

The completed four-layer board uses 1 oz copper on all layers. In1 is an
uninterrupted GND plane; In2 is predominantly GND with selected routing. Main power
trunks use wide traces and copper zones, the converter placements follow the
relevant datasheet priorities, U11 SRP/SRN use paired Kelvin routing, and the ESP32
antenna extends beyond the board edge. Static placement/routing review finds no
additional electrical connectivity blocker.

The Default netclass clearance is 0.152 mm globally, not only at U8. This meets the
selected fabricator's copper capability, but it is a board-wide density choice. The
global solder-mask expansion is now 0.05 mm, the minimum mask-bridge width is
0.10 mm, and intentional opening merges are allowed only between pads within the
same footprint. `solder_mask_bridge` is enabled at warning severity and the current
board has no solder-mask-bridge violations.

## Fabrication and release disposition

1. **Solder-mask bridging is resolved.** The board now uses 0.05 mm global
   expansion and a 0.10 mm minimum bridge, with same-footprint pad-opening merges
   explicitly allowed. The bridge rule is no longer suppressed and reports zero
   violations.
2. **Epoxy-filled and capped vias were ordered.** Via use inside pads has been
   reduced. The current board contains 23 via centers within solderable pad
   outlines: three at U5, five at U8, four at U11, and eleven distributed among
   smaller pads. The revision-1.0 order specifies epoxy-filled-and-capped covering
   for all 1,859 through vias, replacing the earlier accepted ordinary plugging
   approach. Production-file confirmation is enabled.
3. **The two footprint-library exclusions are intentional.** J1 and J4 retain
   `lib_footprint_mismatch` exclusions because their local copies have deliberately
   adjusted pin-1 indicators. Pad numbers, copper geometry, drills, and electrical
   connectivity are unaffected; the warnings are intentionally ignored for this
   release.
4. **Functional silkscreen labels are resolved.** The obsolete J6 range label has
   been replaced by `+20V DC IN`, while the electrical documentation retains the
   accepted **18.5–20 V** input range. Enabled silkscreen-overlap DRC is clean. The
   normally ignored optional audit still finds 20 mask-clipping and three
   edge-clipping warnings, primarily footprint outlines and pin-1 circles; these
   can be trimmed by fabrication and do not change connectivity. No dedicated
   `TP*` footprints are present, so component/via probing remains an accepted
   testability decision.
5. **The revision-1.0 JLCPCB placement rendering is accepted.** The ordered BOM
   contains all 444 fitted references and the ordered position file contains those
   references plus FID1–FID3. Coordinates, rotations, and top-side assignments
   match the saved PCB. A visual polarity/pin-1/keying audit of all 130
   orientation-sensitive fitted references found no reversed, mirrored, or
   incorrectly rotated component. See the order record in
   [pcb-layout.md](pcb-layout.md).

## Schematic text cleanup before freeze

The netlist and component values are correct, but several free-text calculation
callouts still contain earlier rounded values. These notes do not affect the PCB,
but they should be corrected so the released schematic agrees with the calculations
below:

- U22 and U35: 22.84/20.75 V OVLO and 17.07/15.51 V PGTH;
- U23: 17.50/15.90 V UVLO, 22.14/20.11 V OVLO, and 17.07/15.51 V PGTH;
- U24: 22.84/20.75 V OVLO and 4.48/4.07 V PGTH;
- U36 and U38: 7.04/6.40 V OVLO and 4.48/4.07 V PGTH; and
- U37: 22.84/20.75 V OVLO and 9.91/9.00 V PGTH.

The POWER MUX note should not describe 22.8 V as a generally valid input: normal
operation is limited to 22 V recommended maximum, the nominal OV threshold is
22.73 V, and 24 V is the absolute maximum. The backed U1 buck note should also use
at least 21 V as its design-input ceiling because the 20.629 V nominal supercap
target can reach approximately 20.94 V at the retained worst-case corner. These
are annotation-only corrections and require no PCB relink.

## Final design basis

- USB-C requests only 20 V: U8 `VBUS_MIN` and `VBUS_MAX` are tied high to
  `+3V3_PDC`. Raw `+VBUS_USB` is 5 V before negotiation; U22 remains disabled until
  U4 validates the active-low `VBUS_FET_EN` state.
- The permitted DC adapter is **18.5–20 V**. U23's R83/R92/R103 ladder gives
  **17.50/15.90 V UVLO** and **22.14/20.11 V OVLO** nominal rising/falling
  thresholds.
- JP1 is default-closed for USB-C and must be opened before DC operation. USB-C and
  DC are specified as mutually exclusive input configurations.
- U19 compares R72/R76 = 34 kΩ/5.62 kΩ against U51's 2.5 V reference. The
  nominal IN1→IN2 crossover is **17.625 V**, with approximately **17.577–17.673 V**
  initial component corners. TPS2121 comparator offset places the expected
  IN2→IN1 return threshold at approximately **17.66–17.91 V**.
- U19 OV1 and OV2 use the final precision dividers R74/R80 and R89/R100 =
  **102 kΩ/4.99 kΩ**, all ±0.1%, ±25 ppm/°C. Nominal rising OV is **22.73 V**.
  Including TPS2121 reference limits, initial resistor tolerance, and pin leakage
  gives approximately **21.60–23.64 V**; a deliberately conservative opposing-TC
  estimate over the full component range is approximately **21.50–23.75 V**.
- The TPS2121 supervisors are not relied upon to protect the mux input pins from an
  excessive external source. U22/U23/U24 and the specified source limits must keep
  both U19 inputs below 24 V absolute maximum; normal operation remains below the
  22 V recommended maximum.
- Nominal `+VBUS_SS` capacitance is approximately **241.1 µF**: 200 µF bulk at
  C78/C79, 20 µF at C80/C81, 1 µF at C103, and 20.1 µF at the U1 input.
- A 17.625→20.629 V lower-to-higher transfer adds about **13.8 mJ** and **0.72 mC**
  to that capacitance. U19 intentionally regulates the total load-plus-charging
  current at its R97-programmed limit (about 4–5 A, 4.5 A typical); this is not an
  expected OCP event. At a 40 W constant-power load, settling is expected to be a
  few hundred microseconds rather than only the 5 µs source-selection interval.
- U11 has a fixed R43/R50 = 300 kΩ/34 kΩ, ±0.1% VFB divider for **20.629 V
  nominal**. Including BQ24640 full-temperature feedback accuracy, resistor
  tolerance/TC, and VFB leakage gives the retained worst-case estimate of
  approximately **20.36–20.94 V**.
- `VCAP_EN` is driven directly by ESP32 IO42 with R38 default-low. An ESP32
  brownout during backup releases U24 and intentionally powers the board down.
- Raw `+VBUS_DC` has C83 = 1 µF. Raw `+VCAP` has approximately 16.8 µF of local
  capacitance rather than 100 µF. Large bulk is behind controlled-slew devices.
- `VBUS_ADC` has been removed and IO4 is now `STAT_LED`. `VCAP_ADC` uses
  R195/R198 = 82 kΩ/10 kΩ, R196 = 2.2 kΩ, and C50 = 100 nF for a ÷9.2 scale.
  U9 connects it to IO2 only while `+3V3_SS` exists. The ADC sees approximately
  3.01 V at the TVS2200 27.7 V clamp, about 3.07 V at 1% divider corners.
- U3 hardware-gates R26/R27/R28, the CYPD3177 HPI interrupt/I²C pull-ups. With
  both `+3V3_PDC` and `+3V3_SS` present they pull up to `+3V3_SS`; with only the
  backed rail present they pull low; with `+3V3_SS` absent the powered-off switch
  isolates them.

## Accepted design constraints

These items are signed off and do not require another schematic change. They must
remain visible to firmware, integration, and test teams.

### TPS2121 transfer behavior

When U19 changes from a lower-voltage source to a higher-voltage source, the selected
channel uses active current limiting while it charges the output capacitance and
supplies the load. A normal transfer is not expected to hit a separate OCP trip.
Sustained or repetitive current limiting, source droop, and selection chatter remain
bench-test cases.

### LM73100 overload behavior

The seven LM73100 paths are rated for 5.5 A continuous current, but the fixed fast
trip is approximately 21.9 A and latches off; it is not a precise 5.5 A current
limiter. This behavior is accepted. Connector loads, harnesses, and external wiring
must be rated and fused appropriately, and firmware retry of a latched channel must
be bounded.

### `VBUS_USB_EN` single-fault limit

U4 logic is valid and R8 provides an independent default-low state. A stuck-high U4
output, open R21, or shorted R14 can still enable U22 before a valid contract. The
design intentionally does not claim single-fault tolerance for that low-probability
combination; attach, detach, reset, reversal, and incompatible-source testing is
required.

### Supercap protection allocation

The precision VFB divider provides normal regulation, and the independent
`VCAP_ADC` path lets firmware disable `SCC_EN` on abnormal bank voltage. The external
bank provides cell balancing and temperature protection, with a correctly sized fuse
physically close to the bank in its external wiring. Board-level tolerance of
simultaneous VFB and monitoring failures is not claimed and is accepted.

### Configured USB/DC separation

JP1 is a user configuration control, not automatic source isolation. Leave it closed
for USB-C, open it for DC, and do not connect USB-C and DC power simultaneously.

## Required firmware behavior

1. On `PMUX_ST` transition, disable the charger, boost, unbacked buck, and unbacked
   outputs; retain only explicitly required shutdown loads.
2. On input return, validate the source and USB contract, then restore loads one at
   a time. Read and reconcile retained U26/U43 state after an ESP32-only reset.
3. After a full TCA9535 power cycle, write safe output-register values before
   changing ports from inputs to outputs; the registers power up high although the
   pins power up as inputs.
4. Define a load-aware minimum `VCAP` threshold. At 40 W the load approaches the
   minimum 4 A U19 limit near a 10 V bank; shed loads and release `VCAP_EN` well
   before losses or transients remove current-limit margin.
5. Do not interpret `PMUX_ST` high alone as proof of VBUS: it means IN1 selected or
   mux output Hi-Z.
6. Read the negotiated PDO/RDO and budget charger plus load current. U8's current
   straps accept any advertised source current and do not enforce a board power
   limit.
7. Select ISET and TS only while `SCC_EN` is low. Enable U5, wait for stable
   `24V_VBUS_PG`, then enable U11. Disable U11 and allow current to decay before
   disabling U5. The asynchronous boost has a passive input-to-output path while
   disabled and is not an output disconnect.
8. Do not select pad JTAG on GPIO39–GPIO42 or enable GPIO3 strap-selected JTAG;
   those pins are assigned to `PD_INT`, PD I²C, and `VCAP_EN`, while GPIO3 carries
   `VIMON_DC`. Use the default USB Serial/JTAG interface through J2 when hardware
   debugging is required.

## Remaining bench and integration checks

- Validate U48 TLV1117LV33 temperature with final SOT-223 copper, ambient,
  enclosure, average ESP32 load, and radio peaks. At a 350 mA rail load it dissipates
  about 0.63 W from 5.1 V.
- Validate connector hot-plug with worst cable inductance. Reduced raw capacitance
  lowers inrush but does not eliminate ceramic/cable ringing.
- Use clear silkscreen and keyed/color-coded harnesses because J6 and J7–J10 share
  the PJ-202AH family. An external source accidentally connected to a 5 V output can
  overstress its TVS despite LM73100 reverse blocking.
- Provide load-local flyback/regeneration handling where required. Reverse blocking
  can trap returned energy on the connector side of an open output switch.
- Default U14 to the real thermistor. The fixed TS path is a time-limited diagnostic
  override with independent voltage and temperature monitoring.
- TS5A3159A U3/U9/U12/U14/U25 and LM4040A25I U51 are specified only to +85 °C
  ambient. Use wider-temperature parts if the product requirement exceeds that.
- IC1 ESP32-S3-WROOM-1-N8R8 is specified for −40 to +65 °C ambient by default.
  Espressif allows +85 °C with PSRAM ECC enabled and a 1/16 reduction in usable
  PSRAM; otherwise +65 °C is the controlling product-ambient limit.

## Minimum bench validation

Capture source voltage/current, `+VBUS`, `+VCAP_VALID`, `+VBUS_SS`, `+5V_SS`,
`+3V3_SS`, `PMUX_ST`, and relevant enables during:

1. USB attach with valid and incompatible sources, cable reversal, PD reset,
   detach, and every supported contract current.
2. DC hot-plug, slow ramp, current limiting, brownout through the crossover, hard
   removal, and return using 18.5–20 V sources plus deliberate invalid-source tests.
3. Mux failover/return at zero and maximum load with VCAP full, half-full, and at
   the minimum firmware-allowed voltage, including repeated interruptions.
4. ESP32 reset on VBUS, ESP32 brownout on backup, full `+3V3_SS` power cycle, and
   retained-expander recovery.
5. Charger/boost sequencing, both current selections, TS faults and override,
   firmware VCAP-overvoltage shutdown, and source return with retained state.
6. JP1 closed with USB-C and JP1 open with DC-only power; confirm `VDC_OUT` remains
   isolated from DC in the open-jumper configuration.
7. Charged-bank connection/removal, worst cable inductance, ADC power-domain
   isolation, and maximum-bank operation across temperature without U19 OV2
   nuisance trips.
8. Output startup into capacitive loads, overloads, shorts, inductive interruption,
   regeneration, and bounded recovery from LM73100 latch-off.

Primary references: [TPS2121](https://www.ti.com/lit/ds/symlink/tps2121.pdf),
[LM73100](https://www.ti.com/lit/ds/symlink/lm7310.pdf),
[BQ24640](https://www.ti.com/lit/ds/symlink/bq24640.pdf),
[TLV1117LV](https://www.ti.com/lit/ds/symlink/tlv1117lv.pdf), and
[CYPD3177](https://www.infineon.com/assets/row/public/documents/24/49/infineon-cypd3177-24lqxq-datasheet-en.pdf).

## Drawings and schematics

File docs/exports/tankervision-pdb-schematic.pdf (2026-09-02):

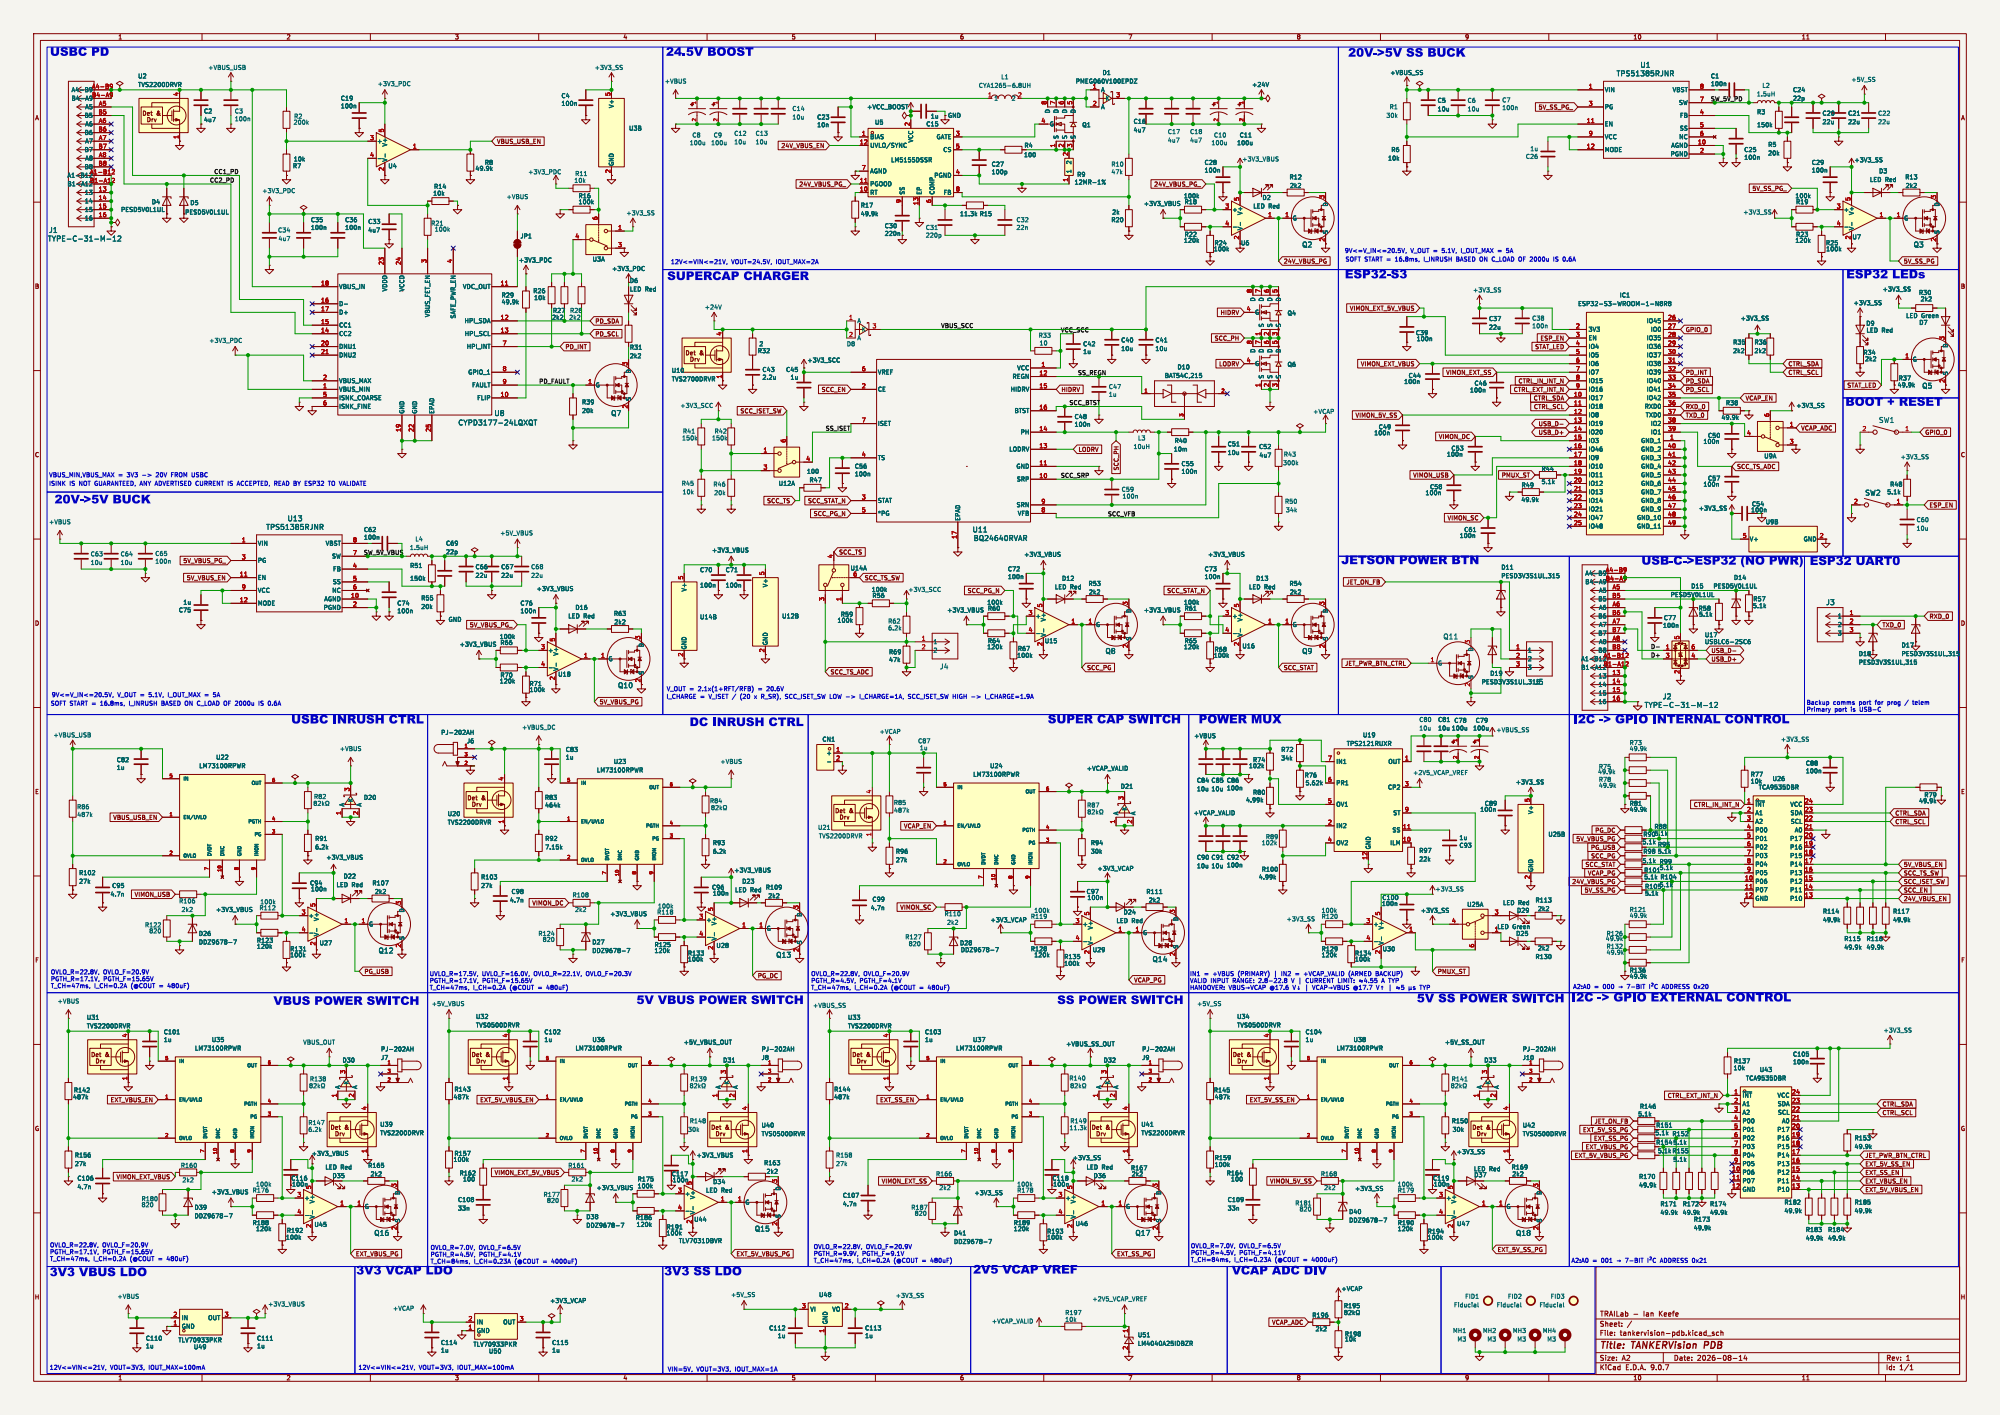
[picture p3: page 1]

6 GATE 3 CS 5 PGND 4 FB 8 +VCC_BOOST GND

6 GATE 3 CS 5 PGND 4 FB 8 U5

SOFT START = 16.8ms, I_INRUSH BASED ON C_LOAD OF 2000u IS 0.6A
ESP32-S3

ISINK IS NOT GUARANTEED, ANY ADVERTISED CURRENT IS ACCEPTED, READ BY ESP32 TO VALIDATE

SOFT START = 16.8ms, I_INRUSH BASED ON C_LOAD OF 2000u IS 0.6A VBUS POWER SWITCH

Backup comms port for prog / telem
Primary port is USB-C

A2:A0 = 000 þÿ!’7-BIT þÿI²CADDRESS 0x20
I2C -> GPIO EXTERNAL CONTROL

A2:A0 = 001 þÿ!’7-BIT þÿI²CADDRESS 0x21

VIN=5V, VOUT=3V3, IOUT_MAX=1A 3V3 VBUS LDO

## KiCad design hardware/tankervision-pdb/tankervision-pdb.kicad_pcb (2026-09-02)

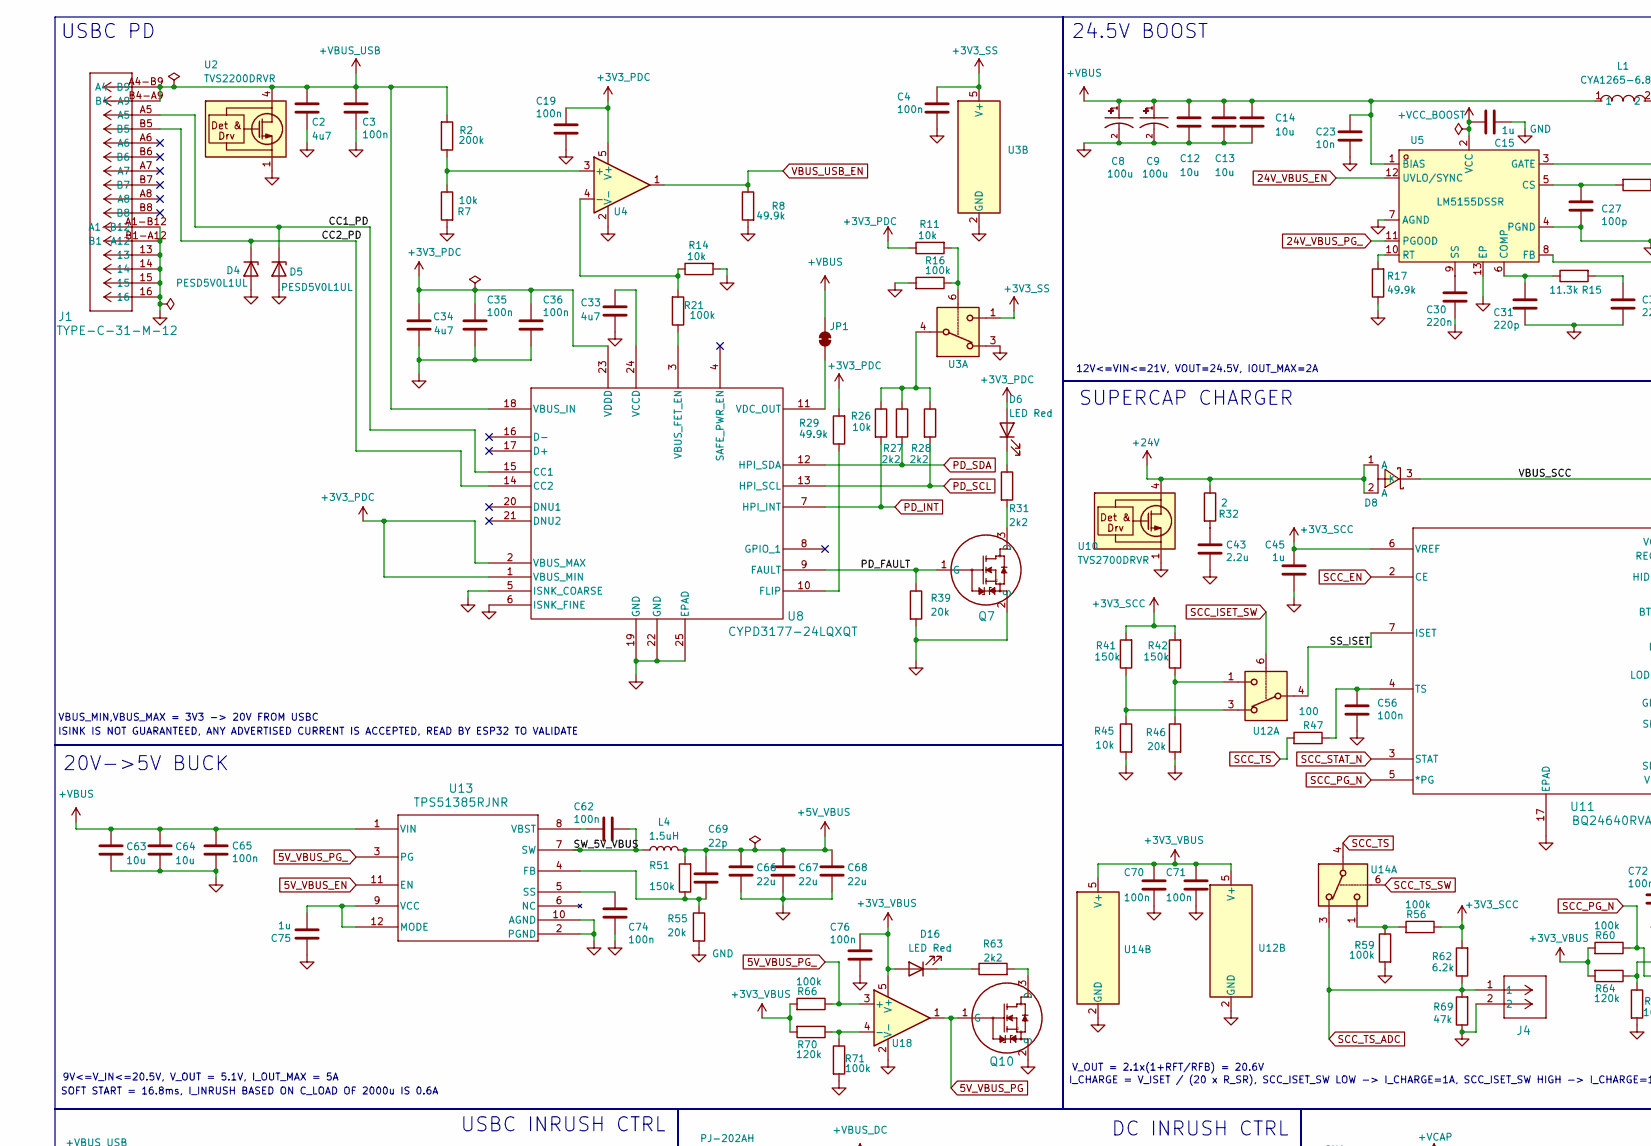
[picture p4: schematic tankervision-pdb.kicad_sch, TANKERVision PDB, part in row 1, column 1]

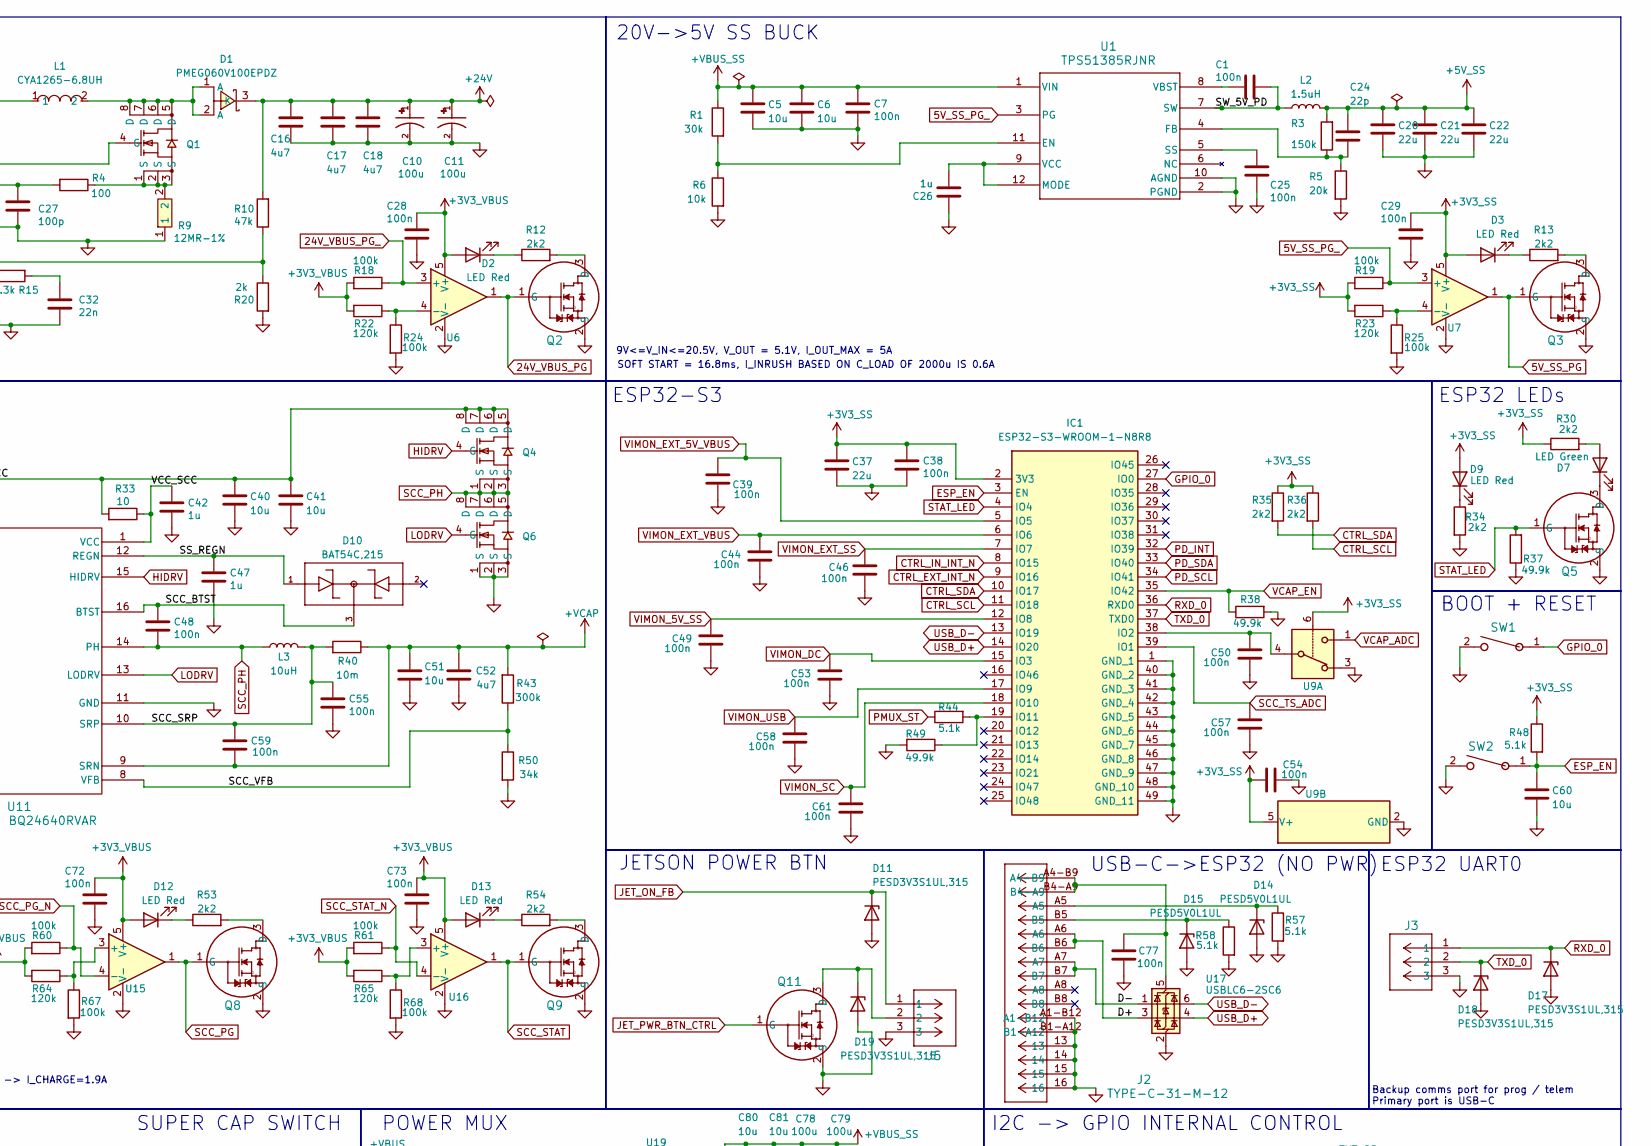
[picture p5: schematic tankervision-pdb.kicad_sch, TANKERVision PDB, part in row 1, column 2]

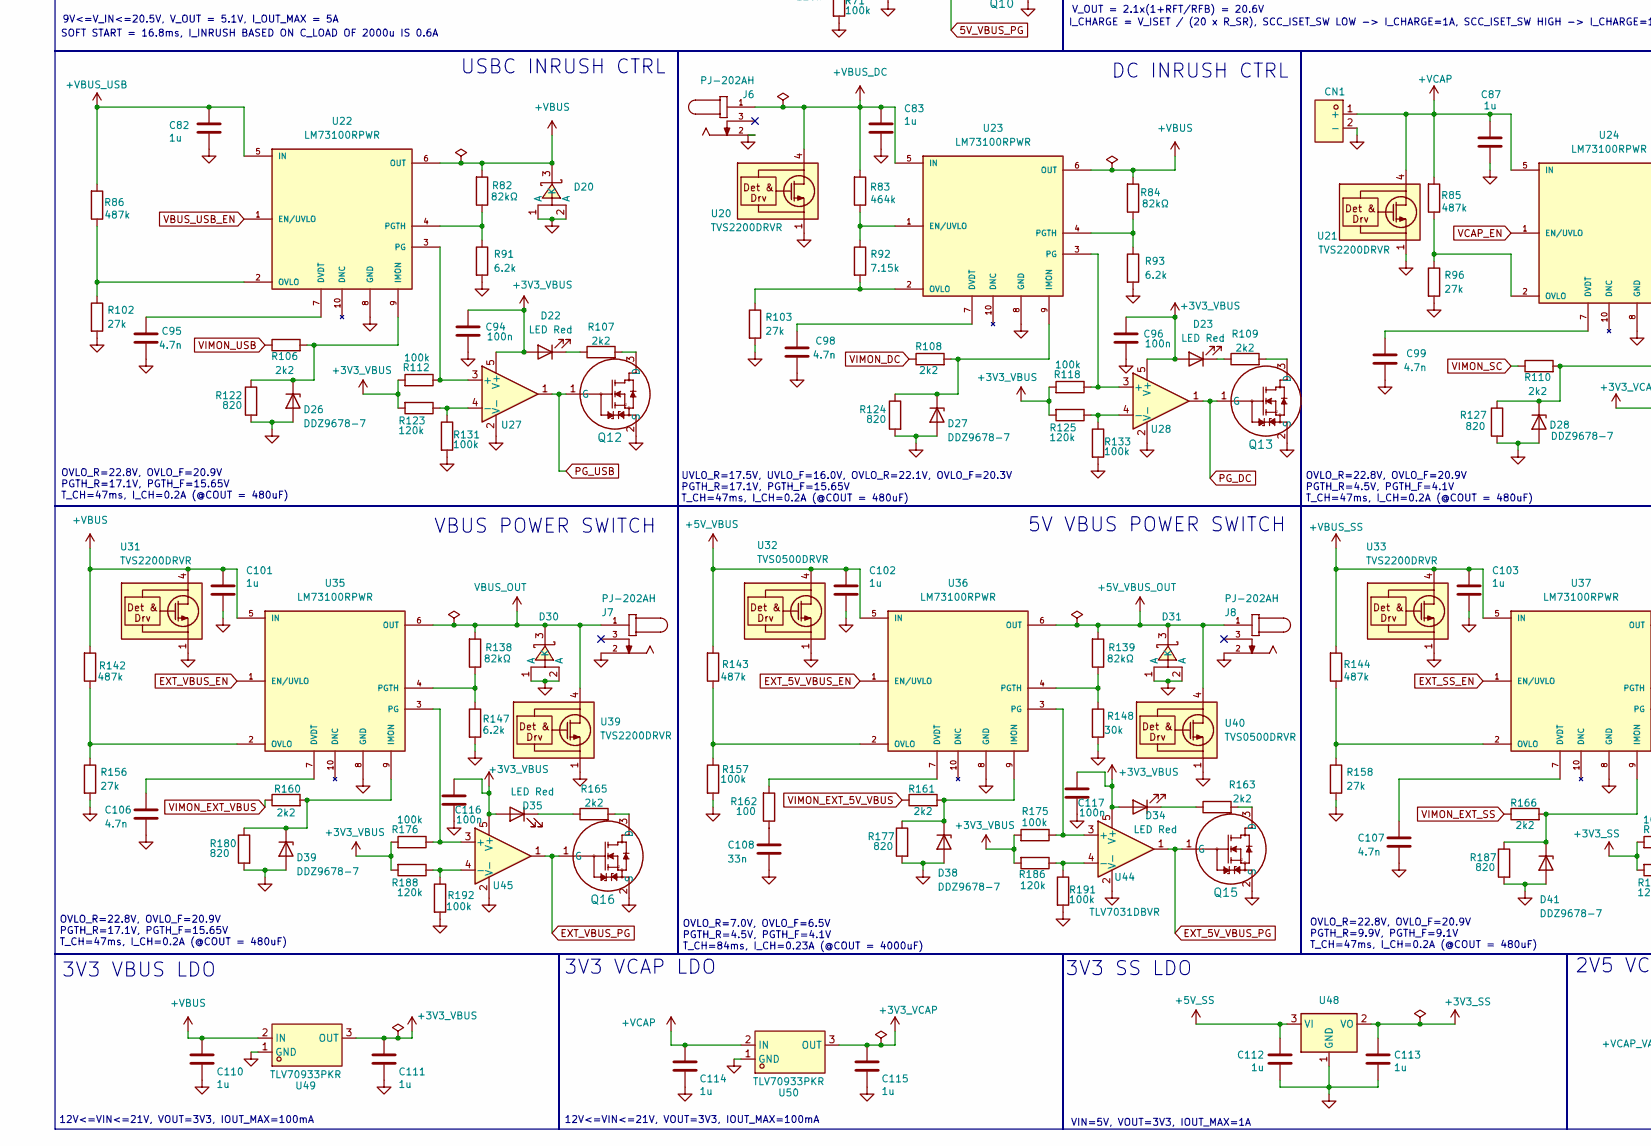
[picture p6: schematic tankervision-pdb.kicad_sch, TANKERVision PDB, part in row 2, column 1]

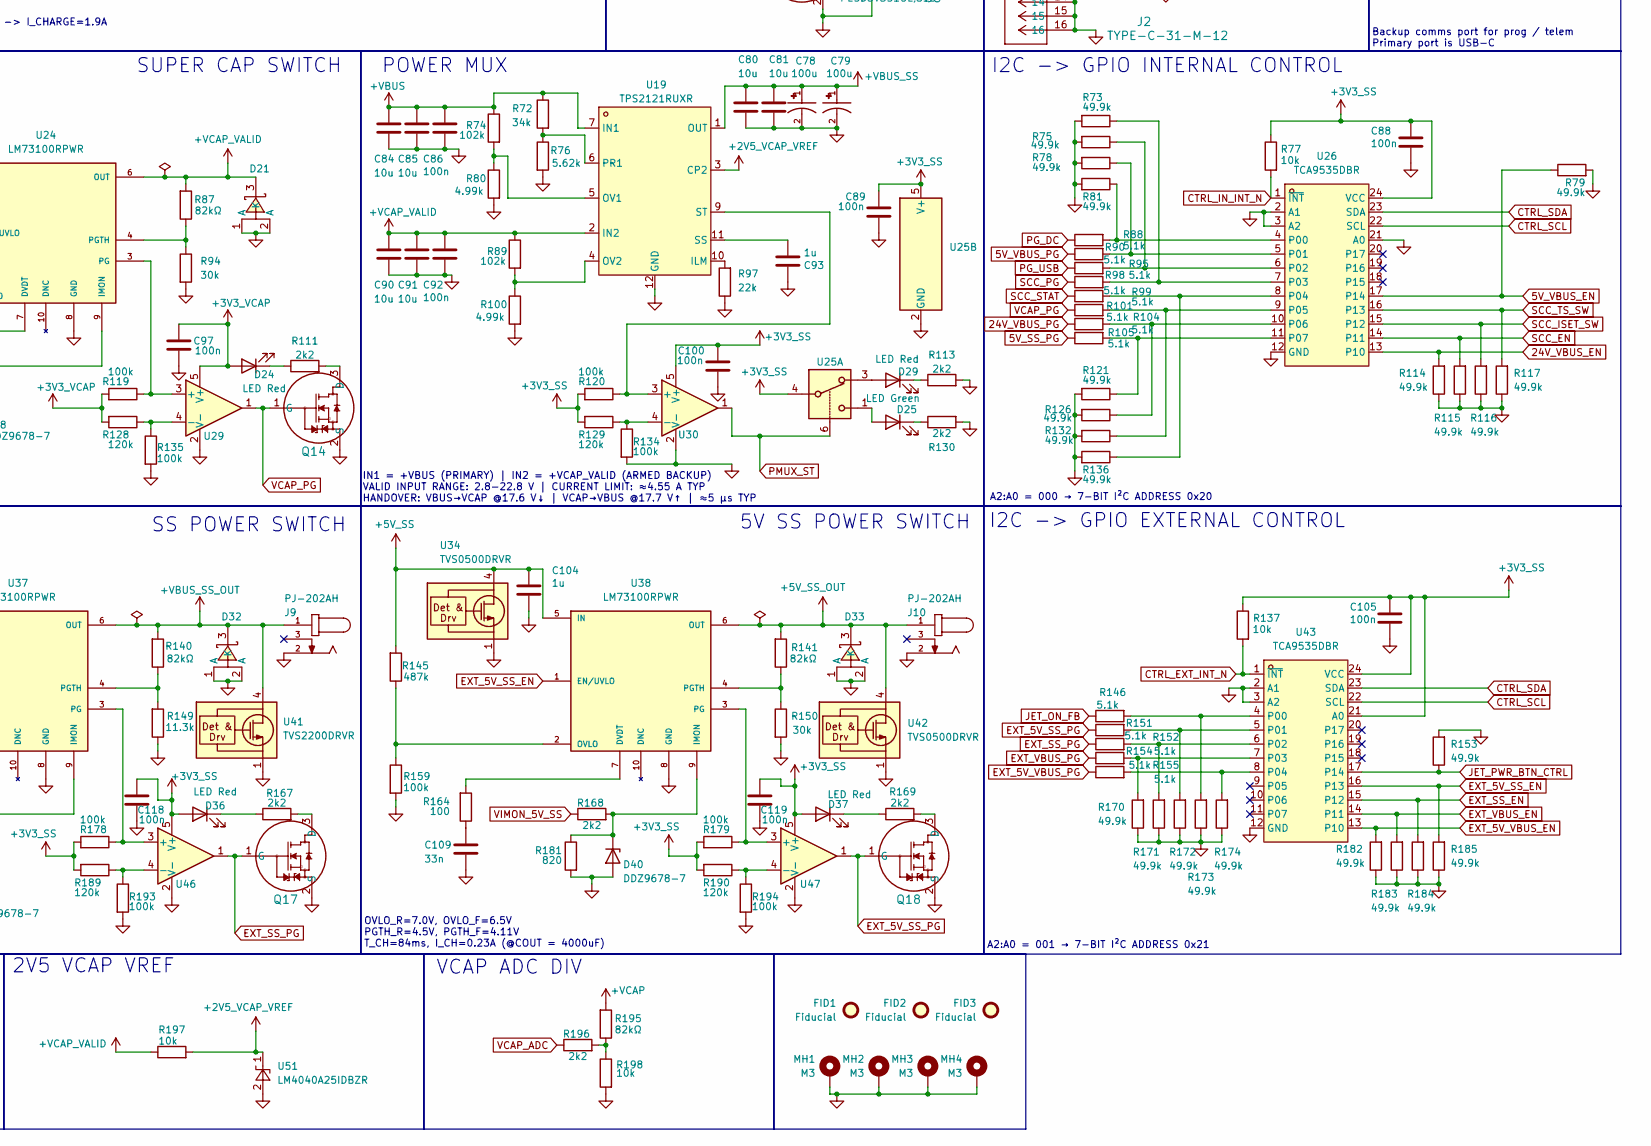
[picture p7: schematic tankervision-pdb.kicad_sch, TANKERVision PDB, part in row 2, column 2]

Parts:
C1, C3, C4, C7, C19, C25, C28, C29, C35, C36, C38, C39, C44, C46, C48, C49, C50, C53, C54, C55, C56, C57, C58, C59, C61, C62, C65, C70, C71, C72, C73, C74, C76, C77, C86, C88, C89, C92, C94, C96, C97, C100, C105, C116, C117, C118, C119: 100n; C_0603_1608Metric; Manufacturer_Part_Number CC0603KRX7R9BB104; JLCPCB Part # C14663
C2, C16, C17, C18, C33, C34, C52: 4u7; C_1206_3216Metric; Manufacturer_Part_Number 1206B475K500NT; JLCPCB Part # C29823
C5, C6, C12, C13, C14, C40, C41, C51, C60, C63, C64, C80, C81, C84, C85, C90, C91: 10u; C_1206_3216Metric; Manufacturer_Part_Number CL31A106KBHNNNE; JLCPCB Part # C13585
C8, C9, C10, C11, C78, C79: 100u; CAP_EEHZA1H101V; Manufacturer_Part_Number EEHZA1H101V; JLCPCB Part # C454363
C15, C26, C42, C45, C47, C75, C82, C83, C87, C93, C101, C102, C103, C104, C110, C111, C112, C113, C114, C115: 1u; C_0805_2012Metric; Manufacturer_Part_Number CL21B105KBFNNNE; JLCPCB Part # C28323
C20, C21, C22, C37, C66, C67, C68: 22u; C_1206_3216Metric; Manufacturer_Part_Number CL31A226KAHNNNE; JLCPCB Part # C12891
C23: 10n; C_0603_1608Metric; Manufacturer_Part_Number 0603B103K500NT; JLCPCB Part # C57112
C24, C69: 22p; C_0603_1608Metric; Manufacturer_Part_Number CL10C220JB8NNNC; JLCPCB Part # C1653
C27: 100p; C_0603_1608Metric; Manufacturer_Part_Number 0603CG101F500NT; JLCPCB Part # C55722
C30: 220n; C_0603_1608Metric; Manufacturer_Part_Number CL10B224KA8NNNC; JLCPCB Part # C21120
C31: 220p; C_0603_1608Metric; Manufacturer_Part_Number GCM1885C2A221JA16D; JLCPCB Part # C388907
C32: 22n; C_0603_1608Metric; Manufacturer_Part_Number CL10B223KB8NNNC; JLCPCB Part # C21122
C43: 2.2u; C_1206_3216Metric; Manufacturer_Part_Number CL31B225KBHNNNE; JLCPCB Part # C50254
C95, C98, C99, C106, C107: 4.7n; C_0805_2012Metric_Pad1.18x1.45mm_HandSolder; Manufacturer_Part_Number 0805B472K500NT; JLCPCB Part # C1744
C108, C109: 33n; C_0805_2012Metric_Pad1.18x1.45mm_HandSolder; Manufacturer_Part_Number 0805B333K500NT; JLCPCB Part # C1739
CN1: XT30APW-M; CONN-TH_XT30APW-M; Manufacturer_Part_Number XT30APW-M; JLCPCB Part # C5818955
D1, D8, D20, D21, D30, D31, D32, D33: PMEG060V100EPDZ; SOT1289_L5.8-W4.4-LS6.5-RD; Manufacturer_Part_Number PMEG060V100EPDZ; JLCPCB Part # C552792
D2, D3, D6, D9, D12, D13, D16, D22, D23, D24, D29, D34, D35, D36, D37: LED Red; LED_0805_2012Metric; Manufacturer_Part_Number XL-2012SURC-FJ; JLCPCB Part # C7371909
D4, D5, D14, D15: PESD5V0L1UL; D_SOD-882; Manufacturer_Part_Number PESD5V0L1UL; JLCPCB Part # C3001948
D7, D25: LED Green; LED_0805_2012Metric; Manufacturer_Part_Number XL-2012UGC; JLCPCB Part # C965815
D10: BAT54C,215; SOT-23; Manufacturer_Part_Number BAT54C,215; JLCPCB Part # C37704
D11, D17, D18, D19: PESD3V3S1UL,315; D_SOD-882; Manufacturer_Part_Number PESD3V3S1UL,315; JLCPCB Part # C70371
D26, D27, D28, D38, D39, D40, D41: DDZ9678-7; D_SOD-123; Manufacturer_Part_Number DDZ9678-7; JLCPCB Part # C150464
FID1, FID2, FID3: Fiducial; Fiducial_1mm_Mask2mm
IC1: ESP32-S3-WROOM-1-N8R8; ESP32S3WROOM1N8R8; Manufacturer_Part_Number ESP32-S3-WROOM-1-N8R8; JLCPCB Part # C2913201
J1, J2: TYPE-C-31-M-12; CONN12_C-31-M-12_HRO; Manufacturer_Part_Number TYPE-C-31-M-12; JLCPCB Part # C165948
J3, J5: S3B-PH-K-S LFSN; CONN_S3B-PH-K-S_JST; Manufacturer_Part_Number S3B-PH-K-S(LF)(SN); JLCPCB Part # C157929
J4: S2B-PH-K-SLFSN; CONN_S2B-PH-K-S_JST; Manufacturer_Part_Number S2B-PH-K-S(LF)(SN); JLCPCB Part # C173752
J6, J7, J8, J9, J10: PJ-202AH; CUI_PJ-202AH; Manufacturer_Part_Number PJ-202AH; JLCPCB Part # C7435395
JP1: SolderJumper_2_Bridged; SolderJumper-2_P1.3mm_Bridged_RoundedPad1.0x1.5mm
L1: CYA1265-6.8UH; IND-SMD_L12.8-W12.8-LS13.8_CYA1265; Manufacturer_Part_Number CYA1265-6.8UH; JLCPCB Part # C19268667
L2, L4: 1.5uH; IND_MWSA0603S_SNL-M; Manufacturer_Part_Number MWSA0603S-1R5MT; JLCPCB Part # C408444
L3: 10uH; SMDRI127100MT; Manufacturer_Part_Number SMDRI127-100MT; JLCPCB Part # C9904
MH1, MH2, MH3, MH4: M3; MountingHole_3.2mm_M3_Pad_Via
Q1, Q4, Q6: IPC50N04S5L5R5ATMA1; PG-TDSON-8-FL_L5.0-W6.0-P1.27-LS6.2-BL; Manufacturer_Part_Number IPC50N04S5L5R5ATMA1; JLCPCB Part # C3288870
Q2, Q3, Q5, Q7, Q8, Q9, Q10, Q11, Q12, Q13, Q14, Q15, Q16, Q17, Q18: 2N7002NXAKR; TO-236AB_SOT23_NEX-M; Manufacturer_Part_Number 2N7002NXAKR; JLCPCB Part # C551416
R1, R94, R148, R150: 30k; R_0603_1608Metric; Manufacturer_Part_Number 0603WAF3002T5E; JLCPCB Part # C22984
R2: 200k; R_0603_1608Metric; Manufacturer_Part_Number 0603WAF2003T5E; JLCPCB Part # C25811
R3, R41, R42, R51: 150k; R_0603_1608Metric; Manufacturer_Part_Number 0603WAF1503T5E; JLCPCB Part # C22807
R4, R47, R162, R164: 100; R_0603_1608Metric; Manufacturer_Part_Number 0603WAF1000T5E; JLCPCB Part # C22775
R5, R39, R55: 20k; R_0603_1608Metric; Manufacturer_Part_Number 0603WAF2002T5E; JLCPCB Part # C4184
R6, R7, R11, R14, R26, R77, R137, R197, R198: 10k; R_0603_1608Metric; Manufacturer_Part_Number 0603WAF1002T5E; JLCPCB Part # C25804
R8, R17, R29, R37, R38, R49, R73, R75, R78, R79, R81, R114, R115, R116, R117, R121, R126, R132, R136, R153, R170, R171, R172, R173, R174, R182, R183, R184, R185: 49.9k; R_0603_1608Metric; Manufacturer_Part_Number 0603WAF4992T5E; JLCPCB Part # C23184
R9: 12MR-1%; RES-SMD_L6.4-W3.2_LR2512D-3W-1MR; Manufacturer_Part_Number HoLLR2512-2W-12mR-1%; JLCPCB Part # C2994622
R10, R69: 47k; R_0805_2012Metric_Pad1.20x1.40mm_HandSolder; Manufacturer_Part_Number RT0805BRE0747KL; JLCPCB Part # C866080
R12, R13, R27, R28, R30, R31, R34, R35, R36, R53, R54, R63, R106, R107, R108, R109, R110, R111, R113, R130, R160, R161, R163, R165, R166, R167, R168, R169, R196: 2k2; R_0603_1608Metric; Manufacturer_Part_Number 0603WAF2201T5E; JLCPCB Part # C4190
R15, R149: 11.3k; R_0603_1608Metric; Manufacturer_Part_Number 0603WAF1132T5E; JLCPCB Part # C22860
R16, R18, R19, R21, R24, R25, R56, R59, R60, R61, R66, R67, R68, R71, R112, R118, R119, R120, R131, R133, R134, R135, R157, R159, R175, R176, R178, R179, R191, R192, R193, R194: 100k; R_0603_1608Metric; Manufacturer_Part_Number 0603WAF1003T5E; JLCPCB Part # C25803
R20: 2k; R_0805_2012Metric_Pad1.20x1.40mm_HandSolder; Manufacturer_Part_Number 0805W8F2001T5E; JLCPCB Part # C17604
R22, R23, R64, R65, R70, R123, R125, R128, R129, R186, R188, R189, R190: 120k; R_0603_1608Metric; Manufacturer_Part_Number 0603WAF1203T5E; JLCPCB Part # C25808
R32: 2; R_0603_1608Metric; Manufacturer_Part_Number 0603WAF200KT5E; JLCPCB Part # C22977
R33: 10; R_0603_1608Metric; Manufacturer_Part_Number 0603WAF100JT5E; JLCPCB Part # C22859
R40: 10m; R_2512_6332Metric; Manufacturer_Part_Number PCSR2512DR010M6; JLCPCB Part # C7470248
R43: 300k; R_0805_2012Metric_Pad1.20x1.40mm_HandSolder; Manufacturer_Part_Number RT0805BRD07300KL; JLCPCB Part # C865386
R44, R48, R57, R58, R88, R90, R95, R98, R99, R101, R104, R105, R146, R151, R152, R154, R155: 5.1k; R_0603_1608Metric; Manufacturer_Part_Number 0603WAF5101T5E; JLCPCB Part # C23186
R45: 10k; R_0805_2012Metric_Pad1.20x1.40mm_HandSolder; Manufacturer_Part_Number 0805W8F1002T5E; JLCPCB Part # C17414
R46: 20k; R_0805_2012Metric_Pad1.20x1.40mm_HandSolder; Manufacturer_Part_Number 0805W8F2002T5E; JLCPCB Part # C4328
R50, R72: 34k; R_0805_2012Metric_Pad1.20x1.40mm_HandSolder; Manufacturer_Part_Number RT0805BRD0734KL; JLCPCB Part # C865418
R62: 6.2k; R_0805_2012Metric_Pad1.20x1.40mm_HandSolder; Manufacturer_Part_Number RT0805BRD076K2L; JLCPCB Part # C326695
R74, R89: 102k; R_0805_2012Metric_Pad1.20x1.40mm_HandSolder; Manufacturer_Part_Number RT0805BRD07102KL; JLCPCB Part # C865126
R76: 5.62k; R_0805_2012Metric_Pad1.20x1.40mm_HandSolder; Manufacturer_Part_Number RT0805BRD075K62L; JLCPCB Part # C706248
R80, R100: 4.99k; R_0805_2012Metric_Pad1.20x1.40mm_HandSolder; Manufacturer_Part_Number RT0805BRD074K99L; JLCPCB Part # C706246
R82, R84, R87, R138, R139, R140, R141, R195: 82kΩ; R_0805_2012Metric_Pad1.20x1.40mm_HandSolder; Manufacturer_Part_Number 0805W8F8202T5E; JLCPCB Part # C17840
R83: 464k; R_0805_2012Metric_Pad1.20x1.40mm_HandSolder; Manufacturer_Part_Number 0805W8F4643T5E; JLCPCB Part # C17706
R85, R86, R142, R143, R144, R145: 487k; R_0805_2012Metric_Pad1.20x1.40mm_HandSolder; Manufacturer_Part_Number 0805W8F4873T5E; JLCPCB Part # C17717
R91, R93, R147: 6.2k; R_0603_1608Metric; Manufacturer_Part_Number 0603WAF6201T5E; JLCPCB Part # C4260
R92: 7.15k; R_0805_2012Metric_Pad1.20x1.40mm_HandSolder; Manufacturer_Part_Number 0805W8F7151T5E; JLCPCB Part # C17806
R96, R102, R103, R156, R158: 27k; R_0805_2012Metric_Pad1.20x1.40mm_HandSolder; Manufacturer_Part_Number 0805W8F2702T5E; JLCPCB Part # C17593
R97: 22k; R_0603_1608Metric; Manufacturer_Part_Number 0603WAF2202T5E; JLCPCB Part # C31850
R122, R124, R127, R177, R180, R181, R187: 820; R_0603_1608Metric; Manufacturer_Part_Number 0603WAF8200T5E; JLCPCB Part # C23253
SW1, SW2: TS-1088-AR02016; SW_TS-1088_XNP-M; Manufacturer_Part_Number TS-1088-AR02016; JLCPCB Part # C720477
U1, U13: TPS51385RJNR; VQFN-HR12_RJN_TEX; Manufacturer_Part_Number TPS51385RJNR; JLCPCB Part # C22418767
U2, U20, U21, U31, U33, U39, U41: TVS2200DRVR; WSON-6-1EP_2x2mm_P0.65mm_EP1x1.6mm; Manufacturer_Part_Number TVS2200DRVR; JLCPCB Part # C523793
U3, U9, U12, U14, U25: TS5A3159ADBVR; SOT-23-6; Manufacturer_Part_Number TS5A3159ADBVR; JLCPCB Part # C128405
U4, U6, U7, U15, U16, U18, U27, U28, U29, U30, U44, U45, U46, U47: TLV7031DBVR; SOT-23-5; Manufacturer_Part_Number TLV7031DBVR; JLCPCB Part # C2869832
U5: LM5155DSSR; WSON-12_L3.0-W2.0-P0.50-BL-EP; Manufacturer_Part_Number LM5155DSSR; JLCPCB Part # C545416
U8: CYPD3177-24LQXQT; QFN24_CYPD3177-24LQXQT_INF; Manufacturer_Part_Number CYPD3177-24LQXQT; JLCPCB Part # C2952489
U10: TVS2700DRVR; WSON-6-1EP_2x2mm_P0.65mm_EP1x1.6mm; Manufacturer_Part_Number TVS2700DRVR; JLCPCB Part # C523797
U11: BQ24640RVAR; RVA16_2P14X2P14; Manufacturer_Part_Number BQ24640RVAR; JLCPCB Part # C545157
U17: USBLC6-2SC6; SOT-23-6; Manufacturer_Part_Number USBLC6-2SC6; JLCPCB Part # C7519
U19: TPS2121RUXR; VQFN-HR-12_L2.5-W2.0-P0.50-BL; Manufacturer_Part_Number TPS2121RUXR; JLCPCB Part # C485916
U22, U23, U24, U35, U36, U37, U38: LM73100RPWR; IC_LM73100RPWR; Manufacturer_Part_Number LM73100RPWR; JLCPCB Part # C3210761
U26, U43: TCA9535DBR; SSOP-24_L8.1-W5.3-P0.65-LS7.8-BL; Manufacturer_Part_Number TCA9535DBR; JLCPCB Part # C2652322
U32, U34, U40, U42: TVS0500DRVR; WSON-6-1EP_2x2mm_P0.65mm_EP1x1.6mm; Manufacturer_Part_Number TVS0500DRVR; JLCPCB Part # C609571
U48: TLV1117LV33DCYR; SOT-223-3_TabPin2; Manufacturer_Part_Number TLV1117LV33DCYR; JLCPCB Part # C15578
U49, U50: TLV70933PKR; SOT-89-3_L4.3-W2.3-P1.50-LS4.3-BR; Manufacturer_Part_Number TLV70933PKR; JLCPCB Part # C22445454
U51: LM4040A25IDBZR; SOT-23; Manufacturer_Part_Number LM4040A25IDBZR; JLCPCB Part # C9421

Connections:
5V_SS_PG: Q3.1 (G), R105.1, U7.1
5V_SS_PG_: R19.1, U1.3 (PG), U7.3 (+)
5V_VBUS_EN: R79.1, U13.11 (EN), U26.17 (P14)
5V_VBUS_PG: Q10.1 (G), R90.1, U18.1
5V_VBUS_PG_: R66.1, U13.3 (PG), U18.3 (+)
24V_VBUS_EN: R114.2, U5.12 (UVLO/SYNC), U26.13 (P10)
24V_VBUS_PG: Q2.1 (G), R104.1, U6.1
24V_VBUS_PG_: R18.1, U5.11 (PGOOD), U6.3 (+)
+2V5_VCAP_VREF: R197.2, U19.3 (CP2), U51.1 (K)
+3V3_PDC: C19.2, C34.1, C35.1, C36.1, D6.2 (A), R11.1, R29.2, U4.5 (V+), U8.1 (VBUS_MIN), U8.2 (VBUS_MAX), U8.23 (VDDD)
+3V3_SCC: C45.1, R41.2, R42.2, R56.1, R62.2, U11.6 (VREF)
+3V3_SS: C4.1, C29.2, C37.2, C38.1, C54.1, C88.1, C89.1, C100.1, C105.1, C113.1, C118.1, C119.1, D3.2 (A), D9.2 (A), D36.2 (A), D37.2 (A), IC1.2 (3V3), R19.2, R23.2, R30.1, R35.1, R36.1, R48.1, R77.1, R120.2, R129.2, R137.1, R178.2, R179.2, R189.2, R190.2, U3.1, U3.5 (V+), U7.5 (V+), U9.5 (V+), U9.6, U25.4, U25.5 (V+), U26.24 (VCC), U30.5 (V+), U43.21 (A0), U43.24 (VCC), U46.5 (V+), U47.5 (V+), U48.2 (VO)
+3V3_VBUS: C28.2, C70.2, C71.2, C72.2, C73.2, C76.2, C94.1, C96.1, C111.1, C116.1, C117.1, D2.2 (A), D12.2 (A), D13.2 (A), D16.2 (A), D22.2 (A), D23.2 (A), D34.2 (A), D35.2 (A), R18.2, R22.2, R60.2, R61.2, R64.2, R65.2, R66.2, R70.2, R112.2, R118.2, R123.2, R125.2, R175.2, R176.2, R186.2, R188.2, U6.5 (V+), U12.5 (V+), U14.5 (V+), U15.5 (V+), U16.5 (V+), U18.5 (V+), U27.5 (V+), U28.5 (V+), U44.5 (V+), U45.5 (V+), U49.3 (OUT)
+3V3_VCAP: C97.1, C115.1, D24.2 (A), R119.2, R128.2, U29.5 (V+), U50.3 (OUT)
+5V_SS: C20.2, C21.2, C22.2, C24.2, C104.1, C112.1, L2.2, R3.2, R145.2, U34.4 (IN), U34.5 (IN), U34.6 (IN), U38.5 (IN), U48.3 (VI)
+5V_SS_OUT: D33.3 (K), J10.1, R141.2, U38.6 (OUT), U42.4 (IN), U42.5 (IN), U42.6 (IN)
+5V_VBUS: C66.2, C67.2, C68.2, C69.2, C102.1, L4.2, R51.2, R143.2, U32.4 (IN), U32.5 (IN), U32.6 (IN), U36.5 (IN)
+5V_VBUS_OUT: D31.3 (K), J8.1, R139.2, U36.6 (OUT), U40.4 (IN), U40.5 (IN), U40.6 (IN)
+24V: C10.1, C11.1, C16.1, C17.1, C18.1, D1.3 (K), D8.1 (A), D8.2 (A), R10.2, R32.1, U10.4 (IN), U10.5 (IN), U10.6 (IN)
+VBUS: C8.1, C9.1, C12.2, C13.2, C14.2, C23.1, C63.2, C64.2, C65.1, C84.2, C85.2, C86.1, C101.1, C110.1, D20.3 (K), JP1.2 (B), L1.1, R72.1, R74.1, R82.2, R84.2, R142.2, U5.1 (BIAS), U13.1 (VIN), U19.7 (IN1), U22.6 (OUT), U23.6 (OUT), U31.4 (IN), U31.5 (IN), U31.6 (IN), U35.5 (IN), U49.2 (IN)
+VBUS_DC: C83.1, J6.1, R83.2, U20.4 (IN), U20.5 (IN), U20.6 (IN), U23.5 (IN)
+VBUS_SS: C5.2, C6.2, C7.1, C78.1, C79.1, C80.2, C81.2, C103.1, R1.1, R144.2, U1.1 (VIN), U19.1 (OUT), U19.8 (OUT), U33.4 (IN), U33.5 (IN), U33.6 (IN), U37.5 (IN)
+VBUS_SS_OUT: D32.3 (K), J9.1, R140.2, U37.6 (OUT), U41.4 (IN), U41.5 (IN), U41.6 (IN)
+VBUS_USB: C2.1, C3.1, C82.1, J1.A4-B9, J1.B4-A9, R2.2, R86.2, U2.4 (IN), U2.5 (IN), U2.6 (IN), U8.18 (VBUS_IN), U22.5 (IN)
+VCAP: C51.2, C52.1, C59.2, C87.1, C114.1, CN1.1 (+), R40.1, R43.2, R85.2, R195.2, U11.9 (SRN), U21.4 (IN), U21.5 (IN), U21.6 (IN), U24.5 (IN), U50.2 (IN)
+VCAP_VALID: C90.2, C91.2, C92.1, D21.3 (K), R87.2, R89.1, R197.1, U19.2 (IN2), U24.6 (OUT)
+VCC_BOOST: C15.2, U5.2 (VCC)
/CC1_PD: D5.1 (K), J1.A5, U8.15 (CC1)
/CC2_PD: D4.1 (K), J1.B5, U8.14 (CC2)
/D+: J2.A6, J2.B6, U17.3 (I/O2)
/D-: J2.A7, J2.B7, U17.1 (I/O1)
/PD_FAULT: Q7.1 (G), R39.1, U8.9 (FAULT)
/SCC_BTST: C48.1, D10.3, U11.16 (BTST)
/SCC_SRP: C55.1, C59.1, L3.2, R40.2, U11.10 (SRP)
/SCC_VFB: R43.1, R50.1, U11.8 (VFB)
/SS_ISET: U11.7 (ISET), U12.4
/SS_REGN: C47.1, D10.1, U11.12 (REGN)
/SW_5V_PD: C1.2, L2.1, U1.7 (SW)
/SW_5V_VBUS: C62.2, L4.1, U13.7 (SW)
/VBUS_SCC: C40.2, C41.2, D8.3 (K), Q4.5 (D), Q4.6 (D), Q4.7 (D), Q4.8 (D), R33.2
/VCC_SCC: C42.1, R33.1, U11.1 (VCC)
CTRL_EXT_INT_N: IC1.9 (IO16), R137.2, U43.1 (~INT)
CTRL_IN_INT_N: IC1.8 (IO15), R77.2, U26.1 (~INT)
CTRL_SCL: IC1.11 (IO18), R36.2, U26.22 (SCL), U43.22 (SCL)
CTRL_SDA: IC1.10 (IO17), R35.2, U26.23 (SDA), U43.23 (SDA)
ESP_EN: C60.2, IC1.3 (EN), R48.2, SW2.1
EXT_5V_SS_EN: R185.2, U38.1 (EN/UVLO), U43.16 (P13)
EXT_5V_SS_PG: Q18.1 (G), R151.1, U47.1
EXT_5V_VBUS_EN: R182.2, U36.1 (EN/UVLO), U43.13 (P10)
EXT_5V_VBUS_PG: Q15.1 (G), R155.1, U44.1
EXT_SS_EN: R184.2, U37.1 (EN/UVLO), U43.15 (P12)
EXT_SS_PG: Q17.1 (G), R152.1, U46.1
EXT_VBUS_EN: R183.2, U35.1 (EN/UVLO), U43.14 (P11)
EXT_VBUS_PG: Q16.1 (G), R154.1, U45.1
GND: C2.2, C3.2, C4.2, C5.1, C6.1, C7.2, C8.2, C9.2, C10.2, C11.2, C12.1, C13.1, C14.1, C15.1, C16.2, C17.2, C18.2, C19.1, C20.1, C21.1, C22.1, C23.2, C25.2, C26.1, C27.2, C28.1, C29.1, C30.2, C31.2, C32.2, C33.2, C34.2, C35.2, C36.2, C37.1, C38.2, C39.2, C40.1, C41.1, C42.2, C43.2, C44.2, C45.2, C46.2, C47.2, C49.2, C50.2, C51.1, C52.2, C53.2, C54.2, C55.2, C56.2, C57.2, C58.2, C60.1, C61.2, C63.1, C64.1, C65.2, C66.1, C67.1, C68.1, C70.1, C71.1, C72.1, C73.1, C74.2, C75.1, C76.1, C77.2, C78.2, C79.2, C80.1, C81.1, C82.2, C83.2, C84.1, C85.1, C86.2, C87.2, C88.2, C89.2, C90.1, C91.1, C92.2, C93.1, C94.2, C95.1, C96.2, C97.2, C98.1, C99.1, C100.2, C101.2, C102.2, C103.2, C104.2, C105.2, C106.1, C107.1, C108.1, C109.1, C110.2, C111.2, C112.2, C113.2, C114.2, C115.2, C116.2, C117.2, C118.2, C119.2, CN1.2 (-), D4.2 (A), D5.2 (A), D11.2 (A), D14.2 (A), D15.2 (A), D17.2 (A), D18.2 (A), D19.2 (A), D20.1 (A), D20.2 (A), D21.1 (A), D21.2 (A), D26.2 (A), D27.2 (A), D28.2 (A), D30.1 (A), D30.2 (A), D31.1 (A), D31.2 (A), D32.1 (A), D32.2 (A), D33.1 (A), D33.2 (A), D38.2 (A), D39.2 (A), D40.2 (A), D41.2 (A), IC1.1 (GND_1), IC1.40 (GND_2), IC1.41 (GND_3), IC1.42 (GND_4), IC1.43 (GND_5), IC1.44 (GND_6), IC1.45 (GND_7), IC1.46 (GND_8), IC1.47 (GND_9), IC1.48 (GND_10), IC1.49 (GND_11), J1.13, J1.14, J1.15, J1.16, J1.A1-B12, J1.B1-A12, J2.13, J2.14, J2.15, J2.16, J2.A1-B12, J2.B1-A12, J3.3, J4.2, J5.3, J6.2, J7.2, J8.2, J9.2, J10.2, MH1.1, MH2.1, MH3.1, MH4.1, Q2.2 (S), Q3.2 (S), Q5.2 (S), Q6.1 (S), Q6.2 (S), Q6.3 (S), Q7.2 (S), Q8.2 (S), Q9.2 (S), Q10.2 (S), Q11.2 (S), Q12.2 (S), Q13.2 (S), Q14.2 (S), Q15.2 (S), Q16.2 (S), Q17.2 (S), Q18.2 (S), R5.2, R6.2, R7.2, R8.2, R9.1, R14.2, R16.2, R17.1, R20.2, R24.2, R25.2, R34.2, R37.1, R38.2, R39.2, R45.2, R46.2, R49.2, R50.2, R55.2, R57.2, R58.2, R59.2, R67.2, R68.2, R69.1, R71.2, R73.2, R75.2, R76.2, R78.2, R79.2, R80.2, R81.2, R91.2, R93.2, R94.2, R96.2, R97.1, R100.2, R102.2, R103.2, R113.2, R114.1, R115.1, R116.1, R117.1, R121.2, R122.2, R124.2, R126.2, R127.2, R130.2, R131.2, R132.2, R133.2, R134.2, R135.2, R136.2, R147.2, R148.2, R149.1, R150.2, R153.2, R156.2, R157.2, R158.2, R159.2, R170.1, R171.1, R172.1, R173.1, R174.1, R177.2, R180.2, R181.2, R182.1, R183.1, R184.1, R185.1, R187.2, R191.2, R192.2, R193.2, R194.2, R198.2, SW1.2, SW2.2, U1.2 (PGND), U1.10 (AGND), U2.1 (GND), U2.2 (GND), U2.3 (GND), U2.7 (GND), U3.2 (GND), U3.3, U4.2 (V-), U5.4 (PGND), U5.7 (AGND), U5.13 (EP), U6.2 (V-), U7.2 (V-), U8.5 (ISNK_COARSE), U8.6 (ISNK_FINE), U8.19 (GND), U8.22 (GND), U8.25 (EPAD), U9.2 (GND), U9.3, U10.1 (GND), U10.2 (GND), U10.3 (GND), U10.7 (GND), U11.11 (GND), U11.17 (EPAD), U12.2 (GND), U13.2 (PGND), U13.10 (AGND), U14.2 (GND), U15.2 (V-), U16.2 (V-), U17.2 (GND), U18.2 (V-), U19.12 (GND), U20.1 (GND), U20.2 (GND), U20.3 (GND), U20.7 (GND), U21.1 (GND), U21.2 (GND), U21.3 (GND)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
GPIO_0: IC1.27 (IO0), SW1.1
HIDRV: Q4.4 (G), U11.15 (HIDRV)
JET_ON_FB: D11.1 (K), J5.1, R146.1
JET_PWR_BTN_CTRL: Q11.1 (G), R153.1, U43.17 (P14)
LODRV: Q6.4 (G), U11.13 (LODRV)
unnamed: C32.1, R15.2
unnamed: C43.1, R32.2
unnamed: C108.2, R162.1
unnamed: C109.2, R164.1
unnamed: D1.1 (A), D1.2 (A), L1.2, Q1.5 (D), Q1.6 (D), Q1.7 (D), Q1.8 (D)
unnamed: D2.1 (K), R12.1
unnamed: D3.1 (K), R13.1
unnamed: D6.1 (K), R31.1
unnamed: D7.2 (A), R30.2
unnamed: D7.1 (K), Q5.3 (D)
unnamed: D9.1 (K), R34.1
unnamed: D12.1 (K), R53.1
unnamed: D13.1 (K), R54.1
unnamed: D14.1 (K), J2.A5, R57.1
unnamed: D15.1 (K), J2.B5, R58.1
unnamed: D16.1 (K), R63.1
unnamed: D19.1 (K), J5.2, Q11.3 (D)
unnamed: D22.1 (K), R107.1
unnamed: D23.1 (K), R109.1
unnamed: D24.1 (K), R111.1
unnamed: D25.2 (A), U25.1
unnamed: D25.1 (K), R130.1
unnamed: D26.1 (K), R106.2, R122.1, U22.9 (IMON)
unnamed: D27.1 (K), R108.2, R124.1, U23.9 (IMON)
unnamed: D28.1 (K), R110.2, R127.1, U24.9 (IMON)
unnamed: D29.2 (A), U25.3
unnamed: D29.1 (K), R113.1
unnamed: D34.1 (K), R163.1
unnamed: D35.1 (K), R165.1
unnamed: D36.1 (K), R167.1
unnamed: D37.1 (K), R169.1
unnamed: D38.1 (K), R161.2, R177.1, U36.9 (IMON)
unnamed: D39.1 (K), R160.2, R180.1, U35.9 (IMON)
unnamed: D40.1 (K), R168.2, R181.1, U38.9 (IMON)
unnamed: D41.1 (K), R166.2, R187.1, U37.9 (IMON)
unnamed: C50.1, IC1.38 (IO2), U9.4
unnamed: IC1.19 (IO11), R44.2, R49.1
unnamed: JP1.1 (A), U8.11 (VDC_OUT)
unnamed: Q1.4 (G), U5.3 (GATE)
unnamed: Q1.1 (S), Q1.2 (S), Q1.3 (S), R4.1, R9.2
unnamed: Q2.3 (D), R12.2
unnamed: Q3.3 (D), R13.2
unnamed: Q7.3 (D), R31.2
unnamed: Q8.3 (D), R53.2
unnamed: Q9.3 (D), R54.2
unnamed: Q10.3 (D), R63.2
unnamed: Q12.3 (D), R107.2
unnamed: Q13.3 (D), R109.2
unnamed: Q14.3 (D), R111.2
unnamed: Q15.3 (D), R163.2
unnamed: Q16.3 (D), R165.2
unnamed: Q17.3 (D), R167.2
unnamed: Q18.3 (D), R169.2
unnamed: R11.2, R16.1, U3.6
unnamed: R26.1, R27.1, R28.1, U3.4
unnamed: R41.1, R45.1, U12.3
unnamed: R42.1, R46.1, U12.1
unnamed: R56.2, R59.1, U14.1
unnamed: R195.1, R196.2, R198.1
unnamed: R1.2, R6.1, U1.11 (EN)
unnamed: C24.1, R3.1, R5.1, U1.4 (FB)
unnamed: C26.2, U1.9 (VCC), U1.12 (MODE)
unnamed: C25.1, U1.5 (SS)
unnamed: C1.1, U1.8 (VBST)
unnamed: R2.1, R7.1, U4.3 (+)
unnamed: R14.1, R21.2, U4.4 (-)
unnamed: C31.1, R15.1, U5.6 (COMP)
unnamed: C27.1, R4.2, U5.5 (CS)
unnamed: R10.1, R20.1, U5.8 (FB)
unnamed: R17.2, U5.10 (RT)
unnamed: C30.1, U5.9 (SS)
unnamed: R22.1, R24.1, U6.4 (-)
unnamed: R23.1, R25.1, U7.4 (-)
unnamed: R29.1, U8.10 (FLIP)
unnamed: R21.1, U8.3 (VBUS_FET_EN)
unnamed: C33.1, U8.24 (VCCD)
unnamed: C56.1, R47.1, U11.4 (TS)
unnamed: C69.1, R51.1, R55.1, U13.4 (FB)
unnamed: C75.2, U13.9 (VCC), U13.12 (MODE)
unnamed: C74.1, U13.5 (SS)
unnamed: C62.1, U13.8 (VBST)
unnamed: R64.1, R67.1, U15.3 (+)
unnamed: R65.1, R68.1, U16.3 (+)
unnamed: C77.1, J2.A4-B9, J2.B4-A9, U17.5 (VBUS)
unnamed: R70.1, R71.1, U18.4 (-)
unnamed: R97.2, U19.10 (ILM)
unnamed: R74.2, R80.1, U19.5 (OV1)
unnamed: R89.2, R100.1, U19.4 (OV2)
unnamed: R72.2, R76.1, U19.6 (PR1)
unnamed: C93.2, U19.11 (SS)
unnamed: R120.1, U19.9 (ST), U30.3 (+)
unnamed: C95.2, U22.7 (DVDT)
unnamed: R86.1, R102.1, U22.2 (OVLO)
unnamed: R112.1, U22.3 (PG), U27.3 (+)
unnamed: R82.1, R91.1, U22.4 (PGTH)
unnamed: C98.2, U23.7 (DVDT)
unnamed: R83.1, R92.1, U23.1 (EN/UVLO)
unnamed: R92.2, R103.1, U23.2 (OVLO)
unnamed: R118.1, U23.3 (PG), U28.3 (+)
unnamed: R84.1, R93.1, U23.4 (PGTH)
unnamed: C99.2, U24.7 (DVDT)
unnamed: R85.1, R96.1, U24.2 (OVLO)
unnamed: R119.1, U24.3 (PG), U29.3 (+)
unnamed: R87.1, R94.1, U24.4 (PGTH)
unnamed: R81.1, R88.2, U26.4 (P00)
unnamed: R78.1, R90.2, U26.5 (P01)
unnamed: R75.1, R95.2, U26.6 (P02)
unnamed: R73.1, R98.2, U26.7 (P03)
unnamed: R99.2, R136.1, U26.8 (P04)
unnamed: R101.2, R132.1, U26.9 (P05)
unnamed: R104.2, R126.1, U26.10 (P06)
unnamed: R105.2, R121.1, U26.11 (P07)
unnamed: R123.1, R131.1, U27.4 (-)
unnamed: R125.1, R133.1, U28.4 (-)
unnamed: R128.1, R135.1, U29.4 (-)
unnamed: R129.1, R134.1, U30.4 (-)
unnamed: C106.2, U35.7 (DVDT)
unnamed: R142.1, R156.1, U35.2 (OVLO)
unnamed: R176.1, U35.3 (PG), U45.3 (+)
unnamed: R138.1, R147.1, U35.4 (PGTH)
unnamed: R162.2, U36.7 (DVDT)
unnamed: R143.1, R157.1, U36.2 (OVLO)
unnamed: R175.1, U36.3 (PG), U44.3 (+)
unnamed: R139.1, R148.1, U36.4 (PGTH)
unnamed: C107.2, U37.7 (DVDT)
unnamed: R144.1, R158.1, U37.2 (OVLO)
unnamed: R178.1, U37.3 (PG), U46.3 (+)
unnamed: R140.1, R149.2, U37.4 (PGTH)
unnamed: R164.2, U38.7 (DVDT)
unnamed: R145.1, R159.1, U38.2 (OVLO)
unnamed: R179.1, U38.3 (PG), U47.3 (+)
unnamed: R141.1, R150.1, U38.4 (PGTH)
unnamed: R146.2, R173.2, U43.4 (P00)
unnamed: R151.2, R172.2, U43.5 (P01)
unnamed: R152.2, R171.2, U43.6 (P02)
unnamed: R154.2, R170.2, U43.7 (P03)
unnamed: R155.2, R174.2, U43.8 (P04)
unnamed: R186.1, R191.1, U44.4 (-)
unnamed: R188.1, R192.1, U45.4 (-)
unnamed: R189.1, R193.1, U46.4 (-)
unnamed: R190.1, R194.1, U47.4 (-)
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

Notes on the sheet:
20V->5V SS BUCK
IN1 = +VBUS (PRIMARY) | IN2 = +VCAP_VALID (ARMED BACKUP) VALID INPUT RANGE: 2.8-22.8 V | CURRENT LIMIT: ≈4.55 A TYP HANDOVER: VBUS→VCAP @17.6 V↓ | VCAP→VBUS @17.7 V↑ | ≈5 µs TYP
OVLO_R=7.0V, OVLO_F=6.5V PGTH_R=4.5V, PGTH_F=4.1V T_CH=84ms, I_CH=0.23A (@COUT = 4000uF)
DC INRUSH CTRL
V_OUT = 2.1x(1+RFT/RFB) = 20.6V
12V<=VIN<=21V, VOUT=3V3, IOUT_MAX=100mA
3V3 VCAP LDO
SUPER CAP SWITCH
24.5V BOOST
USB-C->ESP32 (NO PWR)
ESP32 LEDs
3V3 VBUS LDO
BOOT + RESET
OVLO_R=22.8V, OVLO_F=20.9V PGTH_R=17.1V, PGTH_F=15.65V T_CH=47ms, I_CH=0.2A (@COUT = 480uF)
3V3 SS LDO
SS POWER SWITCH
VBUS POWER SWITCH
POWER MUX
20V->5V BUCK
I2C -> GPIO INTERNAL CONTROL
I_CHARGE = V_ISET / (20 x R_SR), SCC_ISET_SW LOW -> I_CHARGE=1A, SCC_ISET_SW HIGH -> I_CHARGE=1.9A
5V SS POWER SWITCH
VCAP ADC DIV
OVLO_R=22.8V, OVLO_F=20.9V PGTH_R=4.5V, PGTH_F=4.1V T_CH=47ms, I_CH=0.2A (@COUT = 480uF)
9V<=V_IN<=20.5V, V_OUT = 5.1V, I_OUT_MAX = 5A
VIN=5V, VOUT=3V3, IOUT_MAX=1A
VBUS_MIN,VBUS_MAX = 3V3 -> 20V FROM USBC
UVLO_R=17.5V, UVLO_F=16.0V, OVLO_R=22.1V, OVLO_F=20.3V PGTH_R=17.1V, PGTH_F=15.65V T_CH=47ms, I_CH=0.2A (@COUT = 480uF)
I2C -> GPIO EXTERNAL CONTROL
OVLO_R=7.0V, OVLO_F=6.5V PGTH_R=4.5V, PGTH_F=4.11V T_CH=84ms, I_CH=0.23A (@COUT = 4000uF)
2V5 VCAP VREF
OVLO_R=22.8V, OVLO_F=20.9V PGTH_R=9.9V, PGTH_F=9.1V T_CH=47ms, I_CH=0.2A (@COUT = 480uF)
5V VBUS POWER SWITCH
12V<=VIN<=21V, VOUT=24.5V, IOUT_MAX=2A
SOFT START = 16.8ms, I_INRUSH BASED ON C_LOAD OF 2000u IS 0.6A
A2:A0 = 000 → 7-BIT I²C ADDRESS 0x20
ESP32 UART0
ESP32-S3
ISINK IS NOT GUARANTEED, ANY ADVERTISED CURRENT IS ACCEPTED, READ BY ESP32 TO VALIDATE
USBC PD

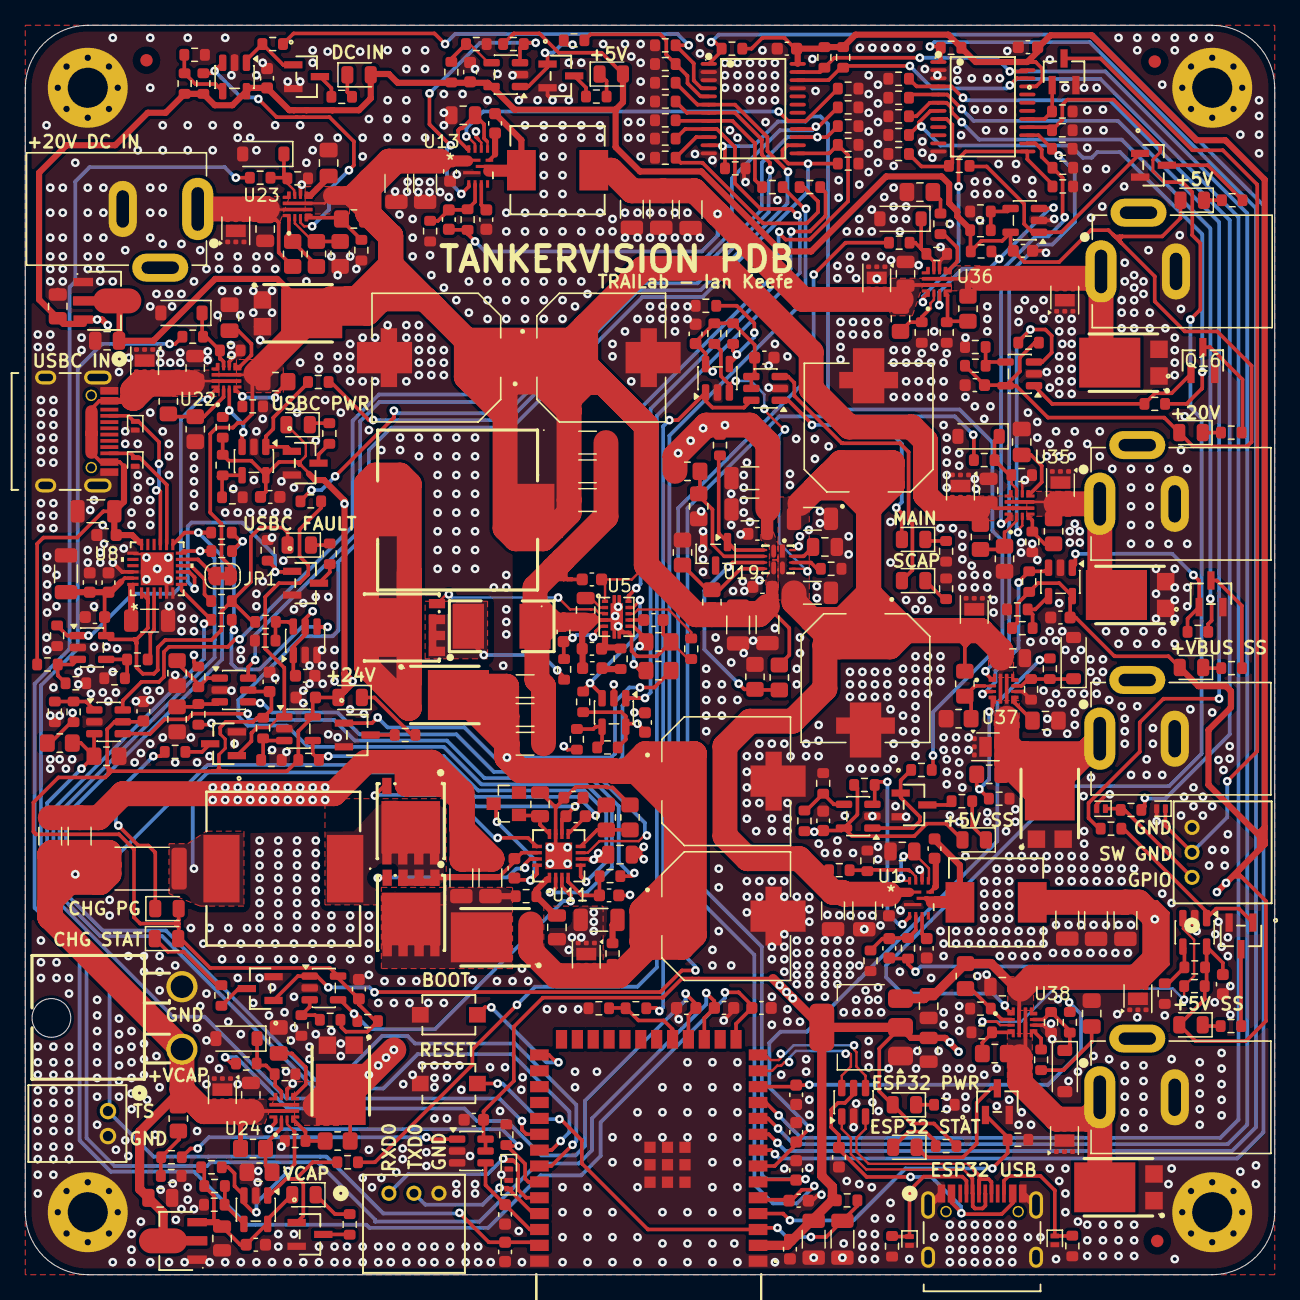
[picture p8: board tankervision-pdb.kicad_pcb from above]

Board: 4 copper layers, 100.0 x 100.0 mm, 452 parts (0 on the bottom side), 234 nets.

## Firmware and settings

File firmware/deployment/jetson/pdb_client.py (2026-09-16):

#!/usr/bin/env python3
"""Tankervision PDB protocol v1 client. Importing this module never opens USB.

The default CLI monitors and answers pings. Host shutdown requires explicit
--allow-host-poweroff, --cleanup-command, and --poweroff-command options.
"""

from __future__ import annotations

import argparse
from collections import OrderedDict
from dataclasses import dataclass
import json
import math
import queue
import secrets
import shlex
import subprocess
import sys
import threading
import time
from typing import Callable

MAX_RX_LINE = 8192
MAX_TX_LINE = 512
UINT32_MAX = 0xFFFFFFFF
PORTS = ("vbus", "5v_vbus", "5v_ss")


def uint32(value: object, *, positive: bool = False) -> bool:
    return type(value) is int and (1 if positive else 0) <= value <= UINT32_MAX


def reject_constant(value: str) -> None:
    raise ValueError(f"Non-JSON constant {value}")


def finite_float(value: str) -> float:
    number = float(value)
    if not math.isfinite(number):
        raise ValueError("JSON number exceeds finite float range")
    return number


def unique_object(pairs: list[tuple[str, object]]) -> dict:
    result = {}
    for key, value in pairs:
        if key in result:
            raise ValueError(f"Duplicate JSON key {key}")
        result[key] = value
    return result


class JsonLines:
    """Bound memory use; discard an oversized line through its next LF."""

    def __init__(self, report: Callable[[str], None] = lambda _: None):
        self.buffer = bytearray()
        self.discarding = False
        self.report = report

    def feed(self, data: bytes) -> list[dict]:
        messages = []
        # Serial reads are bounded by the caller; a single oversized frame never
        # accumulates in self.buffer, including across multiple reads.
        for chunk_index, chunk in enumerate(data.split(b"\n")):
            if chunk_index:
                if not self.discarding and self.buffer:
                    try:
                        message = json.loads(
                            self.buffer.decode("utf-8"),
                            parse_constant=reject_constant,
                            parse_float=finite_float,
                            object_pairs_hook=unique_object,
                        )
                        if not isinstance(message, dict):
                            raise ValueError("Expected a JSON object")
                        messages.append(message)
                    except (UnicodeError, ValueError, RecursionError) as error:
                        self.report(f"Ignored invalid JSON line: {error}")
                self.buffer.clear()
                self.discarding = False
            if not self.discarding:
                if len(self.buffer) + len(chunk) > MAX_RX_LINE:
                    self.buffer.clear()
                    self.discarding = True
                    self.report("Discarded oversized USB line")
                else:
                    self.buffer.extend(chunk)
        return messages


@dataclass(frozen=True)
class ShutdownRequest:
    boot_id: str
    shutdown_id: int
    reason: str
    deadline_ms: int
    remaining_ms: int


@dataclass(frozen=True)
class ShutdownHooks:
    # prepare runs in a daemon worker, leaving USB reception/pongs active.
    # It must honor timeout itself if it starts any work that must be cancelled.
    prepare: Callable[[ShutdownRequest, float], bool]
    poweroff: Callable[[], bool]
    timeout: float = 45.0


@dataclass
class _ShutdownAttempt:
    request: ShutdownRequest
    deadline: float
    started: float
    timeout: float
    failed: bool = False
    cleanup_done: bool = False
    ready_id: int | None = None
    ready_sent: float = 0.0
    poweroff_started: bool = False


class PdbClient:
    """Transport-independent client. Call receive() and poll() from one thread.

    send_bytes must write the entire buffer or raise. A partial failed send is
    fatal to that transport: never retry the remaining line on another session.
    No serial handle or poweroff command is created by this class.
    """

    def __init__(self, send_bytes: Callable[[bytes], None], *,
                 report: Callable[[str], None] = lambda _: None,
                 on_message: Callable[[dict], None] = lambda _: None,
                 clock: Callable[[], float] = time.monotonic,
                 shutdown_hooks: ShutdownHooks | None = None,
                 ack_shutdown: bool = False, first_request_id: int | None = None):
        if shutdown_hooks and (not math.isfinite(shutdown_hooks.timeout)
                               or not 0 < shutdown_hooks.timeout <= 45):
            raise ValueError("Cleanup timeout must be greater than 0 and at most 45 seconds")
        self.send_bytes = send_bytes
        self.report = report
        self.on_message = on_message
        self.clock = clock
        self.hooks = shutdown_hooks
        self.ack_shutdown = ack_shutdown or shutdown_hooks is not None
        self.boot_id: str | None = None
        self.telemetry: dict | None = None
        self.next_id = first_request_id if first_request_id is not None else secrets.randbelow(UINT32_MAX) + 1
        if not uint32(self.next_id, positive=True):
            raise ValueError("Invalid initial request id")
        self.responses: OrderedDict[int, dict] = OrderedDict()
        self.port_results: OrderedDict[int, dict] = OrderedDict()
        self.attempt: _ShutdownAttempt | None = None
        self.results: queue.Queue = queue.Queue()

    def request(self, command: str, **fields: object) -> int:
        allowed = {
            "status": set(), "pong": {"ping_id"},
            "shutdown_ack": {"shutdown_id"}, "shutdown_ready": {"shutdown_id"},
            "port_set": {"port", "enabled"}, "reboot": set(),
        }
        if command not in allowed or set(fields) != allowed[command]:
            raise ValueError("Unknown command or incorrect command fields")
        if command != "status" and self.boot_id is None:
            raise RuntimeError("Read the device boot_id before sending a mutation")
        if command == "port_set":
            if fields["port"] not in PORTS or type(fields["enabled"]) is not bool:
                raise ValueError("Invalid controllable port or non-boolean enabled value")
        for name in ("ping_id", "shutdown_id"):
            if name in fields and not uint32(fields[name]):
                raise ValueError(f"Invalid {name}")
        request_id = self.next_id
        self.next_id = 1 if request_id == UINT32_MAX else request_id + 1
        message = {"v": 1, "id": request_id, "cmd": command}
        if command != "status":
            message["boot_id"] = self.boot_id
        message.update(fields)
        encoded = json.dumps(message, separators=(",", ":"), allow_nan=False).encode("utf-8")
        if len(encoded) > MAX_TX_LINE:
            raise ValueError("Request exceeds firmware line limit")
        self.send_bytes(encoded + b"\n")
        return request_id

    @staticmethod
    def _remember(history: OrderedDict, key: int, message: dict) -> None:
        history[key] = message
        history.move_to_end(key)
        while len(history) > 128:
            history.popitem(last=False)

    def receive(self, message: dict) -> bool:
        """Validate a framed device object, process it, then notify the observer."""
        boot = message.get("boot_id")
        if (type(message.get("v")) is not int or message["v"] != 1
                or message.get("type") not in ("telemetry", "event", "response")
                or not isinstance(boot, str) or len(boot) != 8
                or any(c not in "0123456789ABCDEF" for c in boot)
                or not uint32(message.get("seq")) or not uint32(message.get("uptime_ms"))):
            self.report("Ignored message with invalid protocol envelope")
            return False
        kind = message["type"]
        if kind == "response" and (not uint32(message.get("id"))
                                   or type(message.get("ok")) is not bool
                                   or not isinstance(message.get("code"), str)):
            self.report("Ignored invalid response")
            return False
        if self.boot_id != boot:
            if self.boot_id is not None:
                self.report(f"Device restarted: boot_id {self.boot_id} -> {boot}")
            self.boot_id = boot
            self.telemetry = None
            self.responses.clear()
            self.port_results.clear()
            self.attempt = None  # Old cleanup completion must never power off a new boot.
        if kind == "response":
            self._remember(self.responses, message["id"], message)
            attempt = self.attempt
            if attempt and message["id"] == attempt.ready_id:
                if message["ok"] and message["code"] == "OK":
                    self._start_poweroff(attempt)
                else:
                    attempt.failed = True
                    self.report(f"Final-ready was rejected: {message['code']}; host poweroff not started")
        elif kind == "telemetry":
            self.telemetry = message
            if isinstance(message.get("shutdown"), dict):
                self._shutdown(message["shutdown"])
        elif message.get("event") == "ping":
            if uint32(message.get("ping_id")):
                self.request("pong", ping_id=message["ping_id"])
            else:
                self.report("Ignored ping with invalid ping_id")
        elif message.get("event") == "shutdown_requested":
            self._shutdown(message)
        elif message.get("event") == "port_result":
            if (uint32(message.get("request_id"), positive=True)
                    and message.get("port") in PORTS
                    and type(message.get("enabled")) is bool
                    and type(message.get("ok")) is bool
                    and isinstance(message.get("code"), str)):
                self._remember(self.port_results, message["request_id"], message)
            else:
                self.report("Ignored invalid port_result")
        self.on_message(message)
        return True

    def _shutdown(self, fields: dict) -> None:
        remaining = fields.get("remaining_ms")
        if (not uint32(fields.get("shutdown_id")) or not uint32(fields.get("deadline_ms"))
                or not uint32(remaining) or remaining > 60000
                or fields.get("reason") not in ("MAIN_LOSS", "FULL_REBOOT")):
            self.report("Ignored invalid shutdown request")
            return
        now = self.clock()
        request = ShutdownRequest(self.boot_id, fields["shutdown_id"], fields["reason"],
                                  fields["deadline_ms"], remaining)
        if self.attempt:
            if (self.attempt.request.boot_id, self.attempt.request.shutdown_id) != (request.boot_id, request.shutdown_id):
                self.report("Ignored conflicting shutdown id within one boot")
                return
            # Repeated telemetry cannot extend the host's estimate of the deadline.
            self.attempt.deadline = min(self.attempt.deadline, now + remaining / 1000)
            return
        timeout = min(self.hooks.timeout if self.hooks else 45.0, max(0.0, remaining / 1000 - 1.0))
        attempt = self.attempt = _ShutdownAttempt(request, now + remaining / 1000, now, timeout)
        self.report(f"Shutdown {request.shutdown_id}: {request.reason}, {remaining} ms remaining")
        if self.ack_shutdown and remaining:
            self.request("shutdown_ack", shutdown_id=request.shutdown_id)
        if not self.hooks:
            self.report("Host shutdown is not enabled; final-ready will not be sent")
            return
        if timeout <= 0:
            attempt.failed = True
            self.report("Too little time remains to prepare host shutdown")
            return

        def prepare() -> None:
            try:
                result = self.hooks.prepare(request, timeout)
                self.results.put((attempt, "prepare", result is True, ""))
            except Exception as error:
                self.results.put((attempt, "prepare", False, str(error)))

        threading.Thread(target=prepare, name="pdb-shutdown-prepare", daemon=True).start()

    def _start_poweroff(self, attempt: _ShutdownAttempt) -> None:
        if (attempt is not self.attempt or attempt.failed or attempt.poweroff_started
                or self.clock() >= attempt.deadline
                or self.clock() - attempt.ready_sent >= 1.0 or not self.hooks):
            return
        attempt.poweroff_started = True
        self.report("Final-ready accepted; starting the explicitly configured host poweroff action")

        def poweroff() -> None:
            try:
                self.results.put((attempt, "poweroff", self.hooks.poweroff() is True, ""))
            except Exception as error:
                self.results.put((attempt, "poweroff", False, str(error)))

        threading.Thread(target=poweroff, name="pdb-host-poweroff", daemon=True).start()

    def poll(self) -> None:
        """Service worker completions/timeouts; never waits for a cleanup worker."""
        now = self.clock()
        attempt = self.attempt
        if attempt and self.hooks and not attempt.failed and not attempt.poweroff_started:
            if now >= attempt.deadline:
                attempt.failed = True
                self.report("Shutdown deadline reached; no further host action will be started")
            elif not attempt.cleanup_done and now - attempt.started >= attempt.timeout:
                attempt.failed = True
                self.report("Cleanup timed out; final-ready will not be sent")
            elif attempt.ready_id is not None and now - attempt.ready_sent >= 1.0:
                attempt.failed = True
                self.report("Final-ready response timed out; host poweroff not started")
        while True:
            try:
                finished, stage, ok, detail = self.results.get_nowait()
            except queue.Empty:
                break
            if finished is not self.attempt or finished.failed:
                continue
            if not ok:
                finished.failed = True
                self.report(f"Host {stage} action failed: {detail or 'non-success return'}")
            elif stage == "prepare":
                finished.cleanup_done = True
                # Readiness is sent once, after cleanup, immediately before the
                # explicit poweroff action (which waits at most 1 s for its OK).
                finished.ready_id = self.request("shutdown_ready", shutdown_id=finished.request.shutdown_id)
                finished.ready_sent = self.clock()
            else:
                self.report("Host poweroff action accepted by the operating system")


def run_command(argv: list[str], timeout: float) -> bool:
    """Run an explicit argument list, without a shell or implicit privileges."""
    result = subprocess.run(argv, timeout=timeout, check=False,
                            stdout=sys.stderr, stderr=sys.stderr)
    return result.returncode == 0


def open_serial(device: str):
    # Deferred import allows pure protocol tests without pyserial installed.
    import serial

    options = {"baudrate": 115200, "timeout": 0.1, "write_timeout": 0.2,
               "xonxoff": False, "rtscts": False, "dsrdtr": False}
    if sys.platform.startswith("linux"):
        options["exclusive"] = True
    connection = serial.Serial(port=None, **options)
    # Arduino TinyUSB CDC requires asserted control lines. Reboot hooks must
    # already be disabled in the deployment firmware before USB.begin().
    connection.dtr = True
    connection.rts = True
    connection.port = device
    connection.open()
    return connection


def main(argv: list[str] | None = None) -> int:
    parser = argparse.ArgumentParser(description=__doc__)
    parser.add_argument("--device", required=True, help="Deployment CDC device, preferably /dev/serial/by-id/...")
    parser.add_argument("--log", help="Append received protocol JSON lines to this file")
    parser.add_argument("--ack-shutdown", action="store_true", help="ACK requests without claiming final-ready or powering off")
    parser.add_argument("--allow-host-poweroff", action="store_true", help="Explicitly enable the configured host poweroff action")
    parser.add_argument("--cleanup-command", help="Explicit cleanup argv, shell quoting accepted; no shell is run")
    parser.add_argument("--poweroff-command", help="Explicit poweroff argv, e.g. '/usr/bin/systemctl poweroff'")
    parser.add_argument("--cleanup-timeout", type=float, default=45, help="Cleanup timeout in seconds, maximum 45")
    commands = parser.add_subparsers(dest="command")
    commands.add_parser("monitor", help="Stream telemetry and answer pings (default)")
    commands.add_parser("status", help="Read one current telemetry snapshot")
    port_parser = commands.add_parser("port", help="Set an optional external output")
    port_parser.add_argument("port_name", choices=PORTS)
    port_parser.add_argument("enabled", choices=("on", "off"))
    commands.add_parser("reboot", help="Request the board's fixed 60-second full-reboot sequence")
    args = parser.parse_args(argv)
    configured = (bool(args.cleanup_command), bool(args.poweroff_command), args.allow_host_poweroff)
    if any(configured) and not all(configured):
        parser.error("Host shutdown requires --allow-host-poweroff, --cleanup-command, and --poweroff-command together")
    if not math.isfinite(args.cleanup_timeout) or not 0 < args.cleanup_timeout <= 45:
        parser.error("--cleanup-timeout must be greater than 0 and at most 45 seconds")
    hooks = None
    if all(configured):
        cleanup_argv, poweroff_argv = shlex.split(args.cleanup_command), shlex.split(args.poweroff_command)
        if not cleanup_argv or not poweroff_argv:
            parser.error("Explicit shutdown commands must not be empty")
        hooks = ShutdownHooks(lambda _request, timeout: run_command(cleanup_argv, timeout),
                              lambda: run_command(poweroff_argv, 5.0), args.cleanup_timeout)
    log_file = open(args.log, "a", encoding="utf-8", buffering=1) if args.log else None

    def report(text: str) -> None:
        print(f"{time.strftime('%Y-%m-%dT%H:%M:%SZ', time.gmtime())} {text}", file=sys.stderr, flush=True)

    def display(message: dict) -> None:
        line = json.dumps(message, separators=(",", ":"), allow_nan=False)
        print(line, flush=True)
        if log_file:
            log_file.write(line + "\n")

    connection = None
    try:
        connection = open_serial(args.device)

        def send(data: bytes) -> None:
            if connection.write(data) != len(data):
                raise OSError("Partial USB write; stopping without retrying a mutation")

        client = PdbClient(send, report=report, on_message=display,
                           shutdown_hooks=hooks, ack_shutdown=args.ack_shutdown)
        framer = JsonLines(report)
        report("Opened deployment TinyUSB CDC; control lines remain asserted, no reset requested")
        client.request("status")
        command = args.command or "monitor"
        request_id = None
        started = time.monotonic()
        while True:
            data = connection.read(4096)
            for message in framer.feed(data):
                client.receive(message)
            client.poll()
            if command == "status" and client.telemetry is not None:
                return 0
            if client.telemetry is not None and request_id is None:
                if command == "port":
                    request_id = client.request("port_set", port=args.port_name, enabled=args.enabled == "on")
                elif command == "reboot":
                    request_id = client.request("reboot")
            if request_id in client.responses:
                response = client.responses[request_id]
                if not response["ok"]:
                    return 1
                if command == "reboot":
                    return 0
                if request_id in client.port_results:
                    return 0 if client.port_results[request_id]["ok"] else 1
            if command != "monitor" and time.monotonic() - started > 10:
                report("Command result timed out; no automatic resend or reset was attempted")
                return 2
    except KeyboardInterrupt:
        return 0
    except Exception as error:
        report(f"Client stopped: {error}; no automatic reset or reopen was attempted")
        return 2
    finally:
        if connection is not None:
            connection.close()
        if log_file:
            log_file.close()


if __name__ == "__main__":
    raise SystemExit(main())

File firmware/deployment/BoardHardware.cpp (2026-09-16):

#include "BoardHardware.h"

#include <driver/gpio.h>
#include <math.h>
#include <stdarg.h>
#include <stdio.h>

namespace {
constexpr uint8_t kInternal = 0x20, kExternal = 0x21;
constexpr uint8_t kBoost = 0x01, kCe = 0x02, kHighCurrent = 0x04, kTsOverride = 0x08, kBuck = 0x10;
constexpr uint8_t kDefined = 0x1f, kUnusedInputs = 0xe0;
constexpr int kLed = 4, kBackup = 42, kMux = 11, kBoot = 0;
constexpr uint32_t kDecayMs = 100, kTsSettleMs = 500, kFreshMs = 350;
constexpr uint8_t kAdcPins[] = {1, 2, 3, 5, 6, 7, 8, 9, 10};
constexpr const char *kAdcNames[] = {"TS", "VCAP", "IMON_DC", "IMON_J8", "IMON_J7", "IMON_J9", "IMON_J10", "IMON_USB", "IMON_BACKUP"};
bool high(uint8_t value, unsigned position) { return (value & (1u << position)) != 0; }
}

const char *BoardHardware::adcName(unsigned index) { return index < 9 ? kAdcNames[index] : "INVALID"; }

bool BoardHardware::fail(const char *format, ...) {
  if (!error_[0]) {
    va_list args;
    va_start(args, format);
    vsnprintf(error_, sizeof(error_), format, args);
    va_end(args);
  }
  return false;
}

bool BoardHardware::readPair(uint8_t address, uint8_t reg, uint8_t values[2]) {
  // Selecting the register address is necessary for a read. This sends no
  // register DATA and does not change outputs, polarity or configuration.
  Wire.beginTransmission(address);
  Wire.write(reg);
  const uint8_t code = Wire.endTransmission(false);
  if (code) return fail("I2C %02X register %02X select failed (%u)", address, reg, code);
  const size_t count = Wire.requestFrom(address, uint8_t(2));
  if (count != 2 || Wire.available() != 2) {
    while (Wire.available()) Wire.read();
    return fail("I2C %02X register %02X short read (%u)", address, reg, unsigned(count));
  }
  values[0] = Wire.read();
  values[1] = Wire.read();
  return true;
}

bool BoardHardware::writeRegister(uint8_t address, uint8_t reg, uint8_t value) {
  Wire.beginTransmission(address);
  Wire.write(reg);
  Wire.write(value);
  const uint8_t code = Wire.endTransmission();
  return code == 0 || fail("I2C %02X register %02X write failed (%u)", address, reg, code);
}

bool BoardHardware::readExpander(uint8_t address, ExpanderState &state) {
  ExpanderState next;
  // TCA9535 register auto-increment wraps within pairs, not across all 8 bytes.
  if (!readPair(address, 0, next.input) || !readPair(address, 2, next.output) ||
      !readPair(address, 4, next.polarity) || !readPair(address, 6, next.config)) {
    state.valid = false;  // Retain old raw bytes and timestamp, explicitly invalid.
    return false;
  }
  next.physicalInputs = uint16_t(next.input[0] ^ next.polarity[0]) |
      (uint16_t(next.input[1] ^ next.polarity[1]) << 8);
  next.atMs = millis();
  next.valid = true;
  state = next;
  return true;
}

void ARDUINO_ISR_ATTR BoardHardware::onInterrupt(void *argument) {
  auto *line = static_cast<IrqLine *>(argument);
  const bool level = gpio_get_level(static_cast<gpio_num_t>(line->gpio));
  portENTER_CRITICAL_ISR(&line->owner->irqMux_);
  if (level) line->rises = line->rises + 1;
  else line->falls = line->falls + 1;
  portEXIT_CRITICAL_ISR(&line->owner->irqMux_);
}

bool BoardHardware::beginMonitoring() {
  error_[0] = '\0';
  if (monitoring_) return fail("Monitoring already initialized");
  // Set hardware latches before Arduino's peripheral manager attaches outputs.
  gpio_set_level(static_cast<gpio_num_t>(kBackup), 0);
  pinMode(kBackup, OUTPUT);
  digitalWrite(kBackup, LOW);
  gpio_set_level(static_cast<gpio_num_t>(kLed), 1);
  pinMode(kLed, OUTPUT);
  digitalWrite(kLed, HIGH);
  // GPIO_0 connects only IC1 and SW1 to ground; retain a pull-up after boot.
  pinMode(kBoot, INPUT_PULLUP);
  analogReadResolution(12);
  for (uint8_t pin : kAdcPins) analogSetPinAttenuation(pin, ADC_11db);
  const uint8_t irqPins[] = {15, 16, 11, 39};
  for (unsigned i = 0; i < 4; ++i) {
    irq_[i].owner = this;
    irq_[i].gpio = irqPins[i];
    pinMode(irqPins[i], INPUT);  // Board pull-ups; no internal pull-up substitution.
    attachInterruptArg(irqPins[i], onInterrupt, &irq_[i], CHANGE);
  }
  if (!Wire.begin(17, 18, 100000)) return fail("Control I2C initialization failed; expander state unknown");
  Wire.setTimeOut(25);
  monitoring_ = true;
  return true;
}
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

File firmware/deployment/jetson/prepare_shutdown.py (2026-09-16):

#!/usr/bin/env python3
"""Optional Jetson cleanup hook: stop explicitly named services, then sync.

This program does not power off. It is not invoked by the client unless supplied
as --cleanup-command. Customize it when application cleanup needs more than a
normal systemd service stop.
"""

from __future__ import annotations

import argparse
import re
import subprocess
import time


def prepare_services(services: list[str], timeout: float = 40, *,
                     runner=subprocess.run, clock=time.monotonic) -> bool:
    if not services or any(not re.fullmatch(r"[A-Za-z0-9_][A-Za-z0-9_.@:-]*\.service", name)
                           for name in services):
        raise ValueError("Explicit valid systemd .service unit names are required")
    if not 0 < timeout <= 45:
        raise ValueError("Cleanup timeout must be greater than 0 and at most 45 seconds")
    deadline = clock() + timeout
    # subprocess receives argv directly. No shell, sudo, reboot, or poweroff.
    for command in (["systemctl", "stop", "--", *services], ["sync"]):
        remaining = deadline - clock()
        if remaining <= 0:
            return False
        try:
            if runner(command, check=False, timeout=remaining).returncode != 0:
                return False
        except (OSError, subprocess.TimeoutExpired):
            return False
    return clock() < deadline


def main(argv: list[str] | None = None) -> int:
    parser = argparse.ArgumentParser(description=__doc__)
    parser.add_argument("--service", required=True, action="append", help="Application .service unit; repeat for multiple units")
    parser.add_argument("--timeout", type=float, default=40, help="Combined stop+sync budget, maximum 45 seconds")
    args = parser.parse_args(argv)
    try:
        return 0 if prepare_services(args.service, args.timeout) else 1
    except ValueError as error:
        parser.error(str(error))
    return 2


if __name__ == "__main__":
    raise SystemExit(main())

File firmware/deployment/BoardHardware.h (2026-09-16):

#pragma once

#include <Arduino.h>
#include <Wire.h>
#include <freertos/FreeRTOS.h>

enum class Port : uint8_t { Vbus, FiveVoltVbus, VbusSs, FiveVoltSs };

struct ExpanderState {
  bool valid = false;
  uint32_t atMs = 0;
  uint8_t input[2] = {}, output[2] = {}, polarity[2] = {}, config[2] = {};
  uint16_t physicalInputs = 0;  // Input registers XOR polarity, including reserved pins.
};

struct AnalogReading {
  uint8_t gpio = 0;
  uint16_t raw = 0;       // Averaged 12-bit ADC count.
  uint32_t mv = 0;        // Averaged adjacent ADC conversions in millivolts.
  float currentA = 0;     // Nominal uncalibrated IMON estimate; NAN for TS/VCAP.
};

struct HardwareSnapshot {
  uint32_t atMs = 0;
  bool valid = false;     // Both expander snapshots valid; ADC/GPIO still sampled on failure.
  ExpanderState internal, external;
  // ADC order: TS, VCAP, DC IMON, J8 IMON, J7 IMON, J9 IMON, J10 IMON, USB IMON, backup IMON.
  AnalogReading adc[9];
  float vcapV = 0;
  uint32_t tsMv = 0;
  bool usbPg = false, dcPg = false, backupPg = false, chargerPg = false, chargerStat = false;
  bool boostPg = false, buckPg = false, ssBuckPg = false;
  bool extVbusPg = false, ext5vVbusPg = false, extSsPg = false, ext5vSsPg = false;
  bool jetsonOn = false, mainSelected = false, backupEnabled = false, statusLed = false;
  bool bootButtonLow = false;  // SW1/GPIO0 pressed; no external pull-up on this PCB.
  bool internalIrqLow = false, externalIrqLow = false, pdIrqLow = false;
  uint32_t internalIrqFalls = 0, internalIrqRises = 0, externalIrqFalls = 0, externalIrqRises = 0;
  uint32_t muxFalls = 0, muxRises = 0, pdIrqFalls = 0, pdIrqRises = 0;
};

// One main-loop owner for this object and Wire. No delay(), PG wait loops, serial,
// PD bus calls or flash writes. I2C transactions have a 25 ms timeout.
class BoardHardware {
 public:
  enum class Result : uint8_t { Idle, Running, Succeeded, Failed };
  enum class Operation : uint8_t { None, Reconcile, PrepareCharge, EnableCharge, DisableCharging, PortChange, RestorePor };
  bool beginMonitoring();  // GPIO42 low/D7 high; no expander register-data writes.
  bool poll();             // Read all ADC/GPIO and both full register sets; call ~100 ms.
  const HardwareSnapshot &snapshot() const { return snapshot_; }
  static const char *adcName(unsigned index);
  bool startReconcile();
  bool startPrepareCharge();  // Main+budget checked by caller; CE off, real TS/low ISET, boost PG, >=500 ms TS settling.
  bool startEnableCharge();   // Asserts CE only after prepared supply/real TS/current guards.
  bool startDisableCharging();  // Preempts any enable job; preserves ports and backup.
  bool startPort(Port port, bool enabled);  // J8 automatically prepares/turns off its buck.
  bool startRestorePor();  // Preempts jobs; all outputs off, then config/output FFFF, polarity 0000. GPIO42 retained.
  void service();          // At most one bounded stage per call; no internal poll loop.
  bool busy() const { return result_ == Result::Running; }
  Result result() const { return result_; }
  Operation operation() const { return operation_; }
  const char *error() const { return error_; }
  bool setBackup(bool enabled);  // Arm: current valid main, 10..21 V. Release refuses sole backup.
  bool setLed(bool enabled);
  bool releaseBackupForShutdown();  // Explicit last power action; no I2C/ready/source guard.

 private:
  HardwareSnapshot snapshot_;
  bool monitoring_ = false, reconciled_ = false, prepared_ = false;
  Result result_ = Result::Idle;
  Operation operation_ = Operation::None;
  uint8_t stage_ = 0, portMask_ = 0, expectedInternal_ = 0, expectedExternal_ = 0;
  Port port_ = Port::Vbus;
  bool portEnabled_ = false, pgTiming_ = false;
  uint32_t stageAt_ = 0, operationAt_ = 0, pgAt_ = 0, ceOffAt_ = 0, tsSelectedAt_ = 0;
  char error_[192] = {};
  struct IrqLine {
    BoardHardware *owner = nullptr;
    uint8_t gpio = 0;
    volatile uint32_t falls = 0, rises = 0;
  } irq_[4];  // Internal, external, mux, PD.
  mutable portMUX_TYPE irqMux_ = portMUX_INITIALIZER_UNLOCKED;
  static void ARDUINO_ISR_ATTR onInterrupt(void *argument);
  bool fail(const char *format, ...);
  bool failOperation();
  bool beginOperation(Operation operation, bool preempt = false);
  bool readPair(uint8_t address, uint8_t reg, uint8_t values[2]);
  bool writeRegister(uint8_t address, uint8_t reg, uint8_t value);
  bool readExpander(uint8_t address, ExpanderState &state);
  bool writeControl(uint8_t address, uint8_t value);
  bool verifyControlLow(uint8_t mask);
  bool forceCeLow();
  bool verifyOperational();
  bool verifyPor(uint8_t address);
  bool currentMain() const;
  bool freshInternal() const;
  bool waitPg(bool good, uint32_t timeoutMs = 2000);
  void advance(uint8_t stage);
  void succeed();
};

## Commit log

2026-09-02 Extract TankerVision PDB into a standalone repository
    Self-contained copy of the KiCad 9 power distribution board design previously
    kept under led_pcbs/kicad/tankervision-pdb, together with only the custom
    symbol, footprint, and 3D-model libraries it depends on.
    - hardware/tankervision-pdb: schematic, PCB, and project library tables
    - libraries: 36 symbol libraries, 37 footprint libraries, 34 referenced 3D models
    - docs: existing block-level design documentation, plus a generated schematic
    PDF, BOM, and top/bottom 3D renders for reading without KiCad
    - manufacturing/rev-1_0: as-ordered JLCPCB fabrication and assembly package
    Library tables resolve through ${KIPRJMOD}/../../libraries, so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
    [tankervision-pdb-bom.csv, tankervision-pdb.kicad_pcb, tankervision-pdb.kicad_sch]
2026-09-16 Add ESP32 deployment firmware and board verification records
    [hardware-final.csv, hardware.csv, voltage.csv]
